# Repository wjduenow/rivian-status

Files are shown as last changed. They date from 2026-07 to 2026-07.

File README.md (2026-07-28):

# rivian-status

A small, headless **desk light that shows your Rivian's charge status at a glance.** An
ESP32-S3 polls your Rivian over WiFi (via the unofficial cloud API, read-only) and renders
charge level, charging activity, low-range warnings, and connection health onto an 8-pixel
WS2812 LED strip. No screen — everything (Rivian login incl. MFA, WiFi, settings) is set up in
a browser. It lives behind a 3D-printed enclosure and runs off USB-C.

> **Unofficial & read-only.** Rivian publishes no public API; this reverse-engineers the app's
> cloud GraphQL endpoint for *read-only telemetry* (no vehicle commands, no crypto). Endpoints
> can change without notice. See [`research/`](research/). Not affiliated with Rivian.

---

## What it does

- Reads your Rivian's **charge %, charge target, range, charging state, and plug state** every
  30 s (`getVehicleState`), with exponential backoff on errors.
- Shows it on the **LED meter** (below) — readable across the room, no screen.
- Serves a tiny **web UI** for status, Rivian login (email + password + MFA/OTP), WiFi, and
  settings (low-range threshold, LED brightness, device name).
- Provisions WiFi via a **SoftAP captive portal** on first boot, and supports **wireless OTA**
  firmware updates after that. Only session tokens are stored (never your password).

## Build one from scratch

Start to finish on a brand-new board. The electronics and setup take about half an hour; the case
print is a few hours on its own, so start that first if you're printing one.

**1. Get the parts.** A [Seeed XIAO ESP32-S3](#parts), an 8-pixel WS2812 stick, a ~330 Ω resistor
and a USB-C supply. Full list with links in [Parts](#parts).

> ⚠️ **Plug the external U.FL antenna in.** The XIAO's WiFi is unusable without it, and the
> failure looks exactly like a wrong WiFi password — this wastes an afternoon if you don't know it.

**2. Print the case** and wire the stick to the board — [enclosure](#the-enclosure-case) and
[wiring](#wiring). You can do this after step 3 if you'd rather see it running on the bench first.

**3. Flash it the first time, over USB.** Plug the board into a computer — it shows up as a USB
serial port (`303A:1001`). Pick **one** of these; after this first flash everything is wireless.

Wireless (OTA) can't do the first flash: a factory-fresh board has no bootloader, and OTA replaces
only the app. So the first flash must write the whole layout over USB — which is exactly what the
merged image below is.

<details open>
<summary><b>Option A — flash the prebuilt image (no toolchain)</b></summary>

Download **`firmware-status-full.bin`** from the
[latest release](https://github.com/wjduenow/rivian-status/releases/latest) — a single
full-flash image (bootloader + partition table + app) built and published by CI.

- **In a browser (easiest):** open the [ESP web flasher](https://espressif.github.io/esptool-js/),
  Connect, set the offset to **`0x0`**, choose the file, and Program. Works in Chrome/Edge over
  WebSerial — no install.
- **From a terminal:**
  ```bash
  pip install esptool
  esptool.py --chip esp32s3 write_flash 0x0 firmware-status-full.bin
  ```

The build published this way carries no baked-in secrets, so it comes up in first-boot setup mode
(next step) — and its wireless-flash listener has no password, so keep it on a network you trust.
</details>

<details>
<summary><b>Option B — build from source</b></summary>

Gives you a build you can set an OTA password on, and is the path for development.

```bash
pip install platformio                                    # if you don't have it
git clone https://github.com/wjduenow/rivian-status && cd rivian-status
pio run -e phase3 -t upload --upload-port /dev/ttyACM0    # or COMx / /dev/cu.usbmodem*
```

PlatformIO usually finds the port on its own, so you can drop `--upload-port`. You do **not** need
to create `include/secrets.h` — omitting it is the supported path, and it's how the release image
above is built. See [Building & flashing](#building--flashing-developer-reference) for details.
</details>

**4. Join it to your WiFi.** On first boot it has no credentials, so it raises its own hotspot:

- Join the open network **`rivian-status-setup`** from a phone or laptop.
- A setup page opens (or browse to `http://192.168.4.1/`). Pick your network, enter the password,
  optionally rename the device, and hit **Join**.
- It reboots onto your WiFi. The hotspot disappears.

**5. Sign in to Rivian.** Browse to **`http://rivian-status.local/`** (or its IP — check your
router if `.local` doesn't resolve, which is common on Windows/WSL). Open **Login**, enter your
Rivian email and password, then the MFA code that arrives **by email**. Only the session token is
stored, never your password.

**6. Done — it starts polling.** The meter comes alive within 30 seconds. On **Config**, set your
[mounting orientation](#mounting-orientation) so the meter fills the right way for how you hung it,
plus the low-range threshold and LED brightness. Turn on
[automatic updates](#firmware-updates) and it keeps itself current from then on.

**Troubleshooting the first boot:** if no hotspot appears, the board is probably already joined to
a network (check your router) — or the antenna isn't connected. If the LEDs stay dark, re-check the
data line on `D10` and that the stick's 5 V comes from the `5V` pin, not `3V3`.

## The LED indicator

The **whole strip is one meter**, filled by **charge % ÷ your charge target** (so "full" = you
hit your set charge limit, e.g. 70 %, not 100 %):

| State | Strip shows |
|---|---|
| **Charging** | meter in place; the **closest empty pixel slow-pulses green** (the cell filling), climbing as it charges |
| **Not charging, range OK** | meter: **green** filled up to charge level, **white** for the rest |
| **Not charging, range below your threshold** | **all pixels flash red** (low-range / "go plug in" alert) |
| **At / above target** | **all green** |
| **Link down** (offline / needs login) | **pixel 0 pulses red**, rest off |
| **OTA update running** | whole strip = a **blue progress bar** |

Brightness is adjustable on the config page. The status web page also shows a live **preview**
of the strip below the data table.

### Mounting orientation

The light is a **meter**, and where you can hang it depends on where the power is — so which end
reads as "the top" isn't fixed. The config page lets you say **where the plug comes out**
(bottom / left / top / right, as four little diagrams), and the firmware rotates the meter to
suit. The rule it keeps is:

> the meter always fills toward the **top** when it ends up vertical, and toward the **right**
> when it ends up sideways.

So you can mount it whichever way the outlet allows and it still reads the same. Two extra
settings pin it down completely:

- **Enclosure** — v1's bar runs *across* the case, v2's runs *up-down*, so the same quarter turn
  lands them on different axes. Set once per unit.
- **"Meter fills the wrong way"** — which end of the LED stick is pixel 0 depends on how yours
  was wired, so if the meter drains backwards, tick this and it's fixed.

Changes apply on the next LED frame — no reboot.

## The web interface

Everything is configured in a browser — no app. The device serves three pages (plus a WiFi
setup portal on first boot):

| Status (`/`) | Login (`/login`) | Config (`/config`) |
|:---:|:---:|:---:|
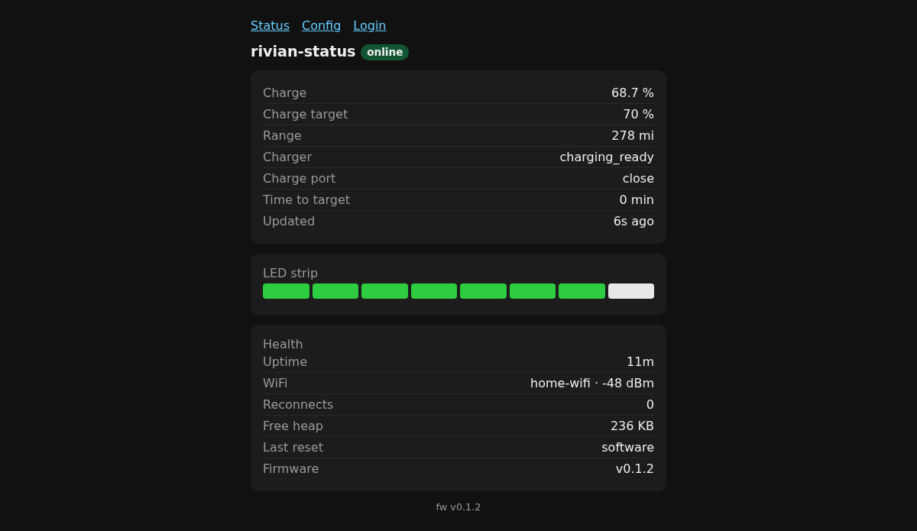
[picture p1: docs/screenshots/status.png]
Status page
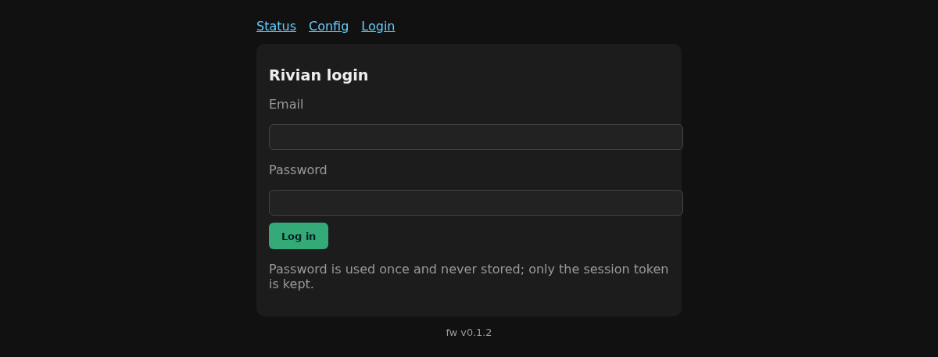
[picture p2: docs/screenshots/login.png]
Login page
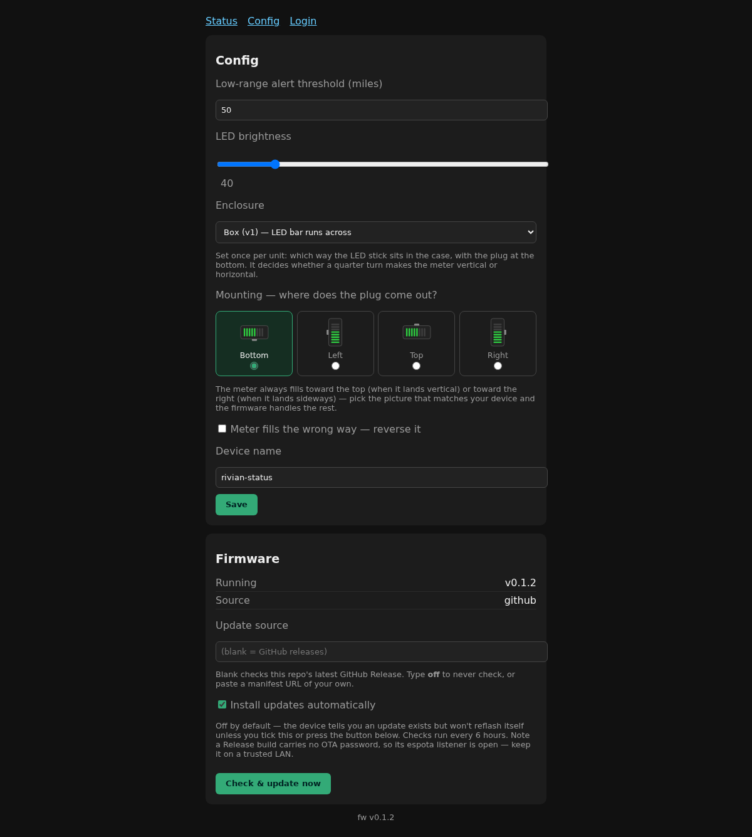
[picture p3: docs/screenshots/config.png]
Config page
|  |  |  |

- **Status** — live charge %, target, range, charger/plug state, a preview of the LED strip, and a
  **health** readout (uptime, signal, WiFi reconnects, free heap, last reset cause, firmware
  version). The health numbers are what tell you whether a unit that's been up for weeks is
  actually healthy or quietly flapping.
- **Login** — one-time Rivian sign-in (email + password, then the emailed MFA code); only the
  session token is stored, never the password.
- **Config** — low-range alert threshold, LED brightness,
  [mounting orientation](#mounting-orientation), device name, and
  [firmware updates](#firmware-updates).

## Firmware updates

The device can update itself. It checks for a newer release at boot and every 6 hours, and either
tells you one is available or installs it — your choice:

- **Update source** — blank checks this repo's latest GitHub Release. Type `off` to never check, or
  paste your own manifest URL.
- **Install updates automatically** — off by default, so out of the box it reports an update but
  waits for you to press **Check & update now**. Tick it and the device keeps itself current
  unattended.

It only ever installs a *strictly newer* version, so it can't flip-flop between builds or downgrade
a hand-flashed development build. A failed or interrupted download leaves the running firmware
untouched — the new image goes into a second flash slot and is only booted once it's complete. The
LED strip shows a blue progress bar while it installs.

> **Note:** release binaries are built without any secrets, which means they carry **no OTA
> password** — the wireless-flash listener on such a unit is unauthenticated. Keep it on a trusted
> network, or build and flash your own binary.

You can still push firmware from a laptop over WiFi at any time (`espota`), which is what
development builds use.

## Parts

| Part | Notes | Link |
|---|---|---|
| **Seeed Studio XIAO ESP32-S3** | the controller. **The included external U.FL antenna must be plugged in** or WiFi fails. | [seeedstudio.com](https://www.seeedstudio.com/XIAO-ESP32S3-p-5627.html) |
| **8-pixel WS2812 / NeoPixel stick** | bare stick, no onboard controller (the XIAO drives it). Measured ~51.5 × 10 mm. | [Adafruit NeoPixel Stick 8](https://www.adafruit.com/product/1426) or any generic 8-bit WS2812 stick |
| **~330 Ω resistor** | series resistor on the LED data line (¼ W, 220–470 Ω all fine) | any |
| **2× M3 × 6 screws** | mount the LED stick to its posts (Ø3.75 holes) | self-tapping / thread-forming M3 |
| **4× M3 × 8 screws** | fasten the lid (countersunk) | self-tapping M3 |
| *(v1)* **USB-C cable + 5 V supply** | permanent power (the strip is powered from USB VBUS) | any |
| *(v2)* **Nekmit Ultra-Thin flat USB-C wall charger** | v2 only — the case press-fits over it and it powers the XIAO over USB-C (via a USB-A→USB-C pigtail). 43.18 × 50.80 × 20.32 mm — the cavity is sized to it. | Nekmit Ultra-Thin flat charger (or any ~43 × 51 × 20 mm flat wall charger) |
| *(v2)* **USB-A → USB-C low-profile pigtail** | v2 only — charger's bottom port → XIAO USB-C, coiled in the skirt | right-angle / 180° ribbon |
| **3D-printed case** | **two versions** — v1 desk box (shell + lid) or v2 wall-charger slip case (case + cover) — see below | print it yourself |
| *(optional)* 470–1000 µF cap | across the strip's 5V↔GND if pixel 0 flickers on power-up | any |

> **Battery note:** as wired, the strip only has power over **USB** (its 5 V comes from the
> XIAO's USB-VBUS pin). Running the strip on battery needs an added boost module — see the
> decision in [`research/battery-power.md`](research/battery-power.md).

## The enclosure (case)

There are **two case versions** — both drive the same board and are parametric (Python +
trimesh, regenerated in the `img23d` conda env). Pick one:

### v1 — desk box (`hardware/status-light/box/`)

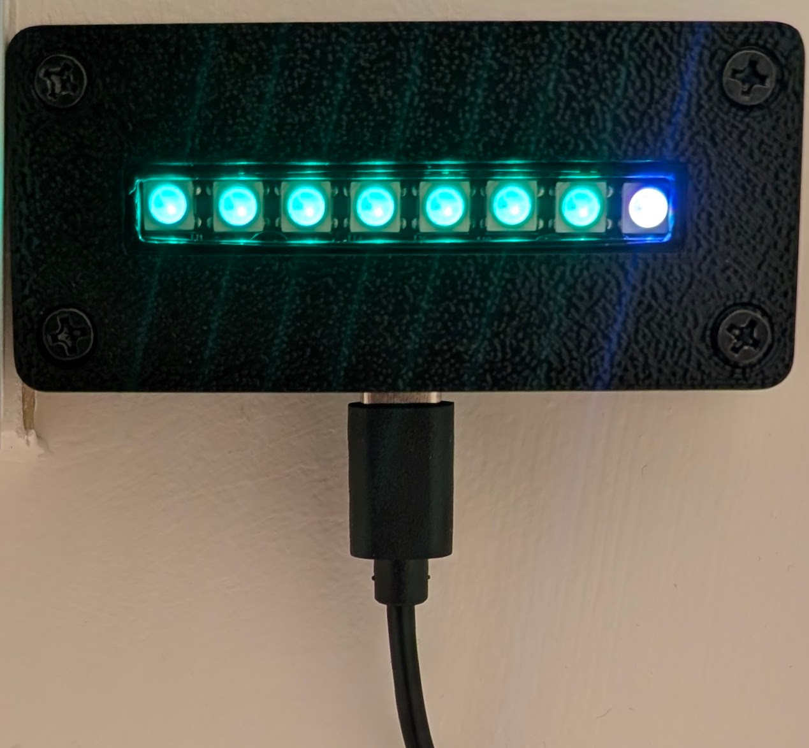
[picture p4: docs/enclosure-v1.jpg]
The v1 enclosure, wall-mounted and running


*A built v1 unit on the wall, live: 7 green + 1 white = one cell short of the charge target.
The plug exits the bottom, so the meter fills left→right.*

A "top-bar" box: the XIAO lies flat on the floor of the shell and the LED stick screws onto two
posts **above** it, LEDs facing up through a window in the lid. USB-C exits the back wall.

Despite the name it wall-mounts nicely too (above) — lay it flat against the wall with the lid
facing out and the back-wall USB-C exit points straight down. That puts the LED bar horizontal;
set **Enclosure = Box (v1)** and **plug = Bottom** on the config page and it reads left→right.

Despite the name it wall-mounts nicely too (above) — lay it flat against the wall with the lid
facing out and the back-wall USB-C exit points straight down. That puts the LED bar horizontal;
set **Enclosure = Box (v1)** and **plug = Bottom** on the config page and it reads left→right.

- **Print these:** [`box/shell.stl`](hardware/status-light/box/shell.stl) +
  [`box/lid.stl`](hardware/status-light/box/lid.stl) — ~75 × 34 × 16 mm.
- Print the lid in **translucent/natural filament** (the LEDs glow through the window), or back
  the window slot with a strip of diffusion film.

### v2 — wall-charger slip case (`hardware/status-light/box-v2/`)

| Front (mounted, live) | Side (profile) |
|:---:|:---:|
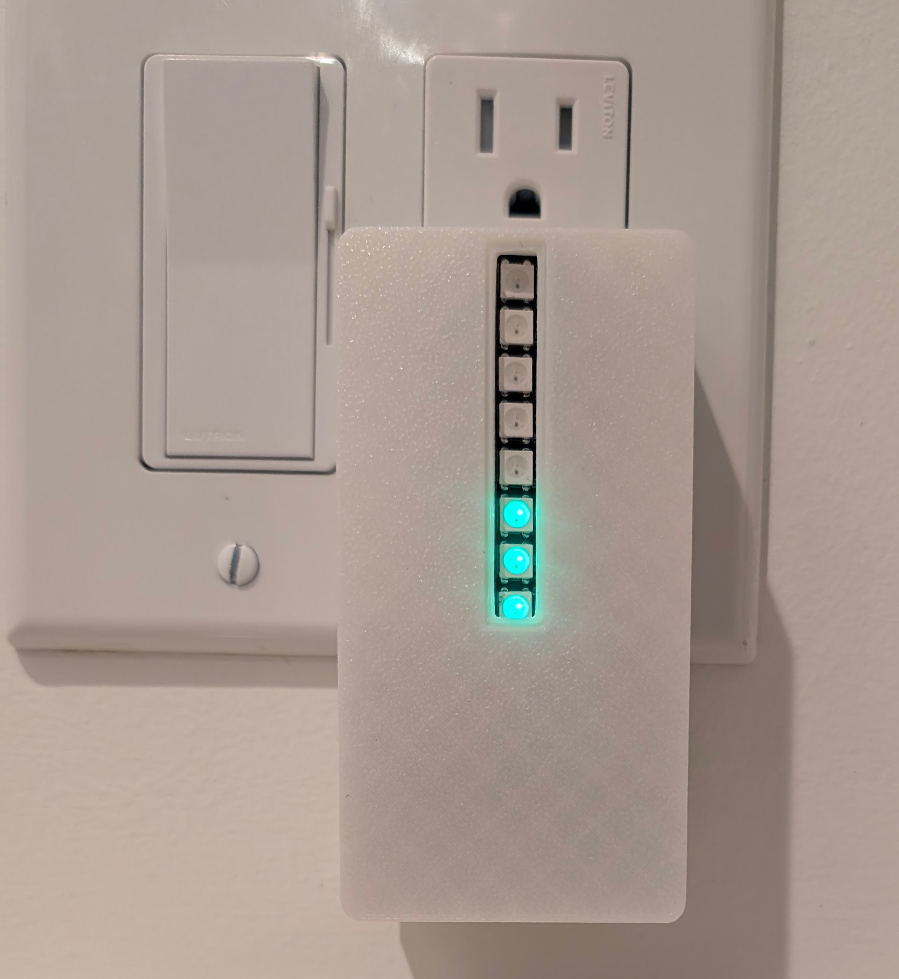
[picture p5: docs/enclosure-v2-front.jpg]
The v2 enclosure, wall-mounted and running
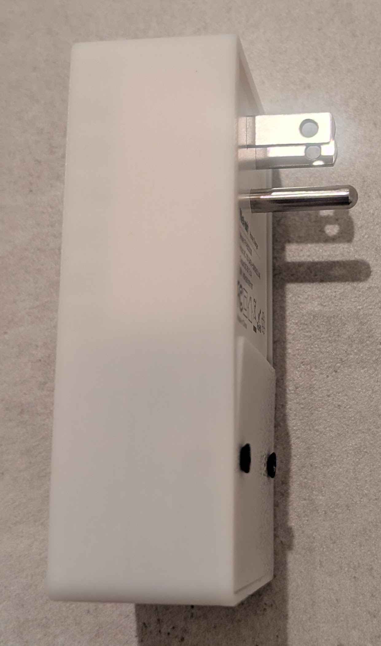
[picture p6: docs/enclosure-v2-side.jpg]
The v2 enclosure in profile
|  |  |

*A built v2 unit press-fit over the wall charger, live — the LED meter shows through the front
window. Right: the side profile, protruding ~29 mm from the wall, with the charger's AC prongs
exiting the open back straight into the outlet.*

A one-piece shell that **press-fits over a Nekmit Ultra-Thin flat USB wall charger** — the
charger is the mechanical *and* power anchor. It plugs into the wall, its AC prongs exit the
**open back**, and the case snaps on over it. The LED stick shows **out the front**; the XIAO
rests in a lower skirt, powered by a **USB-C pigtail** off the charger; a separate screw-on
cover closes the skirt.

- **Print these:** [`box-v2/case.stl`](hardware/status-light/box-v2/case.stl) +
  [`box-v2/cover.stl`](hardware/status-light/box-v2/cover.stl) — protrudes ~29 mm from the wall.
- Full parts list (incl. the charger + pigtail), build steps, and design notes:
  [`hardware/status-light/box-v2/README.md`](hardware/status-light/box-v2/README.md).

Every dimension and how to regenerate the STLs lives in each version's folder; the v1 bill of
dimensions is in [`box/MEASUREMENTS.md`](hardware/status-light/box/MEASUREMENTS.md), the v2
design notes in [`box-v2/NOTES.md`](hardware/status-light/box-v2/NOTES.md), and the shared
board/spec provenance in [`hardware/status-light/board_spec.md`](hardware/status-light/board_spec.md).

## Wiring

Data on **D10 / GPIO9**; power from the XIAO's **`5V`** pin (USB VBUS). Single supply — no
external PSU.

```
   XIAO ESP32-S3                         8-pixel WS2812 stick
   ┌───────[ USB-C ]───────┐
 5V│ ●───────────────────────────────────────►  5V
GND│ ●───────────────────────────────────────►  GND
D10│ ●──[ ~330 Ω ]────────────────────────────►  DIN
   └───────────────────────┘
```

- **DIN** ← `D10` (GPIO9) through the **~330 Ω** series resistor. GPIO9 is a plain output pin
  (not a strapping/USB pin), safe to drive at boot.
- **5V** ← the XIAO **`5V`** pin (USB VBUS passthrough — present only on USB power).
- Keep the LED-stick wires short; they solder to the stick's end pads and run down to the XIAO.
- The external **U.FL antenna** must be connected or WiFi will fail (looks like a bad password).

## Building & flashing (developer reference)

Setting one up for the first time? Use [Build one from scratch](#build-one-from-scratch) above —
this section is the command reference behind it.

Firmware is PlatformIO (Arduino framework). The shipped app is the **`phase3`** env; the others are
diagnostic harnesses.

| env | what it is |
|---|---|
| **`phase3`** | **the appliance** — web UI, poll task, WiFi provisioning, OTA, LEDs |
| `phase3-ota` | same binary, uploaded wirelessly instead of over USB |
| `phase1` / `phase2` | serial-only auth and poll-loop harnesses; these *require* `include/secrets.h` |
| `phase6-ledtest` | standalone WS2812 wiring smoke-test on `D10` |

```bash
pio run -e phase3                                        # build
pio run -e phase3 -t upload --upload-port /dev/ttyACM0   # USB flash (bootloader + table + app)
```
Over the air afterwards — packaged as the **`/ota`** skill:
```bash
OTA_PASSWORD=<pw> pio run -e phase3-ota -t upload --upload-port <device-ip>
```

A full USB flash writes four images; PlatformIO handles the offsets for you
(`0x0` bootloader, `0x8000` partition table, `0xe000` boot_app0, `0x10000` app). OTA replaces only
the last of these.

Each Release publishes two assets, both built by CI (`.github/workflows/firmware.yml`):

| asset | what it is | flash how |
|---|---|---|
| `firmware-status.bin` | the app image (`0x10000`) alone | OTA / `pio run -e phase3-ota`; also what the device pulls for auto-update |
| `firmware-status-full.bin` | all four images merged into one, flashable at `0x0` | a first flash of a blank board over USB (see [Build one from scratch](#build-one-from-scratch)) |

The merged image is only for a cold USB flash — never feed it to OTA, which writes a single app
slot and would flash the bootloader header into it. `manifest.json` deliberately lists only the app
image for exactly that reason.

`include/secrets.h` is **optional** and gitignored (template: `include/secrets.h.example`). `phase3` builds
fine without it — that's how release binaries are built, and it's what keeps the setup portal and
browser login working. It's only needed for the phase1/phase2 serial harnesses, a compile-time WiFi
fallback, or setting an OTA password.

Full flash/serial/OTA details (incl. the WSL usbipd workflow) are in
[`CLAUDE.md`](CLAUDE.md); the design rationale is in
[`plans/01-rivian-status-plan.md`](plans/01-rivian-status-plan.md).

## How the codebase works

An ESP32-S3 firmware in `src/`, split into focused modules. The **poll loop runs in its own
FreeRTOS task**; web handlers run in `loop()`; mutexes guard the shared TLS client and the
telemetry snapshot.

| Module | Responsibility |
|---|---|
| `rivian_api.{h,cpp}` | **The only file that knows Rivian's URLs/headers/GraphQL.** Login (CSRF → login → OTP), `getVehicleState`, session persistence to NVS (reused on boot — no re-login on reflash). |
| `webserver.{h,cpp}` | WebServer:80 (status / login / config pages) **+ the background poll task** + the mutex-guarded status snapshot. Exposes `ledState()` for the LEDs. |
| `leds.{h,cpp}` | The LED **meter** (FastLED on D10/GPIO9). Maps the snapshot → the strip; brightness-capped; blue OTA cue. All Rivian enum reads centralized here. |
| `settings.{h,cpp}` | NVS-backed config: low-range threshold (miles), LED brightness, device name (= hostname), WiFi creds. |
| `net_wifi.{h,cpp}` | WiFi connect + runtime creds + the SoftAP provisioning portal. |
| `net_ota.{h,cpp}` | ArduinoOTA as `<device-name>.local` (wireless updates). |
| `main.cpp` | Orchestration, split by build flag: `PHASE1_SMOKE_TEST` / `PHASE2_POLL_LOOP` / `PHASE3_WEBAPP`. |

**Build envs:** `phase1`/`phase2` are serial-only diagnostic harnesses; **`phase3` is the shipped
app** (incl. LEDs); `phase3-ota` is the wireless upload; `phase6-ledtest` is a standalone WS2812
wiring smoke-test.

## Repo layout

```
src/                firmware modules (above)
plans/01-…md        design source of truth (architecture, LED map, wiring, phasing)
research/           evidence base: the Rivian API protocol + the battery-power decision
hardware/           the 3D-printed enclosure (parametric trimesh CAD + STLs + measurements)
.claude/skills/ota/ the /ota wireless-flash skill
CLAUDE.md           build/flash/OTA commands + the WSL serial workflow + API facts
```

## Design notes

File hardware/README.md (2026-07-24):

# hardware/ — rivian-status physical build

3D-printed enclosure for the headless Rivian status light (XIAO ESP32-S3 + 8-pixel WS2812
stick). Modelled the same way as the sibling **[sonos-nest](../../sonos-nest/hardware)**
project: a Python CSG toolchain (**trimesh + manifold3d**, not OpenSCAD), one shared
`*_params.py` per part, `build_*.py` generators → `.stl`, and a `render_preview.py`. The
toolchain lives in the `img23d` conda env (`conda run -n img23d python build_all.py`).

Per-version dimensions live in each case folder: **[status-light/box/MEASUREMENTS.md](status-light/box/MEASUREMENTS.md)**
(v1, one table) and **[status-light/box-v2/](status-light/box-v2/)** (v2 — numbers in
`case_params.py`, decisions in `NOTES.md`).

| unit | board | enclosures |
|---|---|---|
| **[status-light/](status-light/)** | Seeed XIAO ESP32-S3 + generic 8-bit WS2812 stick | **[box/](status-light/box/)** — v1 top-bar desk enclosure (shell + lid) · **[box-v2/](status-light/box-v2/)** — v2 slip case over a flat wall charger (case + cover) |

## Conventions
- Board outlines/holes come from **verified vendor CAD** (Seeed's STEP); connector
  positions not in the CAD are estimated from photos/datasheets and flagged **⚠️VERIFY**
  in the part's `board_spec.md` — caliper-check before a final print.
- Keep `hardware/` commits **separate from firmware**; this is user-owned work.
- The `img23d` env also has `ezdxf` + `cascadio` (added here) for reading vendor DXF/STEP.

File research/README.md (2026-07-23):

# research/ — Rivian status project evidence base

Primary research gathered 2026-07-17 (Claude Code deep-research + a focused protocol dig).
This is the **raw evidence** behind the design decisions in `plans/01-rivian-status-plan.md`.
When something in the plan needs justification — or when the unofficial API breaks and you
need to re-derive it — start here.

> **Everything about Rivian's API is unofficial and reverse-engineered.** Rivian publishes no
> public developer API. Treat every endpoint/header/field below as "true as of 2026-07-17,
> may change without notice." The maintained community client (`bretterer/rivian-python-client`)
> is the closest thing to a spec — diff against its upstream if things stop working.

## Contents

- **`rivian-cloud-api-protocol.md`** — the concrete protocol: endpoints, the 4-step auth
  handshake (CSRF → login → OTP → re-CSRF), exact GraphQL mutations/queries, the header matrix,
  telemetry fields, TLS/cert facts, and ESP32 feasibility notes. *This is the file you code
  against.* Sourced from `bretterer/rivian-python-client` `main` + RivDocs.
- **`deep-research-report.md`** — the broader survey: verified findings (with confidence +
  vote tallies), refuted claims (things that sound true but failed verification), open
  questions, and the full source list with quality ratings. Answers "what are ALL the options
  and which did we rule out and why."
- **`battery-power.md`** — decision (2026-07-22, deep-research): can the LED strip run on
  battery? No mainstream ESP32-S3 board has a battery-fed 5 V boost, so it's XIAO + an external
  PowerBoost module if pursued; always-on WiFi runtime is short, so the shipped appliance stays
  USB-powered. Board comparison + runtime math + wiring inside.

## The decision, in one paragraph

Use Rivian's **cloud GraphQL App API** directly from the ESP32-S3 (read-only telemetry).
It's **ruled IN**: the endpoint is behind AWS CloudFront (no bot/JS challenge), auth is plain
JSON POSTs, and with no display the ESP32 has ample heap for TLS. **Local/BLE is ruled OUT**
(needs cloud-bootstrapped ECDH phone-key enrollment + HMAC signing, no turnkey ESP32 project,
and probably no live charge telemetry anyway). Read-only means **no crypto at all** — just
login + `getVehicleState`. See the plan for the full build.

## Key facts future sessions keep needing

- **Endpoint:** `POST https://rivian.com/api/gql/gateway/graphql`
- **Auth:** CreateCSRFToken → Login → (LoginWithOTP if MFA) → `userSessionToken`. **No refresh
  mutation** — on expiry, re-run CreateCSRFToken reusing `u-sess`; full re-login only as last resort.
- **Headers:** base (`User-Agent: RivianApp/707...`, `Apollographql-Client-Name:
  com.rivian.ios.consumer-apollo-ios`, self-gen `dc-cid`) + `Csrf-Token`/`A-Sess`/`U-Sess`
  per the matrix. **No `dc-sess` header exists** (older-API conflation).
- **Telemetry fields:** `batteryLevel`, `chargerState`, `chargePortState`, `distanceToEmpty`
  — each returns `{timeStamp, value}`. Request only the subset you need.
- **TLS:** Amazon Root CA 1, **pin the root not the leaf** (leaf rotates ~200 days).
- **Cadence:** poll 30 s, exponential backoff capped at 900 s. API rate-limits (`RATE_LIMIT` code).
- **UNCONFIRMED:** `distanceToEmpty` units (km vs miles) and exact token lifetimes. Verify units
  live before trusting the low-range threshold.

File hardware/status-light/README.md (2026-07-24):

# status-light — the `rivian-status` enclosures

The headless Rivian charge/range light: a **Seeed XIAO ESP32-S3** driving an **8-pixel
WS2812 stick** that shows the pixels out the front. There are **two enclosure versions** —
both drive the same board, and both are generated by the same Python CSG toolchain.

| version | form factor | printed parts | size |
|---|---|---|---|
| **[box/](box/)** (v1) | desk-standing "top-bar" box; pixels face **up** out a lid window | `shell.stl` + `lid.stl` | 75.3 × 34.3 × **16** mm |
| **[box-v2/](box-v2/)** (v2) | **slip case that press-fits over a Nekmit flat USB wall charger**; pixels face **out** the front | `case.stl` + `cover.stl` | protrudes **29.1** mm from the wall |

### v1 — `box/` (desk light)
A two-part screwed box. The XIAO lies flat on the floor; the WS2812 stick is stacked **above**
it on two posts with the LEDs facing **up** through a window in the lid. USB-C exits the back
wall; the U.FL antenna coils inside. See **[box/README.md](box/README.md)**; every v1 dimension
is tabulated in **[box/MEASUREMENTS.md](box/MEASUREMENTS.md)**.

### v2 — `box-v2/` (wall-charger case)
A one-piece slip shell that **press-fits over a Nekmit Ultra-Thin flat wall charger** — the
charger is the mechanical *and* electrical anchor (it plugs into the wall; AC prongs exit the
**open back**; an inward snap lip retains it). The WS2812 stick mounts **vertically** on the
front behind the window, screwed from the open back into hidden bosses. The XIAO rests flat on
the lower **skirt** floor, powered by a USB-A→USB-C pigtail off the charger. The skirt's
wall-facing back is a **separate screw-on cover** (so the body prints open-backed, no supports).
See **[box-v2/README.md](box-v2/README.md)** for the full parts list + build, and
**[box-v2/NOTES.md](box-v2/NOTES.md)** for the design decisions + rationale. Two printed parts.

## Shared references
| | |
|---|---|
| **[board_spec.md](board_spec.md)** | every XIAO dimension **both** boxes use + where it came from (the "no mounting holes" finding lives here) |
| **[ref/](ref/)** | vendor CAD: `XIAO-ESP32S3 v2.step` + the measured proof renders |

## Conventions (shared with `../../../sonos-nest/hardware`)
- Python CSG toolchain (trimesh + manifold3d), the `img23d` conda env — **not** OpenSCAD.
- Every dimension lives in a `*_params.py`; builders `assert` their own clearances.
- Board numbers come from vendor CAD; anything estimated is flagged **⚠️VERIFY** and
  caliper-checked before a final print.
- Keep `hardware/` commits separate from firmware — this is user-owned mechanical work.

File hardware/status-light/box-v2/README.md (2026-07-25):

# box-v2 — wall-charger slip case

A **v2 enclosure** for the rivian-status light that ditches the desk box and instead
**press-fits over a Nekmit Ultra-Thin flat USB wall charger**. The charger is the mechanical
*and* electrical anchor: it plugs into the wall, its AC prongs protrude out the **open back**,
and this shell slides on from behind and snaps in place. **Two printed parts** (`case` +
skirt-back `cover`) + a stick-on diffuser film.

```
conda run -n img23d python build_all.py      # -> case.stl + cover.stl
conda run -n img23d python render_preview.py # -> render_preview.png
```

Same toolchain as `../box` (trimesh CSG, mm, every number provenance-commented in
`case_params.py`, clearances **ASSERTED** in `build_case.check_clearances()` so an illegal
edit fails loudly instead of writing a broken STL).

**Design decisions + rationale** (why it's ~30 mm deep, why hidden M3 forces that, the skirt /
cover choices): [`NOTES.md`](NOTES.md). The shared XIAO board spec is `../board_spec.md`.

## Parts (bill of materials)
| # | part | notes |
|---|---|---|
| 1 | **USB-C wall charger — Nekmit Ultra-Thin flat, 45.1 × 51.6 × 20.32 mm** | the mechanical + power anchor the case slips over; powers the XIAO over USB-C |
| 2 | **Case** — `case.stl` (FDM, front-face-down) | main body; press-fits over the charger |
| 3 | **Cover** — `cover.stl` (FDM, flat) | screw-on skirt back |
| 1 | Seeed **XIAO ESP32-S3** | rests flat on the skirt floor |
| 1 | **8-px WS2812 stick** (v1 board, 51.5 × 10 mm) | vertical, behind the front window |
| 1 | **USB-A → USB-C low-profile pigtail** | charger's bottom port → XIAO USB-C (skirt loop) |
| 2 | **M3 × 5** self-tapping screws | hold the LED stick (hidden, from the open back) |
| 2 | **M3 × 8** self-tapping screws | hold the cover into its side-wall bosses |
| 1 | diffuser film / thin acrylic strip | over the window (outer rebate) |

## Frame
`+X` width (horizontal on the wall) · `+Y` up (vertical) · `+Z` out (wall → room).
Origin: X centred on the charger; `y=0` at the charger's bottom face; `z=0` at the open back rim.

## Layout (locked with the user)
- **8-px WS2812 stick, re-used from v1**, mounted **vertically** on the front interior face.
  It drops into a front **pocket** (domes → `+Z` out the window) and is **screwed** through its
  two Ø3.75 holes to bosses molded off the front wall. The **M3 self-tappers go in from the
  OPEN BACK** — heads hidden from the front, sitting in a relief gap behind the PCB — and their
  pilots thread up into the **solid 3.2 mm front wall** (not thin necked walls), capped by
  **1.6 mm** of wall so the pilots stay hidden from the front. Recommended screw: **M3×5**
  (~3.6 mm thread engagement). The window ledge is a second, backup stop.
- **XIAO ESP32-S3 rests flat on the skirt floor** (no tray) — gravity + the wires to the stick
  hold it; the USB-A→USB-C pigtail from the charger's bottom port loops down to it. The stick
  pocket, charger cavity and skirt share one open interior, so wiring routes freely between them.
- **Skirt back = a separate screw-on `cover`.** The main body prints **fully open-backed** (no
  supports in a blind pocket); the cover is a **plain plate** that drops into a flush rebate and
  is held by **2 M3×8** self-tappers, countersunk on the wall-facing face, into gusseted
  side-wall bosses. It closes the XIAO bay and stops the board falling out the back.
- **Retention:** an inward **snap lip** around the back rim catches behind the charger's rear
  edge (blueprint §3).

## Key numbers (all in `case_params.py`)
| | mm | source |
|---|---|---|
| Charger (W×H×D) | 45.1 × 51.6 × 20.32 | W×H calipered 2026-07-24; D blueprint |
| Slip-fit cavity | 45.70 × 52.20 × 20.72 | +0.6/+0.6/+0.4 |
| **Outer envelope (W×H×D)** | **50.1 × 97.6 × 30.1** | derived |
| Protrusion from wall | **30.1** | derived |
| Wall / front | 2.2 / 3.2 | choice (front thickened to hide the screw-post pilots) |
| Skirt (interior height) | 41.0 | +24 for the USB cable/plug (17 → 29 → 41) |
| Window (X×Y) | 5.95 × 50.95 | over the emitter run |
| Stick screws | 2 × **M3×5** from the back, hidden | Ø5.0 bosses, ~3.6 mm grip |
| Head-relief gap / dome recess | 2.6 / 0.6 | behind the PCB / below the window |
| Skirt-back cover | plain plate, 2 × **M3×8** | flush rebate, gusseted bosses |
| Snap lip (inward × tall) | 1.2 × 2.0 | blueprint 1.0–1.5 |

## Deliberate deviations from the blueprint (documented, not accidents)
1. **Depth grows to ~30.1 mm** (blueprint said ~20.7 + wall). The blueprint assumed the
   charger touches the front wall, but the vertical LED stick sits **in front of** the charger
   (3.0 mm) **and is back-screwed**, needing a **2.6 mm relief gap** behind it for the hidden
   screw heads. So internal depth = charger + head gap + stick, plus a **3.2 mm front wall**
   (thickened from 2.2 to keep the screw-post pilots hidden).
2. **Skirt is 41 mm** (blueprint 15–18; grown 17 → 29 → 41 in two +12 bumps). Sized to clear the
   **USB cable/plug** hanging off the charger's bottom port. The XIAO lies flat on the floor
   (~5.5 mm tall) and doesn't set the height.

## Print orientation
Print **front-face-down** on the bed: the window is a flat bottom layer, the walls rise, and
the **whole back (charger region *and* skirt) ends up open on top** — no bridging over the big
front face, and **no supports in a blind skirt pocket** (that's why the skirt back is a separate
cover). The rear snap lip becomes a small inward overhang at the top; a chamfer or a few support
lines clean it up. The `cover` prints flat, csk-face up.

## Open items / next iteration
- **Stick thread engagement is modest (~3.6 mm).** Fine for a ~3 g static part, but if you
  want more grip, raise `DOME_RECESS` (lets the boss get taller, at a little more depth) or
  step to a longer screw. Print a boss test coupon — FDM self-tap holes want tuning.
- **XIAO is unretained sideways** — it just rests on the floor (per your call). Gravity + the
  stick wires + the back cover hold it; add a dab of foam if it rattles in transit.
- **Cover top edge** is now held only by the **2 side screws** + the flush rebate (the
  tongue-under-tab retention was removed as unhelpful). If the top ever bows outward, add a
  third screw or a small central boss rather than reintroducing the tabs.
- **First flash.** No external USB-C port by default — first flash the XIAO out of the case,
  then it's OTA over WiFi. Set `USB_SERVICE_SLOT = True` to cut a cabled-access slot in the
  skirt bottom.
- **Verify against the real charger + snap lip fit** with a print (FDM slip-fits and snap lips
  want a test coupon before committing the whole part).
- The **snap lip is a simple rectangular step** — tune `LIP_IN`/`LIP_H`/`LIP_CHAMFER` after a
  test fit.

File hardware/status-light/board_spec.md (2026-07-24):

# XIAO ESP32-S3 — mechanical spec (as used by the enclosures)

Every XIAO number the enclosures rely on, and exactly where it came from. Shared by **both**
case versions — `box/` (v1) and `box-v2/` (v2). Same discipline as
`../../../sonos-nest/hardware`: CAD-verified numbers are plain; anything estimated is
flagged **⚠️VERIFY**. Values are baked into each version's `case_params.py` — this file is
the paper trail.

## Sources (Seeed official)

Pulled from the Seeed wiki resource list for the XIAO ESP32-S3
(`wiki.seeedstudio.com/xiao_esp32s3_getting_started`):

| File | What | Kept where |
|---|---|---|
| `seeed-studio-xiao-esp32s3-3d_model.zip` → **`XIAO-ESP32S3 v2.step`** | vendor 3D CAD — the authority for outline, thickness, connector positions | committed to **`ref/`** |
| `XIAO_ESP32S3_v1.1_Dimensioning.dxf`, `TOP.dxf` | 2D fab drawings — cross-check + the bottom-copper view | render in **`ref/xiao_footprint_bottom.png`** |

The STEP was converted to a mesh with `cascadio` (STEP→glTF) and measured in `trimesh`,
in **mm**. In the STEP's own frame: X = board length, Z = board width, Y = thickness.
`ref/xiao_ortho_measured.png` is the orthographic proof render those numbers came off.

## The board (measured off the STEP)

| Dimension | Value | Provenance |
|---|---|---|
| PCB length (USB-C ↔ antenna) | **21.0 mm** | STEP `SOLID` X-span 20.955 |
| PCB width | **17.8 mm** | STEP `SOLID` Z-span 17.780 |
| PCB thickness | **1.25 mm** | STEP `SOLID` Y-span −0.25…1.00 (Seeed spec: 1.2) |
| Bottom side | **flat** — no tall components | STEP: overall Y-min = PCB back face |
| Tallest top component | **4.21 mm** above PCB back (the USB-C shell) | STEP `CHAMFER9` |
| RF shield height | 3.00 mm above PCB back | STEP `Shield` |

### USB-C (on the +X short end)
| | Value | Provenance |
|---|---|---|
| Overhang past the PCB edge | **1.53 mm** | STEP: connector X-max 13.809 vs PCB 12.282 |
| Shell width | **8.94 mm** | STEP Z-span |
| Aperture height | **3.26 mm** | STEP Y-span 4.20 minus the lip |
| Aperture centre above PCB **back** face | **2.36 mm** | STEP Y-centre 2.11, PCB back −0.25 |
| Centred on the board width? | **yes** | STEP USB Z-centre −6.12 ≈ PCB Z-centre −6.11 |

### U.FL external-antenna jack (on **top**, at the −X / antenna end)
CLAUDE.md is explicit: **this antenna must stay plugged in or WiFi dies**, so the box has
to leave room for the mated plug and let the pigtail escape.
| | Value | Provenance |
|---|---|---|
| Along the board length, from centre | **−6.95 mm** (toward −X) | STEP `U.FL-R-SMT` X-centre |
| Height above the PCB **top** face | **1.25 mm** (bare jack; a mated plug adds ~3) | STEP Y-top 2.25 − PCB top 1.00 |
| Offset from the width centreline | **4.73 mm** | STEP Z-centre −10.84 vs −6.11 |

## ⚠️ The XIAO has **no screw mounting holes**

Confirmed two ways: the STEP has no mounting bores (only the connectors + a shield can),
and the bottom-copper DXF (`ref/xiao_footprint_bottom.png`) shows only the two 7-pin
castellated rows plus **two Ø0.6 tooling holes** — no M2/M3 pads. XIAO boards are meant to
be retained by their pins or by the host enclosure.

**Consequence for the box:** the board is **not screwed down**. It drops onto four corner
standoffs inside a rib pocket, is pinned in X by the USB-C sitting in its port, and is
clamped from above by two pads on the lid. Wires are **hand-soldered directly to the pads**
(user-confirmed — no header, so the board back stays flat and lies flush on the standoffs).

## LED stick — measured by the user (generic bare 8-bit stick)

Not in any vendor CAD, so these are **caliper values** the user measured off the real part:

| Dimension | Value |
|---|---|
| Length | **51.5 mm** |
| Width (short edge) | **10 mm** |
| Total thickness incl. LEDs | **3.0 mm** → PCB **1.6** + domes **1.4** |
| Lit span (first→last LED centre) | **45 mm** (emitter extent ≈ 50 mm) |
| Mounting holes | **2**, Ø **3.75 mm**, at **±13.0 mm** along the length (26 mm apart) |
| LED square (emitter) | **4.75 mm** |
| Hole offset from the LED row | **4.5 mm** to one long edge (measured) |

From the board photo the holes are off to one long edge (by the Cx caps / pad column),
~¼ and ¾ along the length, **4.5 mm** off the LED row (`LED_HOLE_DY`). The box **screws
the stick down** onto two posts through those Ø3.75 holes (2× M3). The lid window spans the
full **50 mm emitter extent** (lit span + one emitter), and the LEDs sit **2 mm below the
case top** (`LED_BELOW_TOP`) so they read near the surface of the window slot.

## Note — USB-C exits the back wall

Because the stick is stacked over the board and the lid is screwed on, the board lies
front-to-back under the stick and **USB-C exits the back (+Y) wall, centred and proud**
(see `box/README.md` "Layout note"). An end-exit variant is a one-param change but needs
the board recessed ~5 mm.

The **U.FL antenna stays inside** the box by default (`ANT_EXIT = False`) — the jack keeps
its plug clearance and the pigtail coils in the open floor. Flip `ANT_EXIT = True` for a
front-wall exit slot if the in-box antenna underperforms.

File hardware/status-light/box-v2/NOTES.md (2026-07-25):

# box-v2 — design notes & decisions (for future sessions)

Why the v2 case is shaped the way it is. The *numbers* live in `case_params.py` (provenance-
commented) and the *build* in `README.md`; this file is the **reasoning** — the non-obvious
trade-offs, the decisions locked with the user, and the things a future session would otherwise
have to re-derive. Read alongside the repo `CLAUDE.md` and `../board_spec.md`.

## What it is (one line)
A one-piece slip shell that press-fits over a **Nekmit Ultra-Thin flat wall charger**
(45.1 × 51.6 × 20.32 mm; W×H calipered 2026-07-24, D from blueprint). The charger is the
mechanical **and** electrical anchor: it plugs
into the wall, AC prongs exit the **open back**, an inward snap lip retains it. LED stick shows
out the front; XIAO + pigtail live in a lower skirt; skirt back is a separate screw-on cover.

## Decisions locked with the user (don't silently revisit)
- **8-px WS2812 stick, re-used from v1** — *not* the "16-LED array" the original blueprint text
  mentioned. The firmware pixel map is 8 (plan §7).
- **Stick mounted VERTICALLY** on the front (charger face is portrait 51.6 tall; the 51.5 mm
  stick fits the height, not the 45.1 width).
- **XIAO rests flat on the skirt floor** — no tray/standoffs. Gravity + the wires to the stick
  hold it; the cover stops it falling out the back.
- **Skirt back = a SEPARATE screw-on cover** (not an integral wall) — so the body prints open-
  backed with no supports in a blind pocket.
- **Stick retention = hidden M3 screws from the open back** (user: "hidden back, but use M3").
  The front wall is **3.2 mm** and each pilot is capped by **1.6 mm** of solid wall so the posts
  don't show through the front (user asked to hide them; front thickened to suit).
- **Cover = plain screw-held plate.** An earlier tongue-under-corner-tab top retention was
  **removed** (user: "not helpful"); the 2 side screws + flush rebate hold the cover.

## The depth story (why it protrudes ~30 mm, not the blueprint's ~20.7)
The blueprint assumed the charger touches the front wall. It doesn't, for two stacked reasons —
**this is the #1 thing to understand before touching the Z stack:**
1. The vertical LED stick (3.0 mm: 1.6 PCB + 1.4 domes) sits **in front of** the charger.
2. The stick is **back-screwed**, so there's a **head-relief gap** (`STRIP_HEAD_RELIEF`, 2.6 mm)
   between the charger face and the stick's PCB back for the hidden screw heads.

So internal depth = charger (20.72 slip) + relief (2.6) + stick (3.0) → front wall interior at
~26.9, and with a **3.2 mm front wall** the outer face is ~30.1 mm. (`FRONT_T` was thickened
2.2 → 3.2 to keep the screw-post pilots hidden — see below.) `D_IN`/`OUT_D` in `case_params.py`
derive from exactly this chain.

### Why hidden-M3 forces the depth (the front-sandwich problem)
The stick is sandwiched between the charger (behind) and the window (front), so a screw boss
must go on **one** side and that dictates depth:
- **Hidden-back screw** ⟹ the boss it threads into must be on the **front-wall** side, and the
  screw head lands on the **charger** side → needs the relief gap (adds depth). We root the boss
  by boring its **pilot up into the solid 2.2 mm front wall** (not a thin necked pin through the
  Ø3.75 hole — that would leave ~0.5 mm walls and strip). Engagement ~3.4 mm → **M3×5**.
- A robust Ø5.5 boss *behind* the stick would instead need **front-face screws** (visible) and
  a pocket floor — even more depth. Rejected.
- Net: any positive stick screw here costs depth; hidden-back is the least-visible option and
  what the user chose. Thread grip is modest but fine for a ~3 g static part.

`DOME_RECESS` (0.6 mm) lets the LEDs sit a hair below the window (also a light baffle) and buys
a common screw length; raise it if you want more thread engagement (at a little more depth).

**Hiding the screw posts:** the blind pilots are bored up into the front wall and stop
`PILOT_WALL_MIN` short of the outer face. At the old 0.8 mm cap the posts showed through the
front, so `PILOT_WALL_MIN` is now **1.6 mm** and `FRONT_T` was raised 2.2 → 3.2 to keep ~3.6 mm
of thread engagement (cap = `PILOT_WALL_MIN` regardless of `FRONT_T`, so both had to move). Net
cost is ~1 mm more protrusion.

## XIAO in the skirt
- Lies **flat on the floor** (21 × 17.8 footprint on the X-Z plane, only ~5.5 mm tall in Y).
- **Skirt height (`SKIRT_H`) is 41 mm** — grown in two +12 bumps to make room for the
  **USB cable/plug** hanging off the charger's bottom port (user's call). It is NOT floored by
  the XIAO, which lies flat (~5.5 mm tall); don't shrink it below ~15 or the plug collides.
  (History: 24 mm when the XIAO had a front-wall tray → 17 once it moved to the floor → 29 → 41
  for cable room.)
- The stick pocket, charger cavity, and skirt share **one open interior** — wiring routes freely
  (no dedicated slot needed).
- **Not retained sideways** (user's call) — add foam if it rattles in transit. A molded snap tab
  is the clean follow-up if ever wanted.

## Skirt back cover
- Flush rebate + **2× M3×8** into **gusseted** side-wall bosses (posts alone can't root over the
  open cavity — they must merge with / rib to the perimeter walls).
- **Plain plate, no top retention.** An earlier version stepped the cover's top corners to a
  half-thickness tongue that tucked under two body tabs. The user found the tabs unhelpful, so
  they're **removed** — the 2 side screws + the flush rebate hold the cover. If the top ever
  bows out, add a third screw or a small central boss rather than bringing the tabs back.

## Print orientation
**Front-face-down** on the bed: window = flat bottom layer; walls rise; the **whole back (charger
region + skirt) is open at the top** → no bridge over the big front face, no supports in a blind
pocket (that's the whole reason the skirt back is a separate cover). The snap lip becomes a small
inward overhang at the top; chamfer or a few support lines clean it up. The `cover` prints flat.
(Removing the top tabs also removed the last small top-edge overhangs — nothing bridges now.)

## Charger caveat (verify before a final print)
The physical Nekmit is **dual USB-A output**; the XIAO is fed by a **USB-A→USB-C pigtail**. The
BOM lists it as the "USB-C wall charger" (the power the board sees is USB-C) but the cavity is
sized to the **Nekmit's body** (45.1 × 51.6 × 20.32). **If you swap to a charger with a native
USB-C port or different dimensions, re-measure and update `CHG_W/H/D`** — the whole slip fit,
snap lip, and skirt derive from those three numbers.

## Before committing a full print
1. **Print a test coupon first** — the slip fit (`FIT_W/H/D`), the snap lip (`LIP_*`), and the
   stick boss self-tap all want a cheap coupon before a ~multi-hour full print. FDM holes/fits
   print tight. Confirm the 1.6 mm pilot cap fully hides the posts in your filament while here.
2. Diffuser film over the window (outer rebate) or print in translucent filament.
3. First XIAO flash is done **out of the case** (then OTA over WiFi); set
   `USB_SERVICE_SLOT = True` if you want a cabled-access slot in the skirt bottom.

## Toolchain (same as `../box`)
`img23d` conda env, trimesh CSG. `case_params.py` (single source of truth, clearances ASSERTED
in `build_case.check_clearances()`) → `build_case.py` + `build_cover.py` → `case.stl` +
`cover.stl`. `render_preview.py` (2×2 overview).
`conda run -n img23d python build_all.py`.

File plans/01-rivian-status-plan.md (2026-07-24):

# 01 — rivian-status: a headless ESP32-S3 Rivian charge/range status light

**Board:** **Seeed Studio XIAO ESP32-S3** (ESP32-S3R8, 8 MB PSRAM / 8 MB flash, USB-C, no
display). **LEDs:** an **8-pixel WS2812/NeoPixel stick**, USB-powered from the board's `5V`
pin — no external supply (see §7 for the pixel map, wiring, and power budget).
**Goal:** an always-on desk/wall appliance that polls the owner's Rivian over WiFi and shows,
via lights: is it plugged in, is it charging, roughly how full, **whether current range is
below a configurable threshold**, and whether the link to Rivian is healthy. All setup —
Rivian login (incl. MFA), WiFi, and the range threshold — happens in a browser. No screen.

This is a **fresh standalone repo**. It does not need the Sonos control stack. It borrows a
few *patterns* (not the whole core) from the `sonos-nest` repo's plan 04 "sonos-button"
(the headless, browser-configured, one-appliance model): WiFi provisioning via SoftAP
captive portal, an embedded config web page, NVS-persisted settings, and ArduinoOTA.

> **Everything about Rivian's API here is unofficial and reverse-engineered.** Rivian
> publishes no public API. Endpoints, headers, and field names can change without notice.
> Centralize them (§8) so a break is a one-file fix. Sources are cited in §11.

---

## 1. Decisions (settled)

| Question | Decision |
|---|---|
| Data path | **Rivian cloud GraphQL App API** (the app's own endpoint). Ruled IN by research. |
| Local / BLE | **Ruled OUT.** Needs cloud-bootstrapped ECDH secp256r1 phone-key enrollment + HMAC signing; no turnkey ESP32 project; BLE likely won't even expose live charge telemetry. |
| Access mode | **Read-only telemetry.** No vehicle commands → **no HMAC / phone-key / BLE crypto** needed at all. |
| Auth | Rivian account email + password, MFA/OTP when enabled. Entered once via the web page. |
| Credential storage | **Store only session tokens + VIN in NVS. Never persist the password.** |
| Config surface | Small embedded web page (login, status, WiFi, range threshold). Single `WebServer`, one port. |
| WiFi provisioning | `secrets.h`/NVS first, **SoftAP captive portal fallback** (same as sonos-button plan 04). |
| Telemetry transport | **Polling `getVehicleState` query**, not the WebSocket subscription (WS is heavier on an MCU for no benefit here). |
| Poll cadence | **30 s**, exponential backoff on error capped at **900 s**. |
| Primary alert | **current range `< X`**, where X is configurable in the web page. |
| Board | **Seeed Studio XIAO ESP32-S3** (ESP32-S3R8, 8 MB PSRAM, USB-C). |
| LED hardware | **8-pixel WS2812/NeoPixel stick**, one pixel per indicator (§7). Data on `D10`/GPIO9; powered from the `5V` (USB VBUS) pin; single-supply via a firmware brightness cap. |

### Open decisions (defer, noted where relevant)
- ~~`distanceToEmpty` units~~ — **CONFIRMED 2026-07-21 (Phase 1, live vehicle): the API field is
  in KILOMETERS; the US app displays miles** (391 km API ≈ 244 mi app). Firmware converts km→mi;
  the web-page threshold X is entered in **miles** (§6).
- Whether the low-range light is **charging-aware** (steady = low & not charging, pulse = low
  but charging) or dead simple (low is low). Data for both is free. Lean charging-aware; decide
  in the LED phase (§10 phase 6).

---

## 2. Why the cloud path is feasible on the ESP32 (the research verdict)

- **AWS CloudFront, not Cloudflare.** `rivian.com/api/gql/...` returns `via: CloudFront` /
  `x-amz-cf-*` — no `cf-ray`, no JS challenge, no cookie wall. CloudFront fronting a GraphQL
  API does not interpose a browser challenge on POSTs. None of the open-source clients
  implement any anti-bot workaround → a plain `WiFiClientSecure` POST is accepted. *This was
  the biggest kill-risk; it's gone.*
- **No JS/browser behavior anywhere.** Every step is a JSON POST. A headless Home Assistant
  integration runs this fine — proof point.
- **Heap is comfortable** because there's **no display**. The TLS-heap warnings in the
  research (≈37 KB/TLS connection; mbedTLS leaks ~1.3–2 KB/handshake with a custom cert
  bundle; BLE+HTTPS together starves heap) were all about a chip *sharing* SRAM with LVGL +
  audio. A display-less, BLE-less Rivian board has the whole chip. **Mitigations we adopt
  anyway:** pin the **root** CA (not a big custom bundle — this also sidesteps the
  #3119 leak, which was specific to the custom-bundle path); never init BLE.
- **On "persistent TLS session":** don't over-invest here. At a 30 s cadence, CloudFront's
  idle timeout will very likely close a held-open socket between polls, so you'd reconnect most
  cycles regardless — and with no display, a per-poll handshake (~37 KB, freed after) is
  affordable. **Budget for per-poll reconnects**; if handshake cost ever bites, reach for TLS
  **session resumption / session tickets** rather than literally holding the socket open. Watch
  heap over a multi-day run to confirm no slow leak (see the watchdog note in §8).
- **Read-only ⇒ no crypto.** Vehicle *commands* need an HMAC signed by an enrolled phone
  keypair; we do none. Only login + `getVehicleState` are required.

---

## 3. Endpoints

```
GRAPHQL_GATEWAY   = https://rivian.com/api/gql/gateway/graphql     # auth + getUserInfo + getVehicleState
GRAPHQL_CHARGING  = https://rivian.com/api/gql/chrg/user/graphql   # (live charging session — not needed for v1)
GRAPHQL_WEBSOCKET = wss://api.rivian.com/gql-consumer-subscriptions/graphql   # (subscription path — NOT used)
```
One POST per call: JSON body `{ operationName, query, variables }`.

**Base headers on every gateway call:**
```
User-Agent: RivianApp/707 CFNetwork/1237 Darwin/20.4.0
Accept: application/json
Content-Type: application/json
Apollographql-Client-Name: com.rivian.ios.consumer-apollo-ios
dc-cid: m-ios-<uuid>        # client-generated device-correlation id (NOT a server token); synthesize once, PERSIST to NVS, reuse forever
```
> Header-identity note: bretterer's client sends the iOS identity above; RivDocs documents the
> Android identity `com.rivian.android.consumer`. Both are reported working. Pick one, keep it
> consistent. There is **no `dc-sess` header** in the real client — `dc-cid` is the only device field.
> Generate the `dc-cid` UUID once on first boot with a real entropy source (`esp_random()`),
> write it to NVS, and reuse it across reboots — a churning `dc-cid` looks like a new device
> every restart.

**TLS:** hosts serve an **Amazon-issued** cert (`CN=rivian.com`, issuer *Amazon RSA 2048 M04*)
via CloudFront, chaining to **Amazon Root CA 1**. Embed that root CA PEM in `WiFiClientSecure`
and **pin the root, not the leaf** (leaf rotates ~200 days). Standard RSA-2048; the Python
clients use default verification with no pinning, so normal CA verification suffices.

---

## 4. Auth handshake (4 steps, all POST to `GRAPHQL_GATEWAY`)

### Step 1 — CSRF token
Headers: base only.
```graphql
mutation CreateCSRFToken { createCsrfToken { __typename csrfToken appSessionToken } }
```
→ store `csrfToken` (as `Csrf-Token`) and `appSessionToken` (as `A-Sess`).

### Step 2 — Login
Headers: base + `Csrf-Token` + `A-Sess`.
```graphql
mutation Login($email: String!, $password: String!) {
  login(email: $email, password: $password) {
    __typename
    ... on MobileLoginResponse    { accessToken refreshToken userSessionToken }
    ... on MobileMFALoginResponse { otpToken }
  }
}
```
- If `data.login` has `userSessionToken` → **done**, it becomes `U-Sess`.
- If `data.login` has only `otpToken` → MFA required; Rivian texts a code. Go to Step 3.

### Step 3 — OTP completion (only when MFA)
Headers: base + `Csrf-Token` + `A-Sess`.
```graphql
mutation LoginWithOTP($email: String!, $otpCode: String!, $otpToken: String!) {
  loginWithOTP(email: $email, otpCode: $otpCode, otpToken: $otpToken) {
    __typename
    ... on MobileLoginResponse { accessToken refreshToken userSessionToken }
  }
}
```
→ store `userSessionToken` as `U-Sess`.

### Step 4 — "Refresh": there is no refresh mutation
The maintained client captures `refreshToken` but never sends it. On an **expired-token
error**, it simply **re-runs `CreateCSRFToken` (reusing the still-valid `U-Sess`)** and retries.
Our token model:
1. Persist **`U-Sess`** (+ VIN) in NVS. `Csrf-Token`/`A-Sess` are **re-minted each boot** by
   CreateCSRFToken, so they don't need persisting — only `U-Sess` does.
2. On boot, **reuse the persisted `U-Sess`**: mint a fresh CSRF/A-Sess, then call a read to
   verify. If it works, skip login/OTP entirely.
3. On an auth error → mint a new CSRF token, retry. **Silent, unattended.**
4. Only if that also fails → clear the dead `U-Sess`, surface "re-login needed" (link-health LED
   + web page), owner re-enters password/OTP once.

> **✅ Implemented & verified (Phase 1, 2026-07-21):** `rivian_api` persists `U-Sess` to NVS on
> login/OTP success and reuses it on the next boot. Confirmed live — a board reset reused a
> ~40-min-old `U-Sess` via fresh CSRF and pulled vehicle state with **no login and no OTP**. This
> is what keeps MFA off the critical path for a screenless appliance.

### Header matrix
| Call | Csrf-Token | A-Sess | U-Sess |
|---|---|---|---|
| CreateCSRFToken | – | – | – |
| Login / LoginWithOTP | ✓ | ✓ | – |
| getUserInfo / getVehicleState | – | ✓ | ✓ |

(`accessToken` is captured but the gateway authenticates via `A-Sess`/`U-Sess`, not a bearer.)

---

## 5. Telemetry (polling `getVehicleState`)

**Once at boot:** `getUserInfo` → `data.currentUser.vehicles[].{id, vin, name}` → cache **both the
`id` and the VIN**.
```graphql
query getUserInfo { currentUser { vehicles { id vin name } } }
```
> **Phase 1 correction (2026-07-21, live):** `vehicleState(id:)` takes the vehicle **`id`**
> (e.g. `01-244090061`), **NOT the VIN** — passing the VIN returns `NOT_FOUND`. (`name` can be
> `null`.) The protocol dig guessed "VIN"; reality is the `id`. Firmware keys on `id`.

**Every 30 s:** request only the fields we use (each returns `{ timeStamp value }`):
```graphql
query GetVehicleState($vehicleID: String!) {   # pass the vehicle `id`, NOT the VIN (see above)
  vehicleState(id: $vehicleID) {
    batteryLevel     { timeStamp value } # charge % — FLOAT, e.g. 59.700001 (parse as float!)
    batteryLimit     { timeStamp value } # charge TARGET % (e.g. 70 or 100) — where charging stops
    chargerState     { timeStamp value } # e.g. "charging_active" (Phase 1)
    chargePortState  { timeStamp value } # e.g. "open" (Phase 1)
    distanceToEmpty  { timeStamp value } # RANGE in KILOMETERS (§6); firmware converts to miles
    timeToEndOfCharge{ timeStamp value } # minutes to reach batteryLimit (int)
  }
}
```
`batteryLimit` reflects the owner's charge cap — e.g. `70` when set for battery longevity, `100`
for a full charge (confirmed live 2026-07-21: limit 70 while SoC 61%). "Charge complete" is best
read as `batteryLevel ≈ batteryLimit`, not `chargerState` alone.
Response is a few hundred bytes → parse with ArduinoJson in a small buffer. **Do not** request
the default ~100-field property set.

**Cadence & limits:** poll 30 s. The API rate-limits (`RATE_LIMIT` error code; no published
number). On any error, exponential backoff `min(30 * 2^errCount, 900)` seconds. Reset on success.

---

## 6. Low-range alert (the primary feature)

```
rangeMiles = distanceToEmpty.value / 1.60934        // API value is KM (confirmed §1); convert
lowRange   = rangeMiles < rangeThresholdX           // X in MILES, from NVS, set via web page
```
- **X is configurable** on the web page (a number field, **in miles**), persisted to NVS — same
  idea as sonos-button's configurable volume. No reflash to change it.
- **✅ Units confirmed (Phase 1, 2026-07-21):** the raw `distanceToEmpty` field is **kilometers**;
  the US app shows **miles** (live check: 391 km API ≈ 244 mi app). Firmware divides by 1.60934
  and the web page labels/accepts the threshold in miles. (If an owner ever wants km, that's a
  display-unit toggle later — the raw field stays km.)
- **Range, not SoC %, is the right signal** — it already bakes in temperature/load/conditions,
  so "range < X" answers "can I make my trip." (SoC % is still shown for the fullness LED.)
- **Note:** the API also exposes a vehicle-reported `rangeThreshold` field alongside
  `distanceToEmpty` (protocol dig §3). We use our own NVS-configured X (clearer, and decoupled
  from whatever the vehicle uses it for), but the field is there if it ever proves useful.

---

## 7. LEDs (locked: 8-pixel WS2812 stick on the XIAO ESP32-S3)

**Hardware (settled).** An **8-pixel WS2812/NeoPixel stick** (bare, no onboard controller —
the XIAO *is* the controller). The whole strip is a **single meter** (not one-pixel-per-role):
it fills by **SoC ÷ charge-target** (`batteryLevel / batteryLimit`), so "full" = you've hit
your set charge limit, not 100 %.

### Behavior (implemented in `leds.cpp render()`)
| State | Strip |
|---|---|
| **Link down** (offline / needs re-auth / no telemetry yet) | **pixel 0 pulses red**, rest off |
| **Up + charging** (`chargerState == "charging_active"`) | meter stays in place (green filled + white empty); the **closest empty pixel slow-pulses green** (the cell filling), climbing as SoC rises |
| **Up + not charging + range < threshold** (`distanceToEmpty` mi < `rangeThresholdMiles`) | **all pixels flash red together** (low-range alert) |
| **Up + not charging + range OK** | **meter: green filled + white empty** (fill = SoC/target; all green once at target) |
| **OTA push in progress** | whole strip = a **blue progress bar** (`otaProgress()`) |

Brightness-capped (`-DLED_BRIGHTNESS`, single-supply off USB VBUS). "Charging" is `charging_active`
only; `charging_ready` (plugged-idle) reads as not-charging.

**Mounting orientation.** The device is a meter and the outlet decides how it hangs, so which
physical end reads as "the top" isn't fixed — an outlet can put it at **0/90/180/270°**.

*The invariant:* the meter always fills toward **screen-up** when the stick lands vertical and
toward **screen-right** when it lands horizontal. The firmware compensates; the reading never
changes. That's what makes this one setting instead of a per-pattern concern.

*Asked as "where's the plug?"* — `/config` shows four SVG cards (Bottom / Left / Top / Right),
each drawing the case outline with the lead on that edge plus the cells shaded the way they'll
fill. That's a thing you can see without reasoning about LED wiring. Stored as
`Settings::ledRotation()` (NVS `led_rot`, 0/90/180/270, snapped to the nearest quarter turn; it
defaults off the older `led_flip` bool so an already-flipped unit lands on 180°).

**Plug position alone is not enough** — two more facts are needed, and neither is derivable, so
both are settings rather than assumptions:

| Setting | NVS | Why it can't be derived |
|---|---|---|
| `ledStickVertical0()` — is the stick vertical with the plug at the bottom? | `led_vert0` | **Differs per enclosure.** v2's wall case holds the stick vertically on the charger's portrait face; **v1's box mounts board-flat to the wall, LEDs facing out, so its stick runs horizontal** — plug-at-bottom there reads left→right. Default `false` (v1, the unit in service). |
| `ledInverted()` — is the meter filling the wrong way? | `led_inv` | Which physical end **pixel 0** is depends on how that unit's stick was wired. Exposed as a "meter fills the wrong way — reverse it" checkbox: one glance at the device settles it, no guessing in firmware. |

**Defaults confirmed on the real v1 unit** (photo in the root README): wall-mounted with the
USB-C lead exiting the **bottom**, the meter fills **left→right** — 7 green + 1 white at 7/8 of
target. That is exactly what `led_vert0=false, led_inv=false, led_rot=0` predicts, so the
"pixel 0 is at the left end at the reference mounting" assumption is settled for v1, not assumed.

*The math, all in `Settings`:* everything falls out of **`pixel0Dir()`** — where pixel 0 points
once mounted, as clockwise degrees off screen-up. It starts at *down* (vertical stick) or *left*
(horizontal), `+180` if inverted, `+ rotation` for the mounting. Then `ledVertical()` = pixel 0
points up/down, and `ledFlipped()` = pixel 0 points up/right (the two cases where the meter would
otherwise fill down or left). Verified exhaustively: the fill lands up-when-vertical /
right-when-horizontal for **all 16** enclosure × invert × rotation combinations.

*Implementation:* `render()` always draws in **logical** order (index 0 = the "fill from" end) and
`applyOrientation()` reverses the buffer afterwards when `Settings::ledFlipped()`. One remap covers
every pattern in the table above, including the OTA bar. Applies on the next frame, no reboot.

The status page's 8-segment preview switches **axis** to match (`.meter.col`, a `column-reverse`
so logical 0 sits at the bottom) — it never reverses, because the physical meter doesn't either.

**Observed `chargerState` values (growing):** `"charging_active"` (pushing power),
`"charging_ready"` (plugged, idle), `"charging_complete"` (finished / at target — reads as
not-charging, so at/above target it shows the full green meter). Still needed: the unplugged /
fault values — capture by observing those states. `chargePortState` (`"open"`/`"close"`) is ambiguous and
currently unused. The one enum read lives in `leds.cpp` (`sCharging`) for a one-line fix.

### Wiring (single-supply, USB-powered — no external PSU)
```
        XIAO ESP32-S3                      8-pixel WS2812 stick
   ┌───────[ USB-C ]───────┐
5V │ ●───────────────────────────────────► 5V   (VIN)
GND│ ●───────────────────────────────────► GND
3V3│ ●   (do NOT use — 700 mA reg,               ▲
   │      shared with the ESP32)                 │ common ground
D10│ ●──[ ~330 Ω ]──────────────────────► DIN    │
   │  ...                                         │
   └───────────────────────────────────┘         │
                                                  │
   (optional) 470–1000 µF cap across the stick's 5V↔GND if pixel 0 flickers on power-up
```
- **DIN** ← `D10` (GPIO9) through a **~330 Ω** series resistor. GPIO9 is a plain IO — not a
  strapping/USB pin (avoid GPIO0/3/19/20/45/46), so it's safe to drive at boot. `D10` is the
  board's default SPI MOSI, which is free here (no SPI peripheral used).
- **5V** (VIN) ← the XIAO **`5V`** pin — the USB VBUS passthrough (top pin by the USB-C jack).
  Present only when USB-powered; if the board is ever run from a LiPo, this pin is dead and the
  strip loses power (not our case — this is a mains-USB appliance).
- **3.3 V data into a 5 V strip** is marginally under WS2812 spec but reliable at this short
  length; if pixel 0 ever glitches, add a **74AHCT125** shifter on DIN (fallback, not baseline).

### Power budget (why single-supply is safe)
8 px × ~60 mA at full white ≈ **480 mA** — that *would* exceed the safe USB headroom (a plain
port gives ~500 mA and the ESP32's WiFi TX already spikes ~300–350 mA). The fix is a **firmware
brightness cap** (`FastLED.setBrightness(~48/255)` default) plus status colors that are rarely
white: real draw lands in the low tens of mA, comfortably inside budget. **The brightness cap is
the load-bearing mitigation** — it's a hard default in the `leds` module, not a user setting.

---

## 8. Firmware shape (fresh PlatformIO / Arduino ESP32-S3)

Suggested module split (keeps the unofficial-API surface centralized):
- `rivian_api.{h,cpp}` — **the only file that knows Rivian's URLs, headers, and GraphQL
  strings.** Exposes `login()`, `completeOtp()`, `ensureAuth()`, `fetchVin()`, `pollState()`;
  returns a small `VehicleStatus { batteryLevel, chargerState, plugged, rangeRaw, ts }`.
- `net_wifi` — ✅ built. Hostname (= device name, set before STA transition), NVS-or-`secrets.h`
  creds, runtime `apply()`, and the SoftAP captive portal. Lifted from `sonos-nest/src/core/net/`.
- `net_ota` — ✅ built. ArduinoOTA as `<device name>.local`, optional `OTA_PASSWORD`; `otaHandle()`
  serviced in `loop()`. Verified with a live wireless update.
- `settings` — ✅ built (NVS `cfg`): `rangeThresholdMiles`, `deviceName` (sanitized hostname),
  WiFi creds. Tokens/`dc-cid` live in `rivian_api`'s own NVS. **Enable NVS encryption** so tokens
  + WiFi pass aren't at rest in cleartext (see §11).
- `webserver` — SoftAP captive-portal WiFi join + the config/status/login page (§9).
- `leds` — the state machine mapping `VehicleStatus` + link health → the 8-pixel map (§7).
  Uses **`fastled/FastLED`** on `-DLED_DATA_PIN=9` (D10/GPIO9); enforces the brightness-cap
  default (§7 power budget) as a hard floor, not a user knob.
- `main` — boot: wifi (or SoftAP) → ensureAuth → fetchVin → poll loop (30 s) → drive LEDs;
  host `ArduinoOTA.handle()` in `loop()`.

**Concurrency — run the poll in its own FreeRTOS task (the default, not the fallback).** A
`getVehicleState` POST can take seconds, and a dead socket can block up to its timeout; if the
poll and `WebServer` share one cooperative loop, the config page goes unresponsive during every
poll/backoff. Give the poll its own task, share `VehicleStatus` + link-health behind a small
mutex (mirrors sonos-nest's `stateLock()`), and set **explicit socket/TLS timeouts** so a
stalled poll can't wedge the UI.

**Uptime hygiene (24/7 appliance):**
- **WiFi supervisor — ✅ BUILT.** Ported from sonos-nest `f58573d`, which fixed an
  "unresponsive after 2–3 days" report. Before this, `Net::connect()` ran **once at boot** and
  nothing ever re-checked the link: a router reboot / DHCP renewal / AP roam left the box
  alive-but-wedged with the web UI *and* OTA dead — unfixable without pulling the USB. Now:
  - `Net::connect()` sets `setAutoReconnect(true)` + `setSleep(false)` (mains-powered box; modem
    sleep invites AP-driven drops).
  - `sleepSupervised()` in `webserver.cpp` replaces the poll task's blind `vTaskDelay`s: it
    sleeps in 500 ms slices, re-kicks `Net::reconnect()` every 10 s while the link is down, and
    **returns early on recovery so the backoff is cleared**. That last part is rivian-status
    -specific — sonos-nest polls every 3 s with no backoff, whereas this task's backoff caps at
    **900 s**, so a straight port would have left the light stale and red for up to 15 min after
    the network returned.
  - On recovery it **re-advertises mDNS + ArduinoOTA** (`readvertise()` / `otaRestart()`). Both
    bind to the netif that died; without this a healed device is reachable by IP but invisible
    to `.local`, which is exactly how the `/ota` skill discovers it.
  - A **Health card** on the status page (uptime / SSID+RSSI / reconnect count / free heap) —
    a climbing reconnect count says the link is really flapping; a resetting uptime says
    something is rebooting the box instead.
- **Credential survival — ✅ BUILT** (sonos-nest `37669fd`). `Net::connect()` persists
  compiled-in `WIFI_SSID`/`WIFI_PASS` to NVS on a successful connect when NVS is empty.
  Without it, a device that had only ever connected via `secrets.h` drops into the setup portal
  the moment it's flashed with a **CI Release binary** (which ships no `secrets.h` by design).
- **Task watchdog + heap floor** — still TODO. Monitor free heap and reboot on a floor breach;
  cheap insurance against a slow TLS-stack leak over long uptime. The Health card now surfaces
  the heap number this would act on.

---

## 9. Web page (single `WebServer`, one port)

Unlike sonos-nest's sleep-machine (which needed a second port to dodge `WebServer`'s broken
*upload* body parser), we only do **small form POSTs**, so `arg("...")` works — **one port**.

- **`/` status** — plug/charge state, SoC %, current range (with confirmed unit), the low-range
  threshold X, and link health. Read-only view so a screenless board is still inspectable.
- **`/login`** — two-phase form. Submit email+password → server runs CreateCSRFToken + Login.
  If MFA, reveal an **OTP field** → submit → LoginWithOTP. On success, store tokens+VIN, show
  "connected." **Password is never persisted.** Also the **re-auth surface** when a token dies.
- **`/config`** — set **range threshold X** (+ unit once known), poll cadence (optional),
  device name. Persist to NVS.
- **`/wifi`** — the SoftAP captive-portal join page (creds → NVS), plus a recovery entry point.

Reach it at the device IP or an mDNS hostname (set a `DEVICE_HOSTNAME`, e.g. `rivian-status`).

**Security posture of the config surface (accepted, but explicit — see §11):** the page is
**plain HTTP with no auth**. The Rivian **password crosses the local link in cleartext** on
`/login` (and SoftAP is often open), and anyone on the LAN can view status or hit the re-auth
surface. Acceptable for a hobby appliance on a trusted network; surface a short warning on the
`/login` page and keep the account-token-bearing device off untrusted networks.

---

## 10. Phasing

1. **✅ DONE (2026-07-21) — Auth smoke-test (headless, serial).** Hard-code creds in `secrets.h`;
   run CSRF→Login→(OTP)→getUserInfo→getVehicleState once; print the raw response. *Proved the
   CloudFront/TLS/header path works against the real account.* Phase 1 deliverables (all met):
   - **Confirm `distanceToEmpty` units** (km vs miles) against the app display.
   - **Record the raw enum string values** of `chargerState` and `chargePortState` across
     states (unplugged · plugged-idle · charging · complete · fault) — §7's LED state machine
     can't be built without them, and they only appear on the live account.
   - **MFA path:** if the account has MFA on, the serial test needs an **OTP-over-serial input**
     step (Rivian texts the code at login); build that in, or note Phase 1 assumes MFA-off for
     the first pass.
   - Generate + persist the `dc-cid` (§3) so it's stable from the very first real call.
2. **✅ DONE — Poll loop + range check.** 30 s poll, `min(30·2^n,900)` backoff, `lowRange`
   (km→mi). Added `batteryLimit`/`timeToEndOfCharge`. Serial-only. Session persisted/reused.

   *(LEDs moved to the end — the 8-pixel stick hasn't arrived; the software phases below don't
   need it, so do them first and finish with the light.)*
3. **✅ DONE — Web page.** Single `WebServer:80` + a FreeRTOS poll task (mutex-guarded TLS +
   snapshot, per §8). `/` live status (auto-refresh, link-health pill), `/login` (two-phase
   email/password→OTP, password never stored), `/config` (threshold miles + device name → NVS),
   mDNS `<name>.local`. Verified live from a browser: status renders real telemetry, config
   persists. (Browser login→OTP path uses the same `rivian_api` calls proven in Phase 1; not
   re-exercised live to conserve OTPs.) **Device name = DHCP hostname + mDNS + AP name** (single
   source, `Settings`); `setHostname` set before the STA transition (arduino-esp32 quirk, per
   sonos-nest); a rename **reboots** so all three update together — verified live.
4. **✅ DONE — WiFi provisioning.** `net_wifi` module (borrowed from sonos-nest wifi.cpp +
   portal.cpp): tries NVS creds then `secrets.h`; on failure raises a **SoftAP captive portal**
   (open AP `<name>-setup`, wildcard DNS, scan-list join page) that also sets the device name,
   then reboots into STA. Creds persist to NVS. (Portal path compile-verified + mirrors the proven
   sonos-nest code; not exercised live since valid creds are present — would need a creds wipe.)
5. **✅ DONE — OTA.** `net_ota` (ArduinoOTA) advertises as `<device name>.local`, optional
   `OTA_PASSWORD` from `secrets.h`. `phase3-ota` env does espota uploads
   (`OTA_PASSWORD=<pw> pio run -e phase3-ota -t upload`). **Verified live: a full firmware update
   over WiFi (authenticated) succeeded and the device rebooted into it — no USB.** (Enclosure is
   physical, still to do; link-health behavior lands with the LEDs.)
6. **LEDs (last — needs the 8-pixel stick).** Wire the `leds` FreeRTOS state machine to real
   status on the locked stick (§7): FastLED on D10/GPIO9, the per-pixel map, brightness-cap
   default, and the fullness bar + `batteryLimit` mark. Finish the `chargerState`/`chargePortState`
   enum set (idle/unplugged/complete/fault) in this phase; `charging_active`/`open` captured.

---

## 11. Risks & caveats
- **Unofficial API, no stability contract** — RivDocs states it "could change or break at any
  moment." Centralize URLs/headers/queries in `rivian_api.cpp`.
- **Token lifetime undocumented** (community reports: hours-to-days). Design is reactive — never
  pre-refresh; handle the expiry error (re-CSRF, then re-login as last resort).
- **Rate limits undocumented** — 30 s poll + capped backoff is the proven-safe cadence.
- **`distanceToEmpty` units unconfirmed** — verify in Phase 1/2 before trusting the threshold.
- **App-identity header** (iOS vs Android) — both reported working; not resolvable without live
  testing on the account.
- **MFA at re-login needs the owner** — unavoidable for a screenless board; the web page is the
  entry point, and the reactive token model makes it rare.
- **Token-at-rest** — a stored `u-sess` is a live credential granting full account read (and the
  account can command the vehicle). NVS is unencrypted by default, so a flash dump leaks it.
  **Mitigation adopted:** enable NVS encryption (§8); never persist the password regardless.
- **Cleartext config surface** — the web page is plain HTTP with no auth: the Rivian password
  crosses the local link in the clear on `/login`, and anyone on the LAN can view status or
  trigger re-auth (§9). Accepted for a trusted-network hobby appliance; keep it off untrusted
  networks and warn on the login page.
- **Persistent-TLS assumption corrected** — don't rely on a held-open socket surviving the 30 s
  idle gap; budget for per-poll handshakes (fine with no display) and use session resumption if
  cost bites (§2). Watch heap over a multi-day run; a task watchdog reboots on a heap-floor
  breach (§8).

---

## Sources
Deep-research + protocol dig, 2026-07-17:
- `bretterer/rivian-python-client` — the maintained client the HACS integration uses (endpoints,
  header set, auth mutations, `getVehicleState`): https://github.com/bretterer/rivian-python-client
- `bretterer/home-assistant-rivian` — cadence (30 s), backoff (cap 900 s), re-CSRF-on-expiry:
  https://github.com/bretterer/home-assistant-rivian
- RivDocs (kaedenb) — endpoint map, auth flow, BLE enrollment (why local is ruled out):
  https://rivian-api.kaedenb.org/
- `the-mace/rivian-python-api` — corroborating cloud-only client:
  https://github.com/the-mace/rivian-python-api
- ESP32 TLS-heap references (mitigation rationale): esp32_https_server #11, Mbed-TLS #3119,
  arduino-esp32 #2175.
- Smartcar (managed OAuth alternative, not chosen): https://smartcar.com/brand/rivian

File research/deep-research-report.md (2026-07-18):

# Deep-research report — connecting an ESP32 to a Rivian for charge/range status

Question: *Options to connect an ESP32 board to a Rivian vehicle to display/monitor charging
state (charge %, charging status, range, etc.) — cloud API vs local/BLE, auth, libraries,
feasibility on ESP32.*

Method (2026-07-17): fan-out web search across 6 angles → 22 sources fetched → 72 claims
extracted → 25 verified with 3-vote adversarial verification (need 2/3 to kill) → 18 confirmed,
7 refuted → synthesized. For the concrete protocol, see `rivian-cloud-api-protocol.md`.

## Summary

Two programmatic paths exist. The realistic one is **Rivian's cloud GraphQL App API**:
authenticate with a Rivian account (CSRF → email/password login → OTP/MFA when enabled, yielding
`a-sess`/`csrf-token`/`u-sess` session headers) and POST GraphQL to
`https://rivian.com/api/gql/gateway/graphql`, where `GetVehicleState` / `getLiveSessionData`
return state of charge, charger state, power/voltage/amps, time remaining, range added, and
estimated range. A **local BLE API** also exists (same interface the app + keyfob use, direct to
the vehicle, no internet) — but it is **not plug-and-play**: it requires cloud-bootstrapped
phone-key enrollment (registering an ECDH secp256r1 public key server-side) plus cryptographic
pairing before a device gains command authority. Tesla has a working ESP32-BLE project
(`yoziru/esphome-tesla-ble`); **no equivalent turnkey ESP32 Rivian-BLE project exists.** For a
monitor, the cloud API is the fastest route; a managed layer (**Smartcar**) wraps Rivian behind
OAuth owner-consent as an alternative. All Rivian APIs here are unofficial and can change.

## Confirmed findings (high confidence unless noted)

1. **Cloud GraphQL App API is the feasible ESP32 path** — POST to
   `https://rivian.com/api/gql/gateway/graphql`; how the app, community integrations, and Python
   clients all access data. *(3-0)* Sources: RivDocs, home-assistant-rivian,
   bretterer/rivian-python-client, the-mace/rivian-python-api, PyPI.

2. **Auth is a multi-step cloud token flow** — `CreateCSRFToken` (→ csrfToken + appSessionToken)
   → `Login` (email+password) → if MFA, `LoginWithOTP`/`loginWithOTPV2` (OTP) → `userSessionToken`;
   requests carry `Csrf-Token`, `A-Sess`, `U-Sess`. OTP is texted when MFA is on. *(3-0)*

3. **The cloud API returns exactly the needed telemetry** — SoC (`soc`/`batteryLevel`), charger
   state (`vehicleChargerState`/`chargerState`), power/current/voltage, time remaining, energy
   added, range added, estimated range — via `GetVehicleState` + `getLiveSessionData`. HA exposes
   these as ~118 sensor entities. *(3-0)*

4. **A local BLE API exists** — same controls as the app API but sent directly to the vehicle
   over BLE, no internet. Python BLE support lives in `bretterer/rivian-python-client`
   (`src/rivian/ble.py`). *(3-0)*

5. **BLE is NOT plug-and-play** — phone-key enrollment is bootstrapped through a cloud web API
   (`EnrollPhone` GraphQL mutation registering an ECDH secp256r1 public key), required before BLE
   pairing; subsequent commands are HMAC-signed locally. This is the main hurdle for a local
   ESP32 implementation, and no turnkey Rivian-BLE ESP32 project was found. *(3-0)*

6. **Even "BLE-based" HA integrations use BLE only for one-time pairing**, then do all ongoing
   monitoring via the Rivian cloud ("After pairing, Bluetooth is no longer required"). So for a
   monitor-only ESP32, the cloud API alone suffices — no BLE needed. *(3-0)*

7. **Smartcar is a managed cloud alternative** — third-party API covering Rivian EV charging
   management, location, mileage, via OAuth owner-consent (owner logs in with their Rivian
   account); Smartcar handles credentials so passwords don't hit your servers. Cleaner auth for
   an ESP32 (standard OAuth) at the cost of a third-party, likely-paid dependency. *(3-0)*

8. **Tesla precedent shows direct ESP32↔vehicle BLE is possible in principle** —
   `yoziru/esphome-tesla-ble` controls charging + reads battery status over BLE, no cloud
   (Tesla's VCSEC always advertises over BLE). But it's Tesla-specific; Rivian would need its own
   enrollment/crypto ported. *(3-0)* Note: verifiers **refuted** the specific claim that the
   Tesla BLE project reads live charge-rate/energy telemetry (1-2) — treat as control+basic-status
   precedent, not confirmed live telemetry.

## Refuted claims (sounded true, failed verification — recorded so we don't re-adopt them)

- "Live charging state is delivered via an App API 'Parallax' streaming domain with fields like
  `charging.session.status`/`soc_slider`/`time_estimation`." **0-3** — not supported; the real
  fields are the `vehicleState`/live-session ones above.
- "Rivian data is accessed *exclusively* through the cloud (no local/BLE path)." **0-3** — false;
  a BLE path does exist (finding 4), it's just hard.
- "Auth uses token-based auth where the password is never stored / only encrypted tokens
  returned." **0-3** — overstated marketing framing from a secondary source; the actual flow is
  as in finding 2.
- "The rivian-python-client is cloud-only with no BLE transport." **0-3** — false; it ships
  `ble.py`.
- (A the-mace-sourced restatement of the auth claim scored 1-2, but the same claim from stronger
  sources confirmed 3-0 — see finding 2.)

## Open questions (still unresolved after research)

1. **Token/refresh lifetime** and whether an ESP32 can silently refresh without re-triggering an
   OTP to the owner's phone (critical for an unattended monitor). *Partially answered by the
   protocol dig: there's no refresh mutation; re-run CreateCSRFToken on expiry reusing `u-sess`;
   lifetimes remain undocumented.*
2. Is the full Rivian **BLE pairing + HMAC command-signing** handshake documented well enough to
   port to ESP32 C++, and has anyone built a non-app Rivian BLE client? *(Not for our read-only
   monitor — moot unless control is ever wanted.)*
3. Does the ESP32 TLS/HTTPS stack + heap comfortably handle the endpoint? *Answered: yes,
   especially with no display — see protocol doc §5.*
4. Smartcar pricing/rate-limit tier for a single-vehicle hobby project, and whether its OAuth
   consent redirect fits a headless device.

## Caveats

All Rivian API details come from unofficial, reverse-engineered community sources (RivDocs /
rivian-api.kaedenb.org, edman007.com, the Python/HA libraries) — no official API, so endpoints,
auth, and field names can change without notice. The cloud path is well-corroborated by multiple
primary sources (client library source code) and is the low-risk choice. The BLE path is real but
under-documented for third parties, requires a cloud enrollment step, and has no ESP32 precedent
for Rivian. Verifiers specifically refuted that Tesla's ESP32 BLE project reads live charge-rate
telemetry, so don't assume Rivian BLE would expose full live charging telemetry either. Smartcar
is a commercial dependency. MFA/OTP handling on a headless ESP32 is a practical wrinkle (the OTP
is texted at login) — the token refresh/re-auth strategy matters. Rivian Gen2 vehicles add UWB
and have integration caveats noted in the HA project.

## Sources (with quality rating)

| URL | Quality | Angle |
|---|---|---|
| https://rivian-api.kaedenb.org/ | blog | Rivian data access options |
| https://rivian-api.kaedenb.org/app/charging | blog | Rivian data access options |
| https://rivian-api.kaedenb.org/app/authentication/ | secondary | cloud API / auth |
| https://rivian-api.kaedenb.org/ble/ | blog | BLE |
| https://rivian-api.kaedenb.org/ble/enroll/ | blog | BLE enrollment |
| https://github.com/bretterer/rivian-python-client | primary | cloud client (the maintained one) |
| https://github.com/bretterer/home-assistant-rivian | primary | HA integration |
| https://pypi.org/project/rivian-python-client/ | primary | cloud client |
| https://github.com/the-mace/rivian-python-api | primary | cloud client + CLI |
| https://smartcar.com/brand/rivian | primary | managed OAuth alternative |
| https://github.com/yoziru/esphome-tesla-ble | primary | Tesla ESP32-BLE precedent |
| https://github.com/OpenEVSE/openevse_esp32_firmware/issues/984 | forum | ESP32 Rivian feature request |
| https://github.com/fhessel/esp32_https_server/issues/11 | forum | ESP32 TLS heap (~37 KB/conn) |
| https://github.com/Mbed-TLS/mbedtls/issues/3119 | forum | mbedTLS handshake leak |
| https://github.com/espressif/arduino-esp32/issues/2175 | forum | BLE+HTTPS heap starvation |
| https://rivianroamer.com/help | secondary | (source of two refuted claims) |

## Stats
6 angles · 22 sources fetched · 72 claims extracted · 25 verified · 18 confirmed / 7 refuted ·
8 findings after synthesis · 105 agent calls.

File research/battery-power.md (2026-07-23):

# Battery power for the LED strip — decision

**Question:** can the 8-pixel WS2812 strip run on battery when the board is unplugged from USB?
**Date:** 2026-07-22. **Source:** deep-research (102 agents, 24/25 claims verified vs primary docs).

## TL;DR

- **As built, no.** The strip is fed from the XIAO's `5V` pin, which is **USB-VBUS passthrough** —
  dead on battery. (See `plans/01-…md` §7 wiring note.)
- **No single ESP32-S3 dev board fixes this.** Every mainstream one (Adafruit ESP32-S3 Feather,
  SparkFun Thing Plus ESP32-S3, Unexpected Maker FeatherS3/ProS3/TinyS3/Series[D]) regulates the
  LiPo to **3.3 V only**; their "5V/USB" pin is the same VBUS-passthrough trap. **None has an
  onboard 5 V boost.**
- **Fix = board + external LiPo-charger/5V-boost module.** The **Adafruit PowerBoost 500C/1000C**
  (TI TPS61090) makes a real regulated **~5.2 V** rail from a 3.7 V LiPo at 500–1000 mA+, with
  load-share (charges from USB *and* powers the load simultaneously).
- **Decision: stay USB-powered for the shipped appliance.** Always-on WiFi makes battery runtime
  short (see below), and sleep modes fight the always-on web UI/OTA. Battery is a viable *optional*
  add-on (XIAO + PowerBoost + a chunky LiPo) for portable/backup use, not the default.

## Board comparison (5 V-on-battery is the deciding column)

| Board | 5 V on battery? | Antenna | Charge / gauge | Notes |
|---|---|---|---|---|
| **Seeed XIAO ESP32-S3** (current) | ❌ VBUS-only | external U.FL (fragile in enclosures) | basic LiPo pads | what we have |
| Adafruit ESP32-S3 Feather | ❌ VBUS-only | varies (some U.FL) | MAX17048 gauge | 3.3 V reg only |
| SparkFun Thing Plus ESP32-S3 | ❌ VBUS-only | **onboard PCB** ✔ | MCP73831 (~214 mA) + MAX17048 | same S3 → firmware ports (pin renames); best antenna fix |
| UM FeatherS3 / ProS3 / Series[D] | ❌ VBUS-only | PCB (Series[D] = dual + RF switch) | charger; 3.3 V LDOs | UM docs: bring your own boost |

Primary-source verified: the 5 V rail is boost-backed on **none** of them.

## The runtime reality (why USB stays the default)

Always-on WiFi (no power-save) averages **~90–150 mA** + TX bursts:

| LiPo | No sleep | Modem-sleep (~15–20 mA) | Auto light-sleep (~1–2.5 mA) |
|---|---|---|---|
| 1000 mAh | ~6–10 h | ~2 days | ~2–3 weeks |
| 2000 mAh | ~12–20 h | ~3–4 days | weeks |
| 3500 mAh | ~1–1.5 days | ~1 week+ | weeks |

(LED current adds on top when lit; independent of MCU sleep state.)

**The catch:** modem/light-sleep keeps WiFi *associated* but throttles the radio/CPU, which
conflicts with the appliance's **always-reachable web UI + OTA** — keeping HTTP instantly
responsive forces near-active mode. So it's a genuine tradeoff: a big LiPo for ~half-a-day-to-a-day
of no-sleep runtime, **or** add sleep and accept the web/OTA endpoints only wake on a schedule.

## If we build the battery option

**Parts:** XIAO ESP32-S3 (keep) + **Adafruit PowerBoost 500C** (or 1000C for margin) + a LiPo
(2000–3500 mAh for meaningful runtime).

**Wiring:**
```
LiPo ───────────► PowerBoost (JST)
USB ────────────► PowerBoost micro-USB    (charges LiPo + load-share)
PowerBoost 5V ──► WS2812 strip 5V  AND  XIAO 5V pin   (whole thing runs on battery)
PowerBoost GND ─► common GND (strip + XIAO)
XIAO GPIO9 ─────► strip DIN  (through the ~330 Ω, unchanged)
```
- **Zero firmware change** (still FastLED on D10/GPIO9).
- **Flashing moves to OTA** (already set up — `/ota`), since USB now feeds the PowerBoost, not the
  XIAO's data port. (Or plug USB into the XIAO directly for a one-off USB flash.)
- **Enclosure grows** to house the LiPo + PowerBoost — the current `hardware/` box would need a
  battery bay / a second compartment.
- Optional: swap XIAO → **SparkFun Thing Plus ESP32-S3** to also kill the external-antenna
  fragility (onboard PCB antenna), still with the PowerBoost.

## Open questions (if we pursue it)
- Measured average current of *this* firmware (30 s poll + always-on WiFi + 8 px @ ~40/255) with
  and without modem-sleep — the numbers above are datasheet-derived, not bench-measured.
- Can modem-sleep / DTIM light-sleep coexist with the always-on web UI + OTA, or does always-on
  HTTP force full active mode?
- WS2812 reliability on the PowerBoost's 5.2 V rail with 3.3 V data — level shifter / sacrificial
  pixel needed, or fine at this short length + low brightness? (Plan §7 already flags a 74AHCT125
  as the fallback.)

## Sources
- [Adafruit ESP32-S3 Feather — Power Management](https://learn.adafruit.com/adafruit-esp32-s3-feather/power-management) · [Pinouts](https://learn.adafruit.com/adafruit-esp32-s3-feather/pinouts)
- [Adafruit PowerBoost 1000C](https://learn.adafruit.com/adafruit-powerboost-1000c-load-share-usb-charge-boost/overview) · [PowerBoost 500C (#1944)](https://www.adafruit.com/product/1944)
- [SparkFun Thing Plus ESP32-S3 — hardware overview](https://docs.sparkfun.com/SparkFun_Thing_Plus_ESP32-S3/hardware_overview)
- [Espressif — Low-Power Mode in Wi-Fi (ESP32-S3)](https://docs.espressif.com/projects/esp-idf/en/stable/esp32s3/api-guides/low-power-mode/low-power-mode-wifi.html)
- [Seeed XIAO ESP32-S3 WiFi/antenna docs](https://wiki.seeedstudio.com/xiao_esp32s3_wifi_usage/) · [enclosure WiFi-loss report](https://forum.seeedstudio.com/t/xiao-esp32s3-antenna-wi-fi-not-working/272978)
- [Unexpected Maker Series[D] (dual antenna, no 5V boost)](https://www.cnx-software.com/2025/07/21/unexpected-maker-launches-seriesd-esp32-s3-boards-with-dual-antenna-software-rf-switch/)

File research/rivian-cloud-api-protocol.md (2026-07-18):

# Rivian cloud GraphQL API — protocol details for an ESP32 port

Gathered 2026-07-17. Authoritative implementation mined: **`bretterer/rivian-python-client`**
(`main`) — the exact library the HACS "Rivian (Unofficial)" integration
(`bretterer/home-assistant-rivian`) depends on. `kaedenb/rivian-api` (RivDocs) corroborates and
supplies the endpoint map. Conflicts between the two are flagged inline.

Primary sources:
- Client source: https://github.com/bretterer/rivian-python-client → `src/rivian/rivian.py`, `src/rivian/const.py`
- HA integration: https://github.com/bretterer/home-assistant-rivian → `custom_components/rivian/coordinator.py`, `__init__.py`
- RivDocs: https://rivian-api.kaedenb.org/app/ and `/app/authentication/`

---

## 1. Endpoints

```
GRAPHQL_BASEPATH  = https://rivian.com/api/gql
GRAPHQL_GATEWAY   = https://rivian.com/api/gql/gateway/graphql              # auth + vehicle state + commands
GRAPHQL_CHARGING  = https://rivian.com/api/gql/chrg/user/graphql           # wallboxes + live charging session
GRAPHQL_WEBSOCKET = wss://api.rivian.com/gql-consumer-subscriptions/graphql # live telemetry subscription
```
(RivDocs lists two more service graphs not needed here: `/api/gql/orders/graphql`,
`/api/gql/t2d/graphql`.) Each is one POST endpoint per service; JSON body carries
`operationName` + `query` + `variables`.

**Bot protection / infra (verified live 2026-07-17):** hosts sit behind **AWS CloudFront**,
not Cloudflare. `curl -I` on the gateway returns `via: ...cloudfront.net (CloudFront)` and
`x-amz-cf-*` headers — no `cf-ray`, no JS challenge, no cookie wall. CloudFront fronting a
GraphQL API does not interpose a browser/JS challenge on API POSTs. No open-source client
implements any anti-bot workaround (no cookie jar, no TLS-fingerprint evasion) → strong
evidence a plain TLS client is accepted.

---

## 2. Auth handshake (all POST to `GRAPHQL_GATEWAY`)

Base header set (`rivian.py` 53-58):
```
User-Agent: RivianApp/707 CFNetwork/1237 Darwin/20.4.0
Accept: application/json
Content-Type: application/json
Apollographql-Client-Name: com.rivian.ios.consumer-apollo-ios
```
Plus `dc-cid` auto-added if absent (line 659-660): `dc-cid: m-ios-<uuid4>`. This is a
client-generated device-correlation id, **not** a server token — synthesize any stable
`m-ios-<uuid>` on the ESP32. **There is no `dc-sess` header** in the real client; `dc-cid` is
the only device field. (The `dc-sess` seen in some notes is an older-API conflation.)

**Header-identity conflict:** bretterer sends the iOS identity
(`com.rivian.ios.consumer-apollo-ios`); RivDocs documents the Android identity
(`apollographql-client-name: com.rivian.android.consumer`). Both reported working — server
appears identity-agnostic. Pick one, keep it consistent.

### Step 1 — CSRF token (`create_csrf_token`, lines 138-156)
Headers: base only.
```json
{"operationName":"CreateCSRFToken","variables":null,
 "query":"mutation CreateCSRFToken { createCsrfToken { __typename csrfToken appSessionToken } }"}
```
Returns `data.createCsrfToken.{csrfToken, appSessionToken}`. Store as `csrf-token` and `a-sess`.

### Step 2 — Login (`authenticate`, lines 158-186)
Headers: base + `Csrf-Token: <csrf>` + `A-Sess: <appSessionToken>`.
```graphql
mutation Login($email: String!, $password: String!) {
  login(email: $email, password: $password) {
    __typename
    ... on MobileLoginResponse    { accessToken refreshToken userSessionToken }
    ... on MobileMFALoginResponse { otpToken }
  }
}
```
Variables `{email, password}`. Two possible shapes in `data.login`:
- MFA **not** required → `{accessToken, refreshToken, userSessionToken}` — done; `userSessionToken` → `u-sess`.
- MFA **required** → `{otpToken}` only. Client detects via `"otpToken" in login_data` (line 180) and stashes it. Rivian texts the code.

### Step 3 — OTP completion (`validate_otp`, lines 198-226)
Headers: base + `Csrf-Token` + `A-Sess`.
```graphql
mutation LoginWithOTP($email: String!, $otpCode: String!, $otpToken: String!) {
  loginWithOTP(email: $email, otpCode: $otpCode, otpToken: $otpToken) {
    __typename
    ... on MobileLoginResponse { accessToken refreshToken userSessionToken }
  }
}
```
Variables `{email, otpCode, otpToken}` (otpToken from step 2). Returns
`{accessToken, refreshToken, userSessionToken}`.

### Step 4 — "Refresh": there is none
**No dedicated refresh mutation exists in the maintained client.** `refreshToken` is stored but
never sent (grep of `rivian.py`: `refresh` appears only in `__init__` storage + the two login
query strings). RivDocs documents no refresh mutation either.

How HA handles expiry (`coordinator.py` 97-99):
```python
except RivianExpiredTokenError:
    _LOGGER.info("Rivian token expired, refreshing")
    await self.api.create_csrf_token()
```
i.e. on an expired-token error it **re-runs CreateCSRFToken (reusing the still-valid `u-sess`)**
and retries. Practically for the ESP32: persist `csrf-token`, `a-sess`, `u-sess`; on an auth
error mint a new CSRF token and retry; only fall back to full email/password (+OTP) re-login if
that fails. Simpler than a refresh flow — nothing to implement.

### Header matrix (which tokens on which call)
| Call | Csrf-Token | A-Sess | U-Sess |
|---|---|---|---|
| CreateCSRFToken | – | – | – |
| Login / LoginWithOTP | ✓ | ✓ | – |
| getUserInfo, getVehicleState, images, OTA, commandState | – | ✓ | ✓ |
| sendVehicleCommand, wallboxes, enroll/disenroll | ✓ | ✓ | ✓ |
| getLiveSessionData | – | – | ✓ (u-sess only) |

Reads generally need only `A-Sess`+`U-Sess`; mutations add `Csrf-Token`. (Source: per-method
`headers = BASE_HEADERS | {...}` dicts, `rivian.py` 240-473.) `accessToken` is captured but the
gateway authenticates via `a-sess`/`u-sess`, **not** an `Authorization` bearer — no method sends one.

---

## 3. Telemetry

Both mechanisms keyed by **vehicle ID = the VIN** (`get_vehicle_state(vin, ...)`; the variable is
named `vehicleID` but a VIN is passed).

**Enrollment lookup first** — get the VIN before any telemetry. `get_user_information`
(`getUserInfo`, lines 315-336) → `data.currentUser.vehicles[]` `{id, vin, name, ...}`. Query
once, cache.

### (a) Polling query (`get_vehicle_state`, lines 412-445) — RECOMMENDED for ESP32
Endpoint `GRAPHQL_GATEWAY`, headers `A-Sess`+`U-Sess`:
```graphql
query GetVehicleState($vehicleID: String!) { vehicleState(id: $vehicleID) { ...fields } }
```
Fields come from a property set; each scalar expands to `{ timeStamp value }`
(`_build_vehicle_state_fragment`, lines 734-739). Relevant fields (from `const.py`):
- **Charge %:** `batteryLevel` (also `soc` in the live-session graph)
- **Charging state:** `chargerState`, `chargerStatus`, `chargerDerateStatus`
- **Range:** `distanceToEmpty` (+ `rangeThreshold`)
- **Plug status:** `chargePortState` (port door); charging engagement via `chargerState`
- **Extras:** `batteryCapacity`, `batteryLimit`, `powerState`, `timeToEndOfCharge`,
  `remoteChargingAvailable`, `gnssLocation` (→ `{latitude longitude timeStamp isAuthorized}`)

Response shape: `data.vehicleState.batteryLevel = {"timeStamp":"...","value":73}` — every field
is a timestamped record, not a bare scalar. **Embedded-friendly:** request only the 4-5 fields
you need (the client accepts a `properties` subset) → a few hundred bytes → small ArduinoJson buffer.

### (b) WebSocket subscription (`subscribe_for_vehicle_updates` + `_ws_connect`, 596-649) — NOT used
Endpoint `GRAPHQL_WEBSOCKET`, `graphql-transport-ws` protocol:
```json
// on connect:
{"type":"connection_init","payload":{
  "client-name":"com.rivian.ios.consumer-apollo-ios",
  "client-version":"1.13.0-1494",
  "dc-cid":"m-ios-<uuid4>",
  "u-sess":"<userSessionToken>"}}
// after connection_ack:
{"operationName":"VehicleState",
 "query":"subscription VehicleState($vehicleID: String!) { vehicleState(id: $vehicleID) { ...fields } }",
 "variables":{"vehicleID":"<VIN>"}}
```
Note the WS carries `u-sess` in the init **payload** (not an HTTP header), plus
`client-version: 1.13.0-1494`. Subscription-only fields (not in polling) include tire pressures
and some charging-trip fields (`const.py VEHICLE_STATES_SUBSCRIPTION_ONLY_PROPERTIES`).

**Why we skip it:** the WS needs a persistent `wss` connection, the `graphql-transport-ws`
handshake (`connection_init`/`connection_ack`/`next`/`ping`), and reconnect logic — much heavier
on an MCU than a single POST, for no benefit to a status light.

---

## 4. Token lifetimes & rate limits

- **Lifetimes not published.** RivDocs: "not specified." The client treats tokens as opaque and
  reactive — no pre-emptive refresh; waits for `RivianExpiredTokenError` then re-mints CSRF
  (`coordinator.py` 97-99). Community reports put sessions at hours-to-days; nothing
  authoritative. Treat as "unknown, handle the expiry error."
- **Rate limiting exists.** Client maps a `RATE_LIMIT` GraphQL error code to
  `RivianApiRateLimitError` (`rivian.py` 90, `ERROR_CODE_CLASS_MAP`). No documented number. HA's
  cadence is a safe baseline: main vehicle-state poll every **30 s** (`coordinator.py`
  `_update_interval_seconds = 30`); charging/driver coordinators every 15 min when idle;
  **exponential backoff on errors capped at 900 s** (`min(interval * 2**error_count, 900)`, line 69).

---

## 5. Feasibility notes for embedded (ESP32-S3, Arduino/C++)

**TLS / certificates (verified live 2026-07-17):**
- `rivian.com` and `api.rivian.com` serve an **Amazon-issued** cert:
  `issuer = C=US, O=Amazon, CN=Amazon RSA 2048 M04`, `subject CN=rivian.com`. Fronted by CloudFront.
- Chain roots at **Amazon Root CA 1**. Embed that root CA PEM in `WiFiClientSecure` (or the
  Starfield G2 cross-signed root Amazon still uses). Standard RSA-2048, no exotic curve.
- Certs rotate (~200-day validity; live leaf valid Jul 2026 → Jan 2027) → **pin the root CA,
  never the leaf.**
- Python clients use plain aiohttp with default verification, **no pinning, no client cert** →
  normal CA verification is all that's required.

**No JS / browser behavior.** Every step is a JSON POST (or JSON WS frame). No HTML scraping,
cookies, captcha, or JS anywhere. A headless HA integration runs it fine — proof point.

**Payload sizes:**
- Auth requests/responses: < 1 KB each.
- `getUserInfo`: a few KB (vehicles + feature list) — fetch once at boot for the VIN.
- `getVehicleState` with a subset (`batteryLevel`, `chargerState`, `chargePortState`,
  `distanceToEmpty`): a few hundred bytes. **Do not** request the default ~100-field set.
- Skip the WebSocket to avoid persistent-connection + sub-protocol burden.

**Crypto you can avoid:** `sendVehicleCommand` needs an HMAC signed with an enrolled phone
keypair (NIST P-256 / BLE phone enrollment, `generate_vehicle_command_hmac`). **Read-only
telemetry (battery/charge/range/plug) never touches this** — only login + `getVehicleState`.
Vehicle *control* would additionally require phone enrollment + BLE pairing (a much bigger lift).

**ESP32 TLS-heap context** (why "no display" matters): each mbedTLS `SSL_new()` ≈ 37 KB heap
(esp32_https_server #11); mbedTLS leaks ~1.3–2 KB/handshake with a custom root-cert bundle,
exhausting after ~120 requests (Mbed-TLS #3119); BLE + HTTPS together starved heap (170 KB →
45 KB, HTTPS then failed — arduino-esp32 #2175). All were display/audio-sharing scenarios.
Mitigations adopted anyway: persistent TLS session (poll over it, don't reconnect), pin the
root CA (not a big bundle), never init BLE.

---

## 6. Conflicts / staleness caveats
- **App-identity header** differs between sources (iOS `com.rivian.ios.consumer-apollo-ios` in
  bretterer vs Android `com.rivian.android.consumer` in RivDocs). Both reportedly work; not
  resolvable without live testing on the account.
- **`dc-sess`** does not exist in either current source — the device field is `dc-cid`,
  client-generated. Older-API conflation.
- **Token lifetimes / rate-limit numbers** are genuinely undocumented; values above are HA's
  empirical cadence, not published guarantees.
- **Unofficial API, no stability contract** — RivDocs states it "could change or break at any
  moment." Centralize endpoint URLs, headers, and query strings so a server-side change is a
  one-file fix.

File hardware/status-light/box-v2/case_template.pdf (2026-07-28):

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

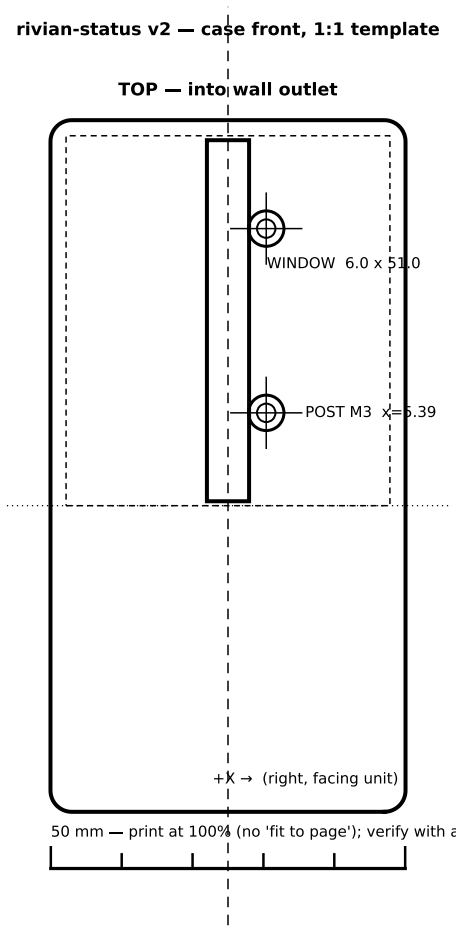
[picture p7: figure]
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

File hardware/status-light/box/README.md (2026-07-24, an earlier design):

# box/ — the `rivian-status` desk light enclosure

A small **top-bar** box: the 8-pixel WS2812 stick is stacked **above** the XIAO ESP32-S3
and its LEDs face **up through a window in the lid**. Everything is screwed — the stick
onto two posts, the lid to four side-wall bosses. USB-C exits the **back wall** (centred,
fully proud); the U.FL antenna coils **inside** for now (a front-wall exit slot is a
one-flag toggle, `ANT_EXIT`).

**Outer size:** ~75.3 × 34.3 × 16.0 mm (recomputes from the params).
**Every dimension, with provenance:** [`MEASUREMENTS.md`](MEASUREMENTS.md).

## Parts
| File | What |
|---|---|
| `shell.stl` | body: floor, walls, XIAO pocket (corner standoffs + ribs), USB-C port (back wall), **2 stick-mount posts**, **4 lid-screw bosses** (optional front-wall antenna notch via `ANT_EXIT`) |
| `lid.stl` | cap: roof + the **LED diffuser window** (with a film rebate), 4 countersunk screw holes, 2 board-clamp pads |

## Build
```bash
conda run -n img23d python build_all.py      # -> shell.stl + lid.stl
conda run -n img23d python render_preview.py # -> render_preview.png
```
Same toolchain as `../../../../sonos-nest/hardware` (trimesh CSG + manifold3d, `img23d`
env). `build_shell.py` runs `check_clearances()` on every build.

## Assembly / fasteners (all M3 self-tapping into printed bosses)
1. Drop the **XIAO** into its floor pocket (corner standoffs + ribs; USB-C pokes out the
   back wall). Wires solder directly to the pads.
2. Plug in the **U.FL antenna**; coil the pigtail + flex antenna in the open floor space
   around the board (or set `ANT_EXIT = True` to route it out a front-wall slot).
3. Set the **LED stick** on the two posts (LEDs up) and drive **2× M3×6** down through its
   Ø3.75 holes into the posts.
4. Wire the stick (DIN/5V/GND) down to the XIAO (D0 / 5V / GND).
5. Lower the **lid** (LEDs show through the window) and fasten **4× M3×8** into the
   side-wall bosses. The lid pads clamp the board onto its standoffs.

## Layout note — why USB-C is on the back wall
The stick sits over the board and the lid is screwed down, so a corner screw boss can't
share a short end with the board. Putting USB-C on the **back long wall** keeps it fully
proud with no recess. An **end-exit** USB-C is possible but needs the board recessed ~5 mm
from that wall (a screw boss then clears the board corner) — say the word and I'll switch.

## ⚠️ Before a final print
1. **Peg/hole & boss fits** print tight in FDM — test a coupon. `SCREW_PILOT` (2.6) is the
   thread-forming pilot for M3; `LED_HOLE_D` (3.75) is the stick's measured hole.
2. **Diffuser** — the window has a top rebate for a stick-on film / thin acrylic, or print
   the lid in translucent/natural filament.
3. **Antenna** — it coils inside by default; if WiFi is weak (CLAUDE.md warns this XIAO
   needs the external antenna), flip `ANT_EXIT = True` to poke it out the front wall.

## Frame
`+X` width (long axis, the LED bar) · `+Y` depth (front→back) · `+Z` up (LEDs face +Z).
Origin centred in X and Y; z = 0 is the floor's underside.

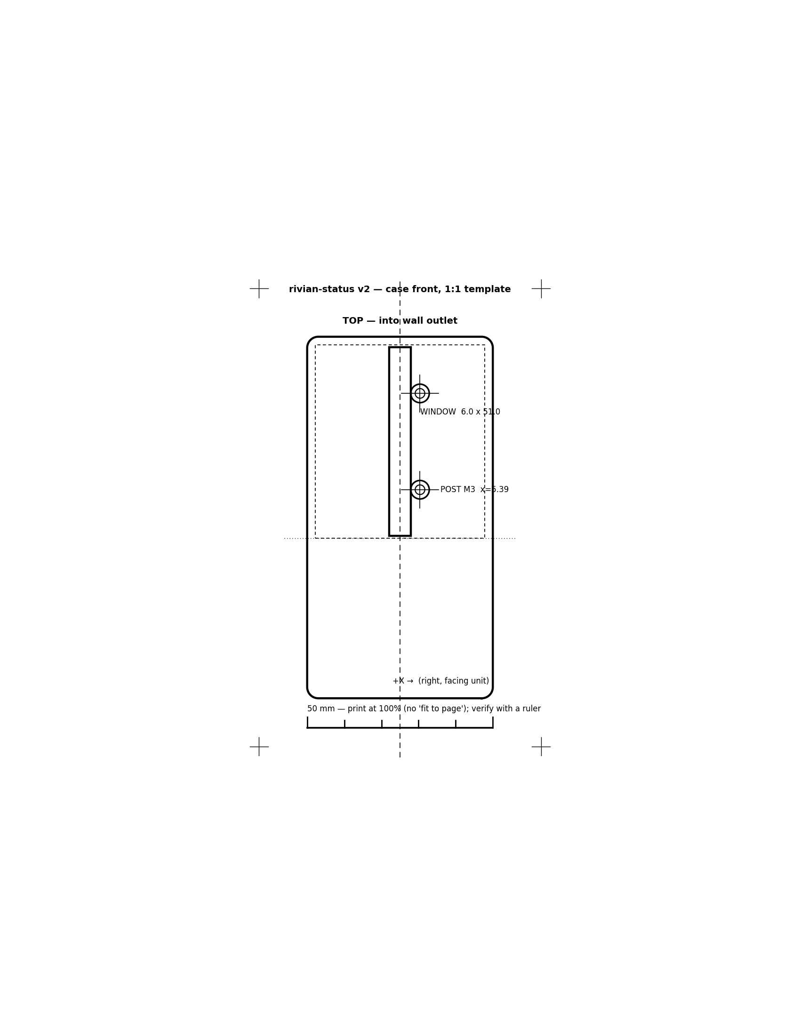
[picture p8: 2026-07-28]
hardware/status-light/box-v2/case_template.png

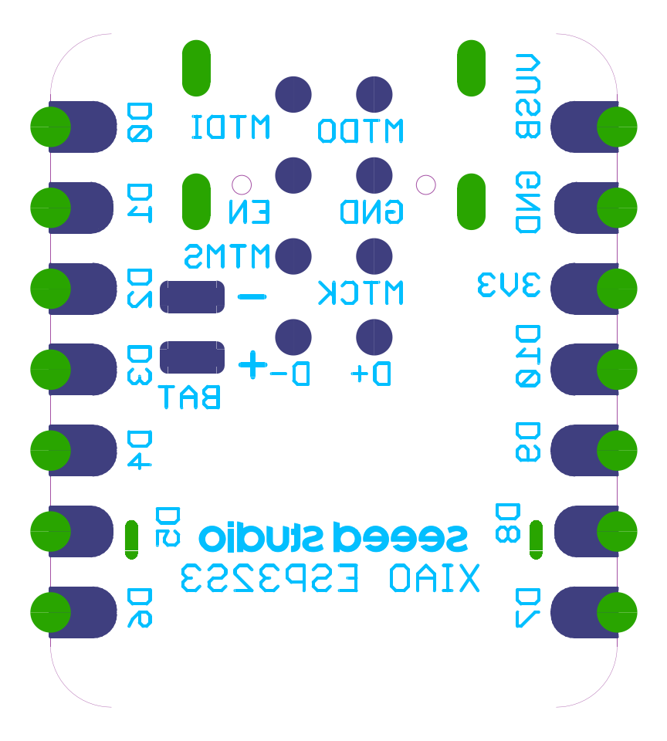
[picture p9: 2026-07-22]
hardware/status-light/ref/xiao_footprint_bottom.png

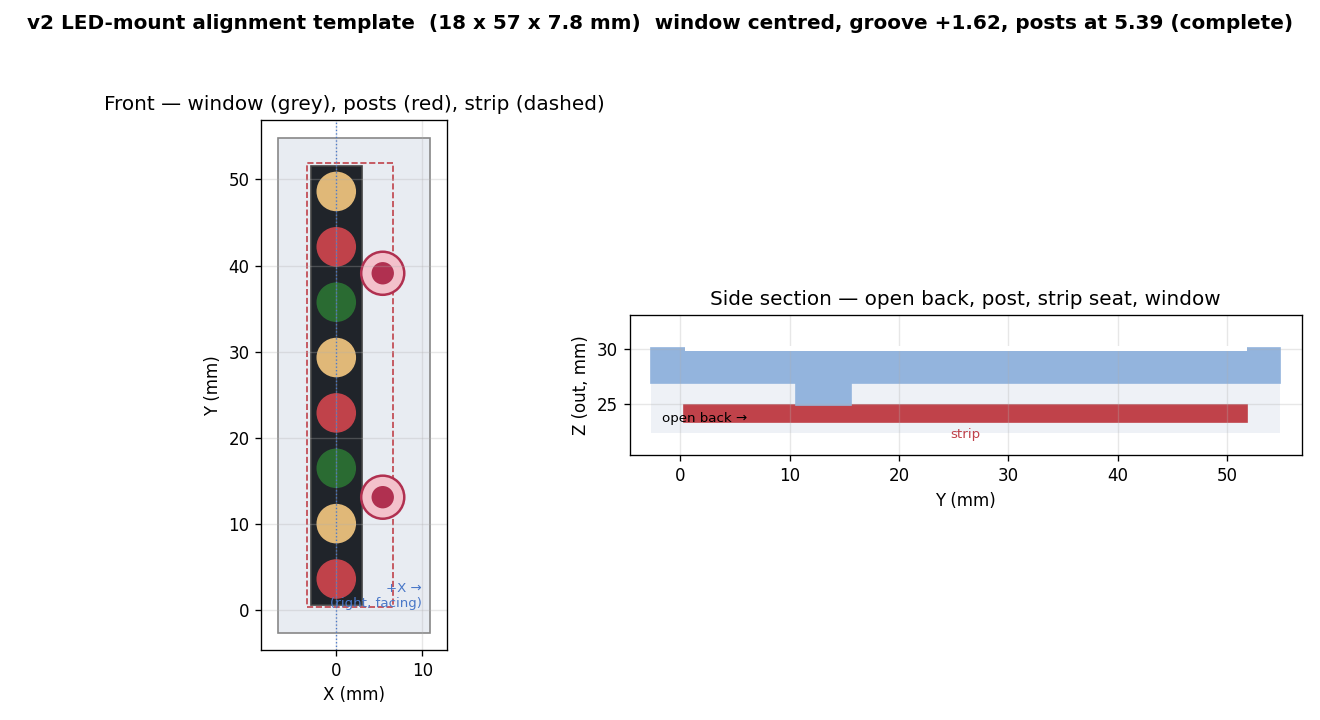
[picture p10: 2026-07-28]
hardware/status-light/box-v2/template_preview.png

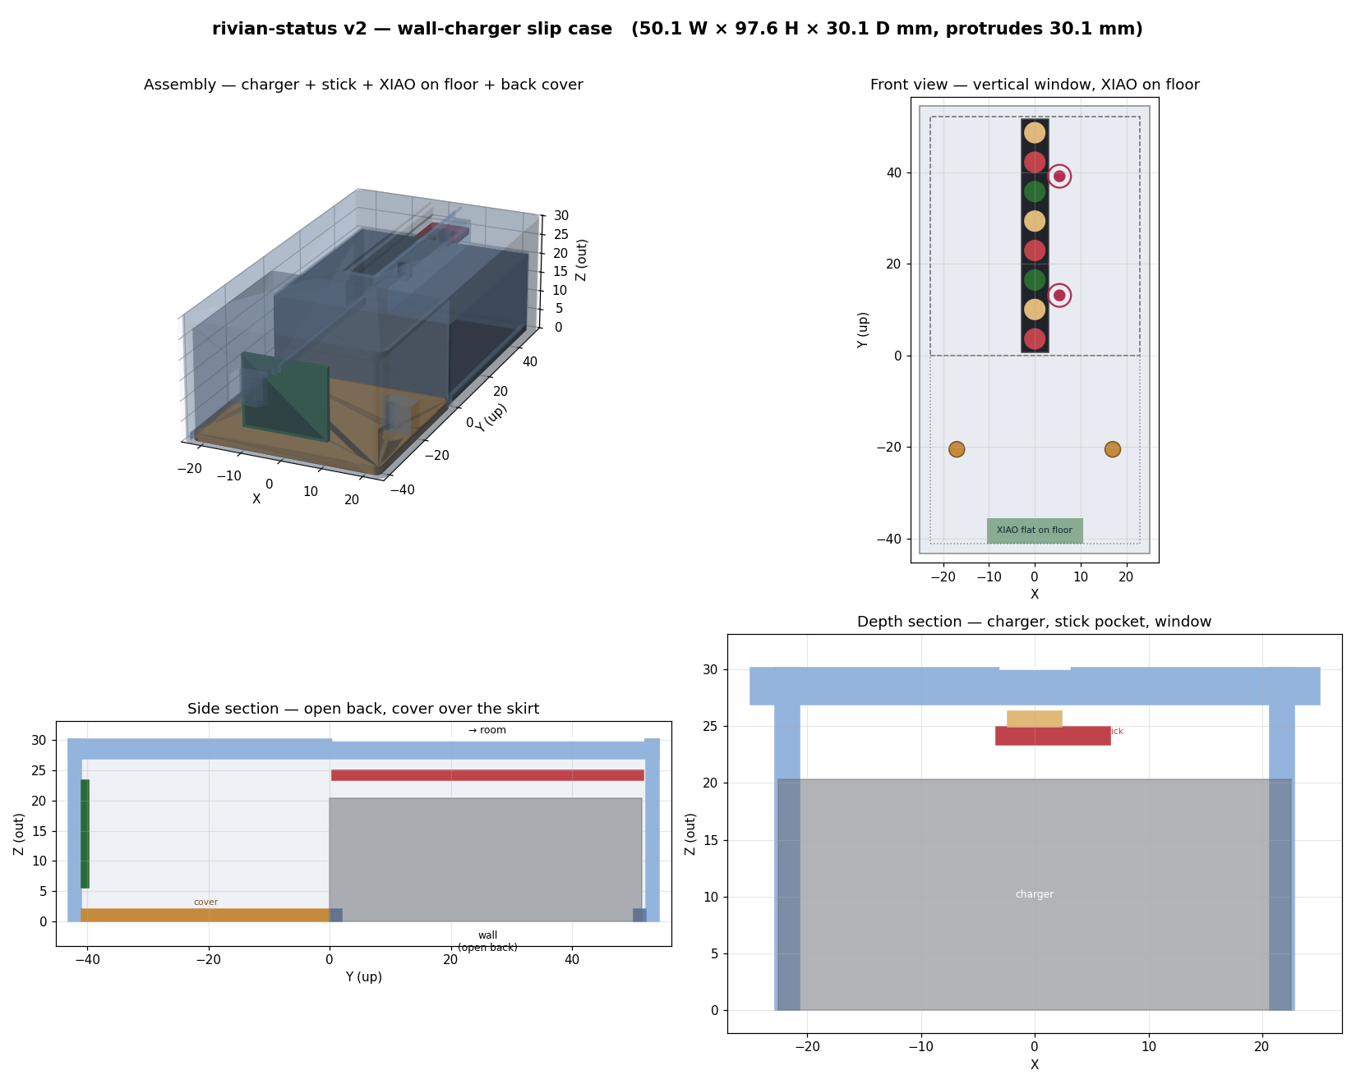
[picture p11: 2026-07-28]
hardware/status-light/box-v2/render_preview.png

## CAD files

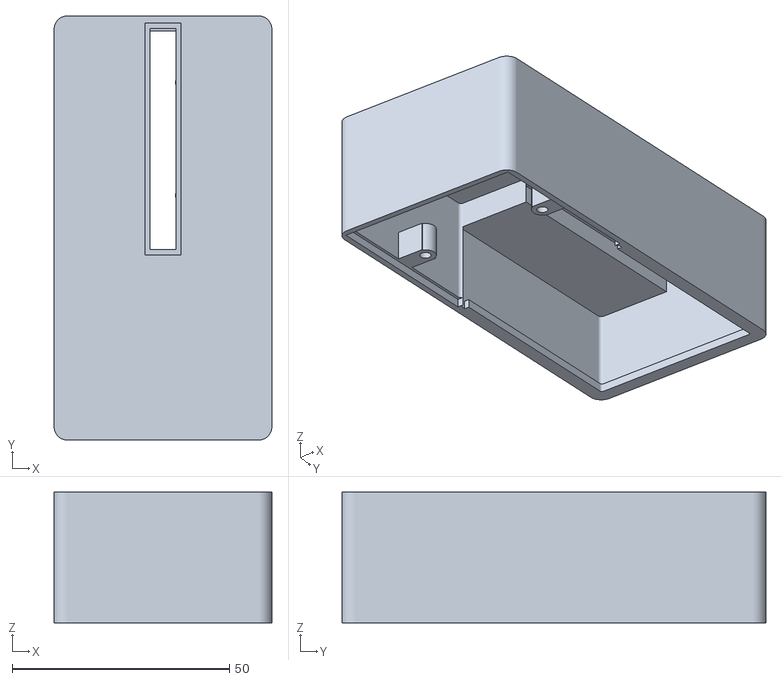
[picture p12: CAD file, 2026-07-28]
hardware/status-light/box-v2/case.stl
50.1 x 97.6 x 30.1

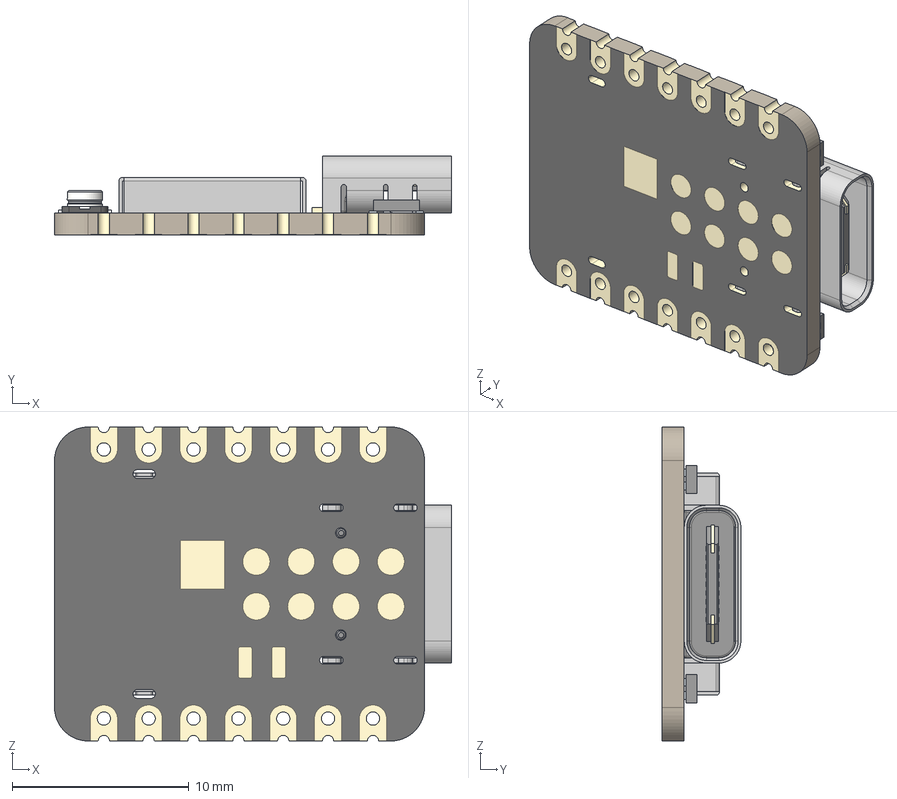
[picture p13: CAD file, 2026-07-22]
hardware/status-light/ref/XIAO-ESP32S3 v2.step
22.5 x 4.46 x 17.8 mm
BOSS-EXTRUDE14_8_
BOSS-EXTRUDE7_4_
BOSS-EXTRUDE7_3_
BOSS-EXTRUDE14_4_
BOSS-EXTRUDE14_2_
BOSS-EXTRUDE14_11_
BOSS-EXTRUDE7_7_
BOSS-EXTRUDE14_9_
BOSS-EXTRUDE14_3_
BOSS-EXTRUDE14_7_
MIRROR2
BOSS-EXTRUDE14_5_
BOSS-EXTRUDE14_12_
BOSS-EXTRUDE7_8_
BOSS-EXTRUDE7_1_
BOSS-EXTRUDE14_10_
BOSS-EXTRUDE7_9_
BOSS-EXTRUDE14_6_
BOSS-EXTRUDE14_1_
BOSS-EXTRUDE7_6_
BOSS-EXTRUDE7_2_
CUT-EXTRUDE5
BOSS-EXTRUDE7_5_
Shield
Pins x 2
U.FL-R-SMT-1_10_ v1

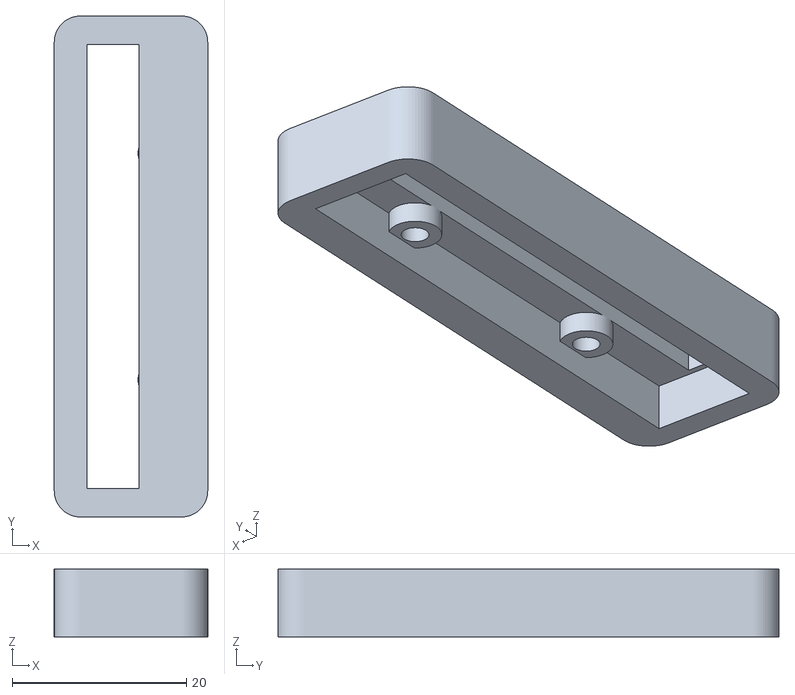
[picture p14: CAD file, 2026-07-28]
hardware/status-light/box-v2/template.stl
17.6 x 57.5 x 7.80

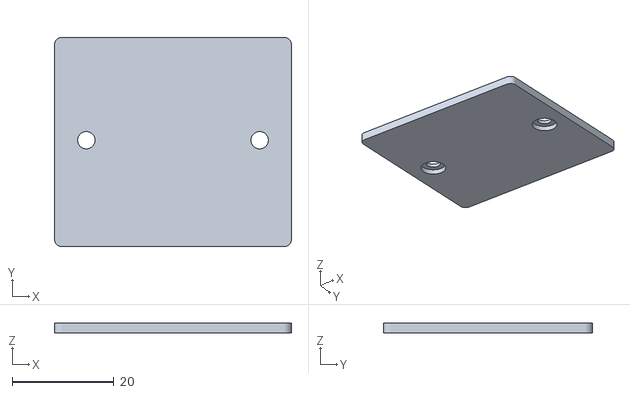
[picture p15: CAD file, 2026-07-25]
hardware/status-light/box-v2/cover.stl
46.5 x 41.1 x 2.00

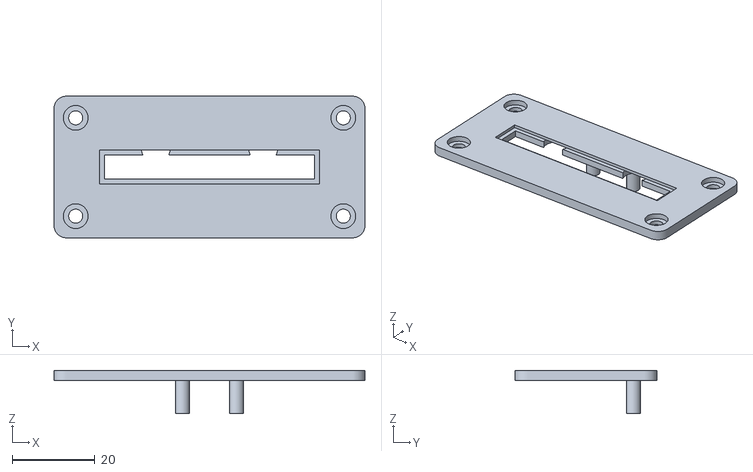
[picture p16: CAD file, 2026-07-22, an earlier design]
hardware/status-light/box/lid.stl
75.3 x 34.3 x 10.4

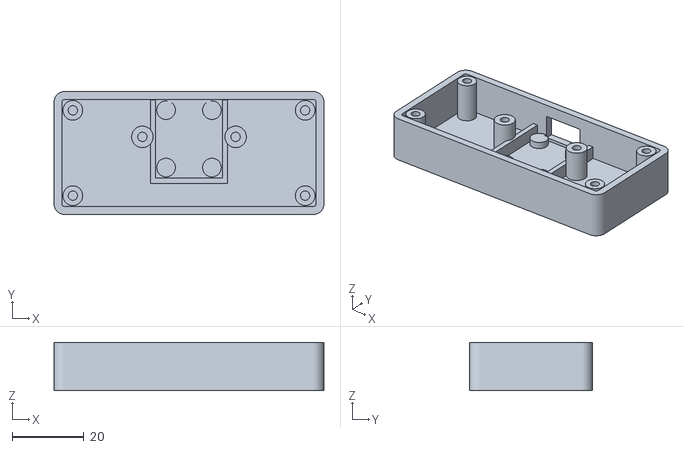
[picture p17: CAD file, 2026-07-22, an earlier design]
hardware/status-light/box/shell.stl
75.3 x 34.3 x 13.5

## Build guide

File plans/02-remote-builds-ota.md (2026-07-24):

# Remote builds → scalable OTA

> **Status (2026-07-24): Phases 1 and 2 BUILT.** Phase 1 is exercised and green — `v0.1.0` is
> released, carrying `firmware-status.bin` + `manifest.json` with a matching sha256, and the binary
> reports a bare `fw v0.1.0` (proof of a clean tag build). Its first run failed on a latent
> `cache: pip` bug in the workflow; see `21b0ec4`. Phase 2 (device-pull OTA) is implemented in
> `src/net_updater.{h,cpp}` and **verified end-to-end on hardware**: the unit pulled `v0.1.2` from
> GitHub by itself and rebooted into it, reporting a bare `fw v0.1.2` (no `-dirty`), which only a
> CI Release binary can produce — proof it is running the artifact it downloaded, not a laptop
> build. Phase 3 (LAN mirror) remains design-only and is probably not worth building here.

Ported from `sonos-nest`'s `plans/06-scalable-ota.md`, which is shipped and fleet-deployed. That
plan's reasoning applies almost verbatim; this file records what's different for rivian-status and
what the actual state here is. **Read the sonos-nest plan for the full rationale** — especially the
two hardware bugs its Phase 2 hardware pass caught (UI/cache contention during flash writes, and
the `HTTPUpdate` task-WDT starvation), because both are traps this project would hit identically.

## Context — the problem being solved

Today firmware reaches the device exactly one way: **espota push** from this laptop (the `/ota`
skill). The laptop holds the `.bin`, mDNS-discovers the IP, and runs `espota.py`. Two independent
problems hide in that:

1. **Binaries come from a laptop.** Nothing reproducible, nothing provenance-stamped. Before this
   plan the firmware didn't even report a version, so "what's running on the device?" was
   unanswerable without reflashing it.
2. **Distribution is push, manual, and only from here.** Fine for one device on this LAN; nothing
   else.

Phase 1 fixes (1) alone and is worth doing on its own — espota still consumes the binary, it just
comes from a Release instead of `.pio/build/`.

## Differences from sonos-nest

| | sonos-nest | rivian-status |
|---|---|---|
| shipping envs | 3 (`nest`/`sleep-machine`/`sleep-button`) | **1** (`phase3`), matrix kept for later |
| unit id | `nest`/`sleep`/`button` | `status` |
| flash / partitions | 16 MB + 8 MB, explicit `*.csv` | 8 MB, framework `default_8MB.csv` (implicit) |
| fleet coordinator | `sonos-portal/` (Pi/HA add-on) mirrors Releases on the LAN | none — GitHub or nothing |
| device reports version | to the portal via `registrationJson()` | status-page footer only |

The partition point matters and was checked: `pio run -e phase3 -t envdump` resolves to the
framework's `default_8MB.csv` — **app0 + app1, 0x330000 (3.19 MB) each**. The app uses ~1.0 MB, so
there is a genuine second OTA slot with ~3× headroom. A pull-OTA path in Phase 2 is viable without
touching the partition layout.

## Phase 1 — CI builds (GitHub Actions → Releases) — BUILT

**Goal:** a `v*` tag produces a GitHub Release with `firmware-status.bin` + `manifest.json`.
Nothing device-side changes; espota now pulls its `.bin` from a Release instead of a laptop dir.

Three pieces:

### `tools/git_version.py` — provenance

PlatformIO pre-script wired into `[env]` via `extra_scripts`, so every env gets
`-DFW_VERSION="<git describe --tags --always --dirty>"`. Surfaced in the phase3 status-page footer
(`webserver.cpp pageFoot()`), which is the only place a running build's identity is visible over
the network.

The suffixes are the whole point:

| build | FW_VERSION |
|---|---|
| CI, clean tree at tag `v0.1.0` | `v0.1.0` |
| laptop, 3 commits past the tag, uncommitted edits | `v0.1.0-3-gabc1234-dirty` |
| no tags in the repo yet | `abc1234` / `abc1234-dirty` |

Only a CI Release build can report a bare tag, so a later version comparison against a manifest
can't be fooled by an ad-hoc build. This needs full history **and tags** in CI — hence
`fetch-depth: 0` + `fetch-tags: true` in the workflow.

### `.github/workflows/firmware.yml`

- **Triggers:** `push` on `v*` tags (builds + publishes a Release) and `workflow_dispatch` (builds
  + uploads artifacts, **no** Release) so CI can be exercised off a branch before tagging.
- **Only `phase3` is built.** `phase1`/`phase2` deliberately `#error` without `include/secrets.h`,
  and `phase6-ledtest` is a wiring smoke-test — none belong in a Release.
- **Platform pinned via `env.PLATFORM` (`espressif32@7.0.1`)** by pre-installing it, so the
  intentionally-unpinned `platform = espressif32` in `platformio.ini` resolves to the version this
  repo is developed against instead of drifting to latest. Bump both together.
- `~/.platformio` is cached, keyed on `platformio.ini` + the workflow file.

### `tools/build_manifest.py`

Reads `bins/firmware-<unit>.bin`, sha256s each, emits:

```json
{
  "version": "v0.1.0",
  "units": {
    "status": {
      "bin":  "firmware-status.bin",
      "url":  "https://github.com/wjduenow/rivian-status/releases/download/v0.1.0/firmware-status.bin",
      "sha256": "…",
      "size": 1016816
    }
  }
}
```

Unit ids are parsed from filenames, so adding an env to the CI matrix adds a manifest entry with no
change to the script. `sha256`/`size` are advisory — they let a Phase 2 firmware add image
verification without a schema change.

### `firmware-status-full.bin` — the cold-flash image

The app binary above lands at `0x10000` and is all OTA needs, but it's useless on a **factory-fresh
board**, which has no bootloader — so a first flash otherwise means building from source. CI now
also publishes a **merged full-flash image**: `esptool merge_bin` (pinned to the toolchain's 4.11.0
— `merge_bin`'s CLI changed in 5.x) stitching the four images a blank board needs into one
flashable at `0x0`:

| offset | image | source |
|---|---|---|
| `0x0` | bootloader | `.pio/build/phase3/bootloader.bin` |
| `0x8000` | partition table | `.pio/build/phase3/partitions.bin` |
| `0xe000` | otadata (boot_app0) | framework `tools/partitions/boot_app0.bin` |
| `0x10000` | app | `.pio/build/phase3/firmware.bin` |

Flash args (`dio` / `80m` / `8MB`) and offsets mirror exactly what `pio run -t upload` issues for
this board — captured from the real esptool invocation, not assumed. Output is ~1.1 MB (sized to
the app's end, not padded to 8 MB), and each region was verified byte-for-byte against the
individual images with `0xFF` fill in the gaps, so a cold flash of it produces a byte-identical
layout to a normal PlatformIO first-flash.

**It must never enter the OTA path.** `HTTPUpdate` writes one app slot, so a device that pulled the
full image would flash the bootloader/partition-table bytes into `app0` and brick. `build_manifest.py`
therefore skips `*-full.bin`, and the manifest lists only `firmware-status.bin`. Users flash the
full image once over USB (esptool at `0x0`, or a WebSerial flasher) and OTA takes over.

### The secrets.h decision (important, and it required a code change)

**CI builds with no `include/secrets.h` at all.** Not a copy of `secrets.h.example` — copying it
would `#define WIFI_SSID "your-ssid"` and thereby *disable* the first-boot SoftAP portal on every
shipped unit.

That didn't work as-inherited. `sonos-nest` was already secrets-optional; rivian-status was not:
`main.cpp`'s `authenticate()` helper (and its `readSerialLine()`/`printRaw()` companions) sat
*outside* any `#ifdef` even though only the phase1/phase2 serial harnesses call it, so a
secrets-less `phase3` build died on `'RIVIAN_EMAIL' was not declared in this scope`. Those three
helpers are now guarded by `#if defined(PHASE1_SMOKE_TEST) || defined(PHASE2_POLL_LOOP)`. Phase 3
logs in from the browser, so it loses nothing.

What that buys, and what it costs:

- A Release binary bakes **no WiFi creds** → still first-boot provisions via the SoftAP portal.
- It bakes **no `SEED_USESS`** → still requires a browser login (and one email OTP) on a device
  whose NVS is empty. On a device that already has a session in NVS, a reflash keeps NVS, so
  nothing is asked. Same as today.
- It bakes **no `OTA_PASSWORD`** → `net_ota.cpp` emits its "OTA is unauthenticated" `#warning` and
  the espota listener comes up passwordless. **Keep a Release-flashed unit on a trusted LAN**
  (plan 01 §11), or flash a locally-built binary for one that isn't. If that becomes unacceptable,
  the fix is to move the OTA password into NVS/`settings` alongside the WiFi creds rather than to
  inject a secret into CI.

## Phase 2 — device-pull OTA — BUILT

`src/net_updater.{h,cpp}` (~210 lines, ported from sonos-nest `src/core/net/updater.cpp`).
`HTTPUpdate` ships with the Arduino core, so **no new dependency**; the build grew ~19 KB
(30.7 % → 31.3 % of the app slot).

**Wiring:** `updaterBegin()` from `setup()` (one check at boot) and `updaterTick()` from the poll
task (self-rate-limited to 6 h). It lives in the poll task deliberately — being there means the
Rivian poll is inherently stopped for the duration of a download, so a flash can't race the shared
TLS client. `/config` gets a Firmware card (source, auto toggle, "Check & update now"); the status
page reports running version, availability, last error, and `esp_reset_reason()`.

**Settings:** `updateUrl` (NVS `upd_url`; empty = AUTO → the compiled-in GitHub
`releases/latest/download/manifest.json`, the literal `off` = never check) and `otaAuto`
(NVS `ota_auto`, **default false**). Checking and applying are separate: availability is always
reported so the page can show it, but nothing self-flashes unless `otaAuto` is on or someone
presses the button.

### ⚠️ Redirects must be set TWICE (cost a release to find)

`HTTPUpdate` builds its **own internal `HTTPClient`**, so
`setFollowRedirects(HTTPC_STRICT_FOLLOW_REDIRECTS)` on the manifest fetch does **not** carry over to
the firmware download — it needs `httpUpdate.setFollowRedirects(...)` of its own. GitHub 302s a
release asset to a signed CDN host, so without it the pull dies before transferring a byte with
`flash failed (-104) Wrong HTTP Code`. That's exactly how the first live pull failed on `v0.1.1`;
everything either side was already right (the device fetched the manifest, compared versions, and
reported "v0.1.1 available"). Fixed in `v0.1.2`.

**Ported verbatim, because they were real resets on sonos-nest hardware:**
1. **Yield during the download.** `HTTPUpdate`'s loop never yields; unfixed it starves IDLE and the
   task WDT resets the device mid-transfer. `delay(1)` per progress chunk. Doubly needed here —
   the poll task shares core 1 with `loop()`, so a non-yielding download also freezes
   `ledsLoop()`/`webAppLoop()`.
2. **Quiesce before flash writes.** `s_active` + a 400 ms beat before erasing, and `loop()` skips
   `otaHandle()` while it's set (two writers to the OTA slots is the one way to brick this).

**Divergence from sonos-nest, deliberate:** sonos-nest auto-applies only at BOOT so it can never
yank firmware out from under a playing sleep-machine. This unit has nothing to interrupt and can
run for months without rebooting, so boot-only would mean auto-update almost never fires — here an
`otaAuto` device also applies on the periodic check.

**Free win:** the LED strip's existing blue OTA progress bar now also renders pull-flash progress
(`updaterActive()`/`updaterProgress()` feed the same branch) — visible only because of the yield above.

### ⚠️ A real bug found in the ported version-compare (fixed here, still present upstream)

Comparison is **strictly newer**, never "different" — sonos-nest shipped a release specifically to
kill a downgrade loop. Its `parseVer()` accepts any string starting with a digit, which is wrong:
`git describe` emits a **bare commit hash** before a repo's first tag, hashes are hex, so ~10 in 16
start with a digit. `2591c5d-dirty` — the build that was on this device — parsed as version
**2591.0.0** and outranked every real release, so the device would have reported "up to date"
forever and never updated. sonos-nest never hit it only because it had tags from the start.

Fixed by requiring each numeric field to end at `.`, `-`, or end-of-string, and requiring at least
`major.minor`. Verified by compiling the real `parseVer`/`isNewer` natively against 15 cases
(same-version, downgrade refusal, post-tag dev builds sorting newer than their tag, `0.10 > 0.9`
numerically, and all four hash shapes). **Worth back-porting to sonos-nest.**

## Phase 3 — LAN mirror (DESIGN ONLY, likely NOT worth it here)

sonos-nest's portal mirrors Releases so devices never touch GitHub, and gives a fleet dashboard
with per-device approve. With one device and no existing always-on service in this project, that's
a lot of infrastructure for nothing. If it's ever wanted, the cheap version is pointing this
device's `updateUrl` at the **existing sonos-portal** rather than building a second one.

## Non-goals

Signed / secure-boot OTA. LAN, plain HTTP, hobby appliance — same call as plan 01 §11.

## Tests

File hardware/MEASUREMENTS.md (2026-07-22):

# MEASUREMENTS — every number the enclosure is built from

One place for all the dimensions in `hardware/`. Everything here is the single source of
truth `status-light/box/case_params.py` reads from; this doc is the human-readable index.
Provenance tags:

- **CAD** — read off Seeed's official STEP (`status-light/ref/XIAO-ESP32S3 v2.step`), measured in mm.
- **MEAS** — calipered off the physical part by the user.
- **SPEC** — datasheet / standard part.
- **DERIVED** — computed from the above in `case_params.py` (not a free choice).
- **CHOICE** — a design value (wall thickness, clearances, etc.).

All values in **millimetres**. Frame: **+X** width (long axis) · **+Y** depth (front→back) ·
**+Z** up. Origin centred in X/Y, z = 0 at the floor's underside.

---

## 1. XIAO ESP32-S3 board  (source: CAD)

| Dimension | Value | Src |
|---|---|---|
| PCB length (USB-C ↔ antenna axis) | **21.0** | CAD |
| PCB width | **17.8** | CAD |
| PCB thickness | **1.25** | CAD |
| Bottom side | **flat** (no tall parts) | CAD |
| Tallest top part (USB-C shell) above PCB back | **4.21** | CAD |
| RF-shield height above PCB back | 3.00 | CAD |
| **Screw mounting holes** | **NONE** (retained by edges/box) | CAD |
| USB-C overhang past PCB edge | **1.53** | CAD |
| USB-C shell width | **8.94** | CAD |
| USB-C aperture height | **3.26** | CAD |
| USB-C aperture centre above PCB back face | **2.36** | CAD |
| U.FL jack — along length from board centre | **−6.95** | CAD |
| U.FL jack — offset across width | **4.73** | CAD |
| U.FL jack — height above PCB top face | **1.25** | CAD |

Wires solder **directly to the pads** (no header) → the board back is flat and lies on the
standoffs.

## 2. WS2812 LED stick — generic bare 8-bit  (source: MEAS)

| Dimension | Value | Src |
|---|---|---|
| Length | **51.5** | MEAS |
| Width (short edge) | **10.0** | MEAS |
| PCB thickness | **1.6** | MEAS (3.0 total − 1.4 domes) |
| Dome height above PCB face | **1.4** | MEAS |
| Total thickness incl. LEDs | **3.0** | MEAS |
| Pixel count | **8** | fixed (firmware, plan §7) |
| Lit span (first→last LED centre) | **45.0** | MEAS |
| LED square (emitter) | **4.75** | MEAS |
| Emitter extent (lit span + emitter) | **49.75** | DERIVED |
| Mounting holes | **2**, Ø **3.75** | MEAS |
| Hole positions along length (±X from centre) | **±13.0** (26 mm apart) | MEAS |
| Hole offset off the LED row (toward one edge) | **4.5** | MEAS |

## 3. Fasteners  (M3 self-tapping into printed bosses — source: CHOICE/SPEC)

| Item | Value |
|---|---|
| Thread-forming pilot Ø (M3) | 2.6 |
| Stick → post screws | 2× **M3 × 6** (through Ø3.75 holes) |
| Lid → side-wall bosses | 4× **M3 × 8**, countersunk (Ø3.4 clearance, Ø6 csk) |

## 4. Enclosure — shell + lid  (source: CHOICE, then DERIVED)

| Dimension | Value | Src |
|---|---|---|
| Wall thickness | 2.2 | CHOICE |
| Floor thickness | 2.0 | CHOICE |
| Lid thickness | 2.5 | CHOICE |
| Board standoff height | 2.0 | CHOICE |
| Stick-mount post Ø | 6.0 | CHOICE |
| Stick PCB underside height (`STRIP_BOTTOM_Z`) | 11.0 | CHOICE (clears board + antenna plug) |
| LED dome tops below the case top (`LED_BELOW_TOP`) | 2.0 | CHOICE |
| Lid window (X × Y) | **51.0 × 6.0** | DERIVED (covers all emitters) |
| Lid board-clamp pads | 2× Ø3.4, **13.1 mm apart**, straddling the 9 mm USB-C shell | DERIVED |
| Lid screw-head relief pockets | 2× Ø7, above the stick screws (heads ~level with LEDs) | CHOICE |
| USB-C port (back wall, X × Z) | 12.0 × 7.0 | CHOICE |
| Antenna pigtail exit slot | **none** (`ANT_EXIT = False`, antenna coils inside) | CHOICE |
| Room beyond each strip end (`STRIP_END_GAP`) | 9.7 (for the soldered end-wires) | CHOICE |
| Front working bay (`BOARD_FRONT_GAP`) | 8.4 (wires + antenna coil) | CHOICE |
| **Outer size (X × Y × Z)** | **75.3 × 34.3 × 16.0** | DERIVED |
| Shell rim height (`SHELL_H`) | 13.5 | DERIVED |
| Interior (X × Y) | 70.9 × 29.9 | DERIVED |

### Layout in one line
XIAO lies flat on the floor (centred), USB-C proud out the **back wall**; the LED stick is
screwed to two posts **above** it (LEDs up), showing through the lid window 2 mm under the
top; U.FL antenna coils inside; four M3 screws hold the lid.

## 5. Still worth a caliper pass before a final print
- **Hole offset** (`LED_HOLE_DY`, 1.5) direction + amount — dialled from the board photo/feel.
- **DIN end** orientation (`LED_DIN_AT_PLUS_X`) — cosmetic (shortest D0 wire run).
- **Peg/boss/hole fits** print tight in FDM — run a test coupon.

> To change any number: edit `status-light/box/case_params.py`, then
> `conda run -n img23d python build_all.py`. `build_shell.py` asserts its own clearances,
> so an illegal edit fails loudly instead of writing a broken STL.

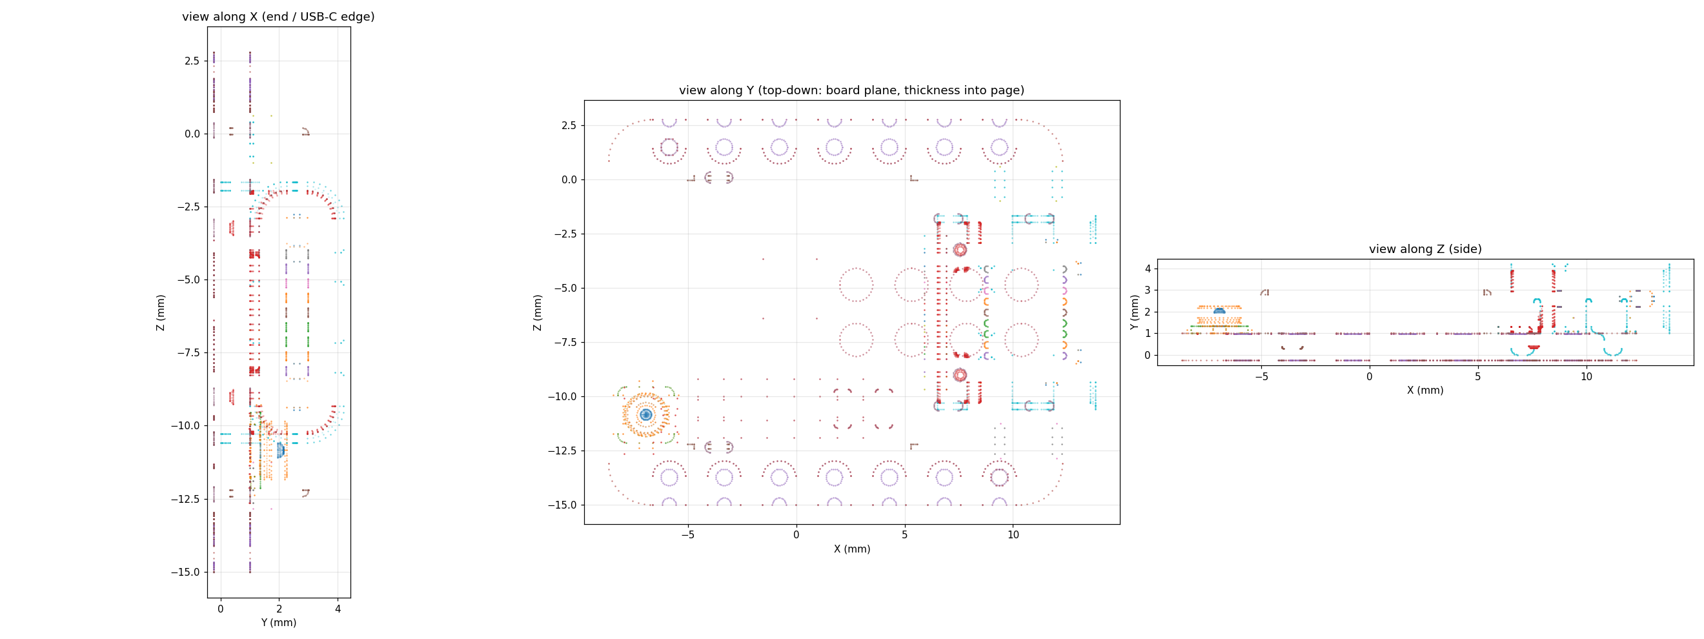
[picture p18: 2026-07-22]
hardware/status-light/ref/xiao_ortho_measured.png

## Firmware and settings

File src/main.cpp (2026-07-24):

// rivian-status — serial-only test harnesses for Phases 1 & 2 (plan §10).
//
//   -DPHASE1_SMOKE_TEST : one-shot auth + telemetry test; records the Phase 1 deliverables
//                         (distanceToEmpty units + chargerState/chargePortState enum values).
//   -DPHASE2_POLL_LOOP  : authenticate once, then poll getVehicleState on a 30 s cadence with
//                         exponential backoff and the lowRange check (plan §5/§6).
//
// Both share the same network + auth bring-up below. Creds are hard-coded in include/secrets.h
// for these phases only; the shipped firmware never persists the password (plan §1).

#include <Arduino.h>
#include <WiFi.h>
#include <time.h>
#include <math.h>

#include "rivian_api.h"
#include "settings.h"
#include "webserver.h"
#include "net_wifi.h"
#include "net_ota.h"
#include "net_updater.h"
#include "leds.h"

#if __has_include("secrets.h")
#include "secrets.h"
#endif

// Phases 1 & 2 hard-code creds in secrets.h. Phase 3 provisions WiFi via the portal and logs in
// via the browser, so it doesn't require the macros.
#if (defined(PHASE1_SMOKE_TEST) || defined(PHASE2_POLL_LOOP)) && (!defined(WIFI_SSID) || !defined(RIVIAN_EMAIL))
#error "Copy include/secrets.h.example to include/secrets.h and fill in your credentials."
#endif

// ===========================================================================
// Shared helpers
// ===========================================================================
static void rule(const char* label) {
  Serial.printf("\n========== %s ==========\n", label);
}

#if defined(PHASE1_SMOKE_TEST) || defined(PHASE2_POLL_LOOP)
static void printRaw() {
  Serial.println("--- raw response ---");
  Serial.println(RivianApi::lastRaw());
  Serial.println("--------------------");
}
#endif

// Halt: park the CPU so a one-shot test doesn't loop.
static void halt(const char* why) {
  Serial.printf("\n[HALT] %s\n", why);
  for (;;) delay(1000);
}

// Connect via the Net module (hostname = device name, NVS creds then secrets.h). Returns false
// on timeout so the caller decides: halt (dev serial tests) or raise the portal (the appliance).
static bool connectWifi() {
  rule("WiFi");
  Serial.printf("Connecting as \"%s\"...\n", Net::hostname().c_str());
  if (!Net::connect(20000)) return false;
  Serial.printf("Connected. IP=%s  RSSI=%d dBm  host=%s\n",
                Net::ip().toString().c_str(), WiFi.RSSI(), WiFi.getHostname());
  return true;
}

// TLS cert-validity checks need a real wall clock. Sync SNTP before any HTTPS.
static bool syncTime() {
  rule("NTP time sync");
  configTime(0, 0, "pool.ntp.org", "time.nist.gov");
  time_t now = 0;
  uint32_t start = millis();
  while ((now = time(nullptr)) < 1700000000 && millis() - start < 15000) {
    delay(250);
    Serial.print(".");
  }
  Serial.println();
  if (now < 1700000000) {
    Serial.println("FAILED — no NTP; TLS cert validation will likely fail.");
    return false;
  }
  Serial.printf("Time set: %s", asctime(gmtime(&now)));  // asctime adds \n
  return true;
}

#if defined(PHASE1_SMOKE_TEST) || defined(PHASE2_POLL_LOOP)
// Blocking read of one line from serial (for the MFA OTP). Echoes as typed.
static String readSerialLine(const char* prompt) {
  Serial.print(prompt);
  String line;
  for (;;) {
    while (!Serial.available()) delay(10);
    char c = (char)Serial.read();
    if (c == '\r') continue;
    if (c == '\n') break;
    line += c;
    Serial.print(c);
  }
  Serial.println();
  line.trim();
  return line;
}
#endif  // PHASE1_SMOKE_TEST || PHASE2_POLL_LOOP

// Settings + WiFi + NTP + API init. `provision`: on WiFi failure, raise the SoftAP captive portal
// (the appliance) instead of halting (dev serial tests). Settings load first — the DHCP hostname
// is the device name and must be known before WiFi associates.
static void bringUpNetwork(bool provision) {
  Settings::begin();
  if (!connectWifi()) {
    if (provision) {
      Serial.println("No WiFi — raising setup portal (join \"<name>-setup\").");
      Net::runPortal();                // blocks until joined; reboots on success
    } else {
      halt("no WiFi (check creds / antenna)");
    }
  }
  syncTime();                          // continue even if it fails, to surface the TLS error
  RivianApi::begin();
  Serial.printf("dc-cid (persistent): %s\n", RivianApi::dcCid().c_str());
#ifdef SEED_USESS
  // One-time bootstrap: inject an out-of-band u-sess (from secrets.h, gitignored) if NVS has none,
  // so the reuse path can be exercised without a fresh login/OTP. Remove once NVS is seeded.
  if (!RivianApi::hasSession()) {
    RivianApi::seedSession(SEED_USESS);
    Serial.println("[seed] injected u-sess from build define");
  }
#endif
  Serial.printf("persisted session present: %s\n", RivianApi::hasSession() ? "yes" : "no");
}

// Full auth handshake: CSRF -> Login -> (OTP over serial if MFA) -> getUserInfo. Shared by the two
// serial harnesses only — Phase 3 logs in from the browser (webserver.cpp), so this is compiled
// out there. That matters for CI: it's the only code that reads RIVIAN_EMAIL/RIVIAN_PASSWORD, and
// a Release build of phase3 is made with NO include/secrets.h at all (see .github/workflows/).
// `verbose` dumps raw responses (Phase 1 wants them). Returns true once the VIN is cached.
#if defined(PHASE1_SMOKE_TEST) || defined(PHASE2_POLL_LOOP)
static bool authenticate(bool verbose) {
  // Fast path (plan §4): if a u-sess was persisted from a prior run, reuse it — mint a fresh CSRF
  // (which yields a new a-sess) and prove the session with getUserInfo. No login, no MFA/OTP.
  // This is what makes resets/reflashes painless once you've authenticated once.
  if (RivianApi::hasSession()) {
    rule("Auth: reuse persisted u-sess (no login/OTP)");
    if (RivianApi::createCsrf() && RivianApi::fetchVin()) {
      Serial.printf("Session reuse OK. Vehicle: name=\"%s\"  vin=%s  id=%s\n",
                    RivianApi::vehicleName().c_str(), RivianApi::vin().c_str(),
                    RivianApi::vehicleId().c_str());
      return true;
    }
    Serial.printf("Persisted u-sess invalid (%s) — clearing, falling back to full login.\n",
                  RivianApi::lastError().c_str());
    RivianApi::clearSession();
  }

  rule("Auth: CreateCSRFToken");
  if (!RivianApi::createCsrf()) { printRaw(); Serial.printf("CSRF failed: %s\n", RivianApi::lastError().c_str()); return false; }
  if (verbose) printRaw();
  Serial.println("OK — csrf-token + a-sess acquired.");

  rule("Auth: Login");
  RivianApi::LoginResult lr = RivianApi::login(RIVIAN_EMAIL, RIVIAN_PASSWORD);
  if (verbose) printRaw();
  if (lr == RivianApi::LOGIN_ERROR) { if (!verbose) printRaw(); Serial.printf("Login failed: %s\n", RivianApi::lastError().c_str()); return false; }

  if (lr == RivianApi::LOGIN_MFA_REQUIRED) {
    rule("Auth: LoginWithOTP (MFA)");
    Serial.println("MFA enabled — Rivian just sent a code to your email.");
    String otp = readSerialLine("Enter OTP code, then press Enter: ");
    if (!RivianApi::completeOtp(RIVIAN_EMAIL, otp)) { printRaw(); Serial.printf("OTP failed: %s\n", RivianApi::lastError().c_str()); return false; }
    if (verbose) printRaw();
    Serial.println("OK — OTP accepted, u-sess acquired.");
  } else {
    Serial.println("No MFA — u-sess acquired directly.");
  }

  rule("Auth: getUserInfo (fetch VIN)");
  if (!RivianApi::fetchVin()) { printRaw(); Serial.printf("getUserInfo failed: %s\n", RivianApi::lastError().c_str()); return false; }
  if (verbose) printRaw();
  Serial.printf("Vehicle: name=\"%s\"  vin=%s  id=%s\n",
                RivianApi::vehicleName().c_str(), RivianApi::vin().c_str(),
                RivianApi::vehicleId().c_str());

  // We just did a full login (this path only runs when session-reuse failed / no stored token).
  // The u-sess is now persisted to NVS, but print it too so you can refresh SEED_USESS in
  // secrets.h — then even an NVS wipe won't force another OTP until this token expires.
  Serial.println("\n>>> Fresh login complete. To keep re-images OTP-free, set in include/secrets.h:");
  Serial.printf(">>>   #define SEED_USESS \"%s\"\n", RivianApi::userSession().c_str());
  return true;
}
#endif  // PHASE1_SMOKE_TEST || PHASE2_POLL_LOOP

// ===========================================================================
// PHASE 1 — one-shot smoke test
// ===========================================================================
#if defined(PHASE1_SMOKE_TEST)

void setup() {
  Serial.begin(115200);
  delay(2000);                         // let USB-CDC enumerate before the first prints
  Serial.println("\n\n### rivian-status — Phase 1 auth smoke-test ###");

  bringUpNetwork(/*provision=*/false);
  if (!authenticate(/*verbose=*/true)) halt("auth failed");

  rule("getVehicleState");
  VehicleStatus st;
  if (!RivianApi::pollState(st)) { printRaw(); halt(RivianApi::lastError().c_str()); }
  printRaw();
  if (!RivianApi::lastError().isEmpty())
    Serial.printf("[note] %s\n", RivianApi::lastError().c_str());

  // -------- Phase 1 deliverables (plan §10) --------
  rule("PHASE 1 DELIVERABLES — record these");
  Serial.printf("batteryLevel     : %.1f %%\n", st.batteryLevel);
  Serial.printf("batteryLimit     : %.0f %%   (charge target — where charging stops)\n", st.batteryLimit);
  Serial.printf("timeToEndOfCharge: %d min\n", st.timeToEndOfCharge);
  Serial.printf("chargerState     : \"%s\"   <-- record this enum value\n", st.chargerState.c_str());
  Serial.printf("chargePortState  : \"%s\"   <-- record this enum value\n", st.chargePortState.c_str());
  Serial.printf("distanceToEmpty  : %.1f  (units UNCONFIRMED)\n", st.distanceToEmpty);
  Serial.printf("  timeStamp      : %s\n", st.timeStamp.c_str());
  Serial.println();
  Serial.println(">>> UNITS CHECK: open the Rivian app and compare its displayed range to the");
  Serial.printf(">>> distanceToEmpty above (%.1f). If the app shows ~%.0f mi, units are MILES;\n",
                st.distanceToEmpty, st.distanceToEmpty);
  Serial.printf(">>> if the app shows a number ~1.6x larger (~%.0f), the API value is in KM.\n",
                st.distanceToEmpty * 1.60934);
  Serial.println(">>> Then set RANGE_THRESHOLD_X (platformio.ini phase2) in the confirmed unit.");
  Serial.println();
  Serial.println(">>> To map §7 LEDs, re-run in different charge states (unplugged, plugged-idle,");
  Serial.println(">>> charging, complete, fault) and record each chargerState/chargePortState value.");

  rule("DONE");
  Serial.println("Auth + telemetry path verified end-to-end against the real account.");
}

void loop() { delay(1000); }           // one-shot; poll loop is Phase 2

// ===========================================================================
// PHASE 2 — continuous poll loop (plan §5/§6)
// ===========================================================================
#elif defined(PHASE2_POLL_LOOP)

static const uint32_t POLL_INTERVAL_S = 30;      // base cadence (plan §5)
static const uint32_t BACKOFF_CAP_S   = 900;     // exponential-backoff ceiling (plan §5)

#ifndef RANGE_THRESHOLD_X
#define RANGE_THRESHOLD_X 50                      // fallback if the build flag is missing
#endif

static uint32_t s_errCount = 0;                  // drives min(30 * 2^n, 900) backoff

// Sleep in 1 s steps so a long backoff still feels responsive on the console.
static void sleepSeconds(uint32_t s) {
  for (uint32_t i = 0; i < s; i++) delay(1000);
}

void setup() {
  Serial.begin(115200);
  delay(2000);
  Serial.println("\n\n### rivian-status — Phase 2 poll loop ###");
  Serial.printf("Poll cadence %us, backoff cap %us, rangeThresholdX=%d miles (API km -> mi)\n",
                POLL_INTERVAL_S, BACKOFF_CAP_S, (int)RANGE_THRESHOLD_X);

  bringUpNetwork(/*provision=*/false);
  if (!authenticate(/*verbose=*/false)) halt("initial auth failed");
  Serial.println("\nAuthenticated. Entering poll loop.");
}

void loop() {
  VehicleStatus st;
  if (RivianApi::pollState(st)) {
    s_errCount = 0;                              // reset backoff on success

    // lowRange = distanceToEmpty < X (plan §6). Charging-aware annotation is free (§7): when
    // low AND charging, the alert would "pulse" rather than sit steady. chargerState enum
    // values are TBD (Phase 1), so we match on a substring heuristic for now.
    // distanceToEmpty is KILOMETERS (Phase 1 confirmed); convert to miles for the US threshold.
    float rangeMiles = isnan(st.distanceToEmpty) ? NAN : st.distanceToEmpty / 1.60934f;
    bool lowRange  = !isnan(rangeMiles) && rangeMiles < RANGE_THRESHOLD_X;
    // chargerState=="charging_active" seen in Phase 1; keep a substring match for other states.
    String cs = st.chargerState; cs.toLowerCase();
    bool charging  = cs.indexOf("charg") >= 0 && cs.indexOf("not") < 0;

    // "charge complete" ≈ current has reached the target (more reliable than chargerState alone).
    bool atTarget = !isnan(st.batteryLevel) && !isnan(st.batteryLimit) &&
                    st.batteryLevel >= st.batteryLimit - 0.5f;
    Serial.printf("[poll] soc=%.1f%% / limit %.0f%%  range=%.0f mi (%.0f km)  charger=\"%s\"  port=\"%s\"  eta=%dmin%s\n",
                  st.batteryLevel, st.batteryLimit, rangeMiles, st.distanceToEmpty,
                  st.chargerState.c_str(), st.chargePortState.c_str(), st.timeToEndOfCharge,
                  atTarget ? "  [at target]" : "");
    if (lowRange) {
      Serial.printf("  >>> LOW RANGE (%.0f mi < %d mi)%s\n", rangeMiles, (int)RANGE_THRESHOLD_X,
                    charging ? " — but charging (would pulse)" : " — not charging (would be steady red)");
    }
    sleepSeconds(POLL_INTERVAL_S);
  } else {
    s_errCount++;
    Serial.printf("[poll] error (#%lu): %s\n", (unsigned long)s_errCount, RivianApi::lastError().c_str());

    // Reactive token model (plan §4): on any failure, mint a fresh CSRF (reuses the still-valid
    // u-sess) before retrying — this silently recovers from an expired a-sess/csrf. Only a full
    // re-login (owner + OTP) would be needed if u-sess itself has died; that surfaces as repeated
    // failures here and, in the shipped firmware, lights the "re-auth needed" LED (§7).
    if (!RivianApi::createCsrf())
      Serial.printf("  re-CSRF also failed: %s (u-sess may be dead → re-login needed)\n",
                    RivianApi::lastError().c_str());
    else
      Serial.println("  re-CSRF ok — will retry poll after backoff");

    uint32_t backoff = POLL_INTERVAL_S << (s_errCount > 5 ? 5 : s_errCount);  // 30 * 2^n, clamp shift
    if (backoff > BACKOFF_CAP_S) backoff = BACKOFF_CAP_S;
    Serial.printf("  backing off %us\n", backoff);
    sleepSeconds(backoff);
  }
}

// ===========================================================================
// PHASE 3 — browser UI (status + login + config) with a background poll task
// ===========================================================================
#elif defined(PHASE3_WEBAPP)

void setup() {
  Serial.begin(115200);
  delay(2000);
  Serial.println("\n\n### rivian-status — Phase 3 web app ###");

  bringUpNetwork(/*provision=*/true);      // Settings + WiFi (portal fallback) + NTP + RivianApi
  webAppBegin();                           // mDNS + HTTP server + poll task (reuses u-sess)
  otaBegin();                              // ArduinoOTA as <device name>.local
  updaterBegin();                          // one pull-OTA check (plan 02 §2); may flash + reboot
  ledsBegin();                             // 8-pixel WS2812 status map on D10/GPIO9 (§7)

  Serial.printf("Web UI: http://%s/  (or http://%s.local/)\n",
                WiFi.localIP().toString().c_str(), Settings::deviceName().c_str());
  Serial.printf("Persisted session: %s — %s\n",
                RivianApi::hasSession() ? "yes" : "no",
                RivianApi::hasSession() ? "polling starts automatically"
                                        : "open /login in a browser to authenticate");
}

void loop() {
  webAppLoop();
  // Don't service espota pushes while a pull-flash is writing — two writers to the OTA slots at
  // once is the one way to brick this. ledsLoop() still runs, so the strip shows the blue bar.
  if (!updaterActive()) otaHandle();
  ledsLoop();                              // re-render the status pixels (~50 Hz, self-limited)
  delay(2);
}

#else
#error "Define PHASE1_SMOKE_TEST, PHASE2_POLL_LOOP, or PHASE3_WEBAPP (select env:phase1/2/3)."
#endif

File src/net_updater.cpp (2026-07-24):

// See net_updater.h. HTTP pull-OTA against the plan-02 manifest schema.
#include "net_updater.h"
#include "settings.h"
#include "net_ota.h"        // otaActive() — never pull-flash while an espota push is running

#include <WiFi.h>
#include <WiFiClientSecure.h>
#include <HTTPClient.h>
#include <HTTPUpdate.h>
#include <ArduinoJson.h>

// Injected per build by tools/git_version.py (git describe --tags --always --dirty). Only a clean
// CI tag build reports a bare "v0.1.0"; laptop builds carry -N-g<hash>[-dirty], which parseVer()
// deliberately sorts NEWER than the tag so the updater never downgrades a dev build.
#ifndef FW_VERSION
#define FW_VERSION "dev"
#endif

// Default source when the setting is empty (AUTO). The `latest/download/<asset>` form is stable
// and follows every new Release, so no version is baked in. Override per fork with -D.
#ifndef UPDATE_MANIFEST_URL
#define UPDATE_MANIFEST_URL "https://github.com/wjduenow/rivian-status/releases/latest/download/manifest.json"
#endif

// This unit's key in the manifest. rivian-status ships exactly one env; the schema stays
// multi-unit so a second board is a CI matrix row rather than a rewrite.
static const char* kUnitId = "status";

static const uint32_t kCheckMs = 6UL * 60 * 60 * 1000;   // 6 h between periodic checks

static String        s_available;            // available version, "" if none/up-to-date/disabled
static String        s_lastError;
static bool          s_armed     = false;    // explicit approve -> apply on the next check
static bool          s_force     = false;    // bypass the rate limit once
static uint32_t      s_lastCheck = 0;
static bool          s_everChecked = false;
static volatile bool s_active   = false;
static volatile int  s_progress = -1;

bool   updaterActive()           { return s_active; }
int    updaterProgress()         { return s_progress; }
bool   updaterAvailable()        { return s_available.length() > 0; }
String updaterAvailableVersion() { return s_available; }
String updaterLastError()        { return s_lastError; }
void   updaterApprove()          { s_armed = true; s_force = true; }
void   updaterForceCheck()       { s_force = true; }

// Resolve the effective source. kindOut, if given, gets a static label for the UI.
static String resolveUrl(const char** kindOut) {
  String stored = Settings::updateUrl();
  if (stored == "off") { if (kindOut) *kindOut = "off";    return String(); }
  if (stored.length()) { if (kindOut) *kindOut = "custom"; return stored;   }
  if (kindOut) *kindOut = "github";
  return String(UPDATE_MANIFEST_URL);
}

String      updaterEffectiveUrl() { return resolveUrl(nullptr); }
const char* updaterSourceKind()   { const char* k = "off"; resolveUrl(&k); return k; }

// GET a small body over HTTP or HTTPS.
//
// HTTPS uses an INSECURE client — deliberately, and worth understanding: rivian_api.cpp pins
// Amazon Root CA 1 for the Rivian endpoint, so this is the one unvalidated TLS path in the
// firmware. Pinning GitHub's chain is brittle across their cert rotations, and the manifest only
// selects a version — the binary itself is still validated by the ESP32 bootloader's image check
// before anything boots from it. Same LAN/hobby threat model as plan 01 §11.
//
// Redirects MUST be followed: GitHub 302s release assets off to a signed CDN host (currently
// release-assets.githubusercontent.com — it has changed before, so never hard-code it).
//
// Templated because HTTPClient::begin() wants a concrete WiFiClient& and WiFiClientSecure derives
// from it; a template keeps one body for both.
template <typename C>
static bool doGet(HTTPClient& http, C& client, const String& url, String& body) {
  if (!http.begin(client, url)) return false;
  http.setFollowRedirects(HTTPC_STRICT_FOLLOW_REDIRECTS);
  http.setConnectTimeout(5000);
  http.setTimeout(8000);
  int code = http.GET();
  bool ok = (code == HTTP_CODE_OK);
  if (!ok) s_lastError = "manifest HTTP " + String(code);
  if (ok) body = http.getString();
  http.end();
  return ok;
}

static bool httpGetString(const String& url, String& body) {
  HTTPClient http;
  if (url.startsWith("https:")) {
    WiFiClientSecure sec;
    sec.setInsecure();
    return doGet(http, sec, url, body);
  }
  WiFiClient cl;
  return doGet(http, cl, url, body);
}

// Fetch the manifest and pull out this unit's entry.
static bool checkManifest(const String& base, String& version, String& url) {
  if (base.isEmpty()) return false;

  String body;
  if (!httpGetString(base, body)) return false;

  JsonDocument doc;
  if (deserializeJson(doc, body)) { s_lastError = "manifest parse failed"; return false; }

  JsonObject u = doc["units"][kUnitId];
  if (u.isNull()) { s_lastError = String("no \"") + kUnitId + "\" unit in manifest"; return false; }
  const char* urlp = u["url"];
  if (!urlp) { s_lastError = "unit has no url"; return false; }

  version = doc["version"] | "";
  url     = urlp;
  if (version.isEmpty()) { s_lastError = "manifest has no version"; return false; }
  s_lastError = "";
  return true;
}

// Parse "vX.Y.Z[-N[-gHASH[-dirty]]]" (git describe form) into [major,minor,patch,commits]. The
// commit count is the 4th field so a post-tag laptop build sorts NEWER than its tag — that is what
// stops the updater from trying to "update" a dev build back to the release it was built past.
// Returns false when the string isn't a numeric version (a bare commit hash), so the caller can
// fall back to inequality.
static bool parseVer(const String& s, long v[4]) {
  v[0] = v[1] = v[2] = v[3] = 0;
  int i = 0, n = s.length();
  if (i < n && (s[i] == 'v' || s[i] == 'V')) i++;

  int fields = 0;
  while (fields < 3 && i < n && isdigit((int)s[i])) {
    long num = 0;
    while (i < n && isdigit((int)s[i])) { num = num * 10 + (s[i] - '0'); i++; }
    v[fields++] = num;
    if (i >= n) break;
    if (s[i] == '.') { i++; continue; }
    if (s[i] == '-') break;
    // A numeric field ended on something that isn't '.' / '-' / end — so this is not a version.
    // ⚠️ This check is why the whole function exists in this shape: `git describe` emits a BARE
    // COMMIT HASH before the repo's first tag, and hashes are hex, so ~10 in 16 start with a
    // digit. Without this, "2591c5d-dirty" parsed as version 2591.0.0 and outranked every real
    // release — a device on a pre-tag build would report "up to date" forever and never update.
    // (Inherited from sonos-nest, where having tags from the start masked it.)
    return false;
  }
  // Need at least major.minor. A lone run of digits with no dot ("1234567") is a hash, not a tag.
  if (fields < 2) return false;

  if (i < n && s[i] == '-') {                 // "-N" commits past the tag
    i++;
    long num = 0; bool got = false;
    while (i < n && isdigit((int)s[i])) { num = num * 10 + (s[i] - '0'); i++; got = true; }
    if (got) v[3] = num;
  }
  return true;
}
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

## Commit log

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2026-07-21 Phase 1 live findings: km range, id-not-VIN key, float batteryLevel
    Verified the full auth + telemetry path against the real vehicle (CSRF ->
    Login -> MFA-OTP -> getUserInfo -> getVehicleState). Corrections from the
    live run (2026-07-21):
    - distanceToEmpty is in KILOMETERS; the US app shows miles (391 km ~= 244 mi
    live). Firmware now converts km->mi; the range threshold is in miles.
    - vehicleState(id:) takes the vehicle *id* (e.g. 01-244090061), NOT the VIN
    (VIN returns NOT_FOUND). pollState() now keys on id first.
    - batteryLevel is a FLOAT (59.700001), not an int; the int-default parse was
    returning -1. VehicleStatus.batteryLevel is now float and parsed as such.
    - Captured enum value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
    [main.cpp]
2026-07-21 Persist u-sess to NVS and reuse it on boot (no OTP on reset/reflash)
    Implements the plan §4 reactive token model: after a successful login/OTP,
    rivian_api saves u-sess to NVS; begin() loads it; authenticate() reuses it by
    minting a fresh CSRF (new a-sess) and verifying with getUserInfo, skipping the
    login/MFA dance. On a stale token, reads fail, the session is cleared, and it
    falls back to full login.
    Verified live 2026-07-21: a reset reused a ~40-min-old u-sess and pulled
    vehicle state with no login and no OTP (also confirming the batteryLevel-float
    and id-key fixes: batteryLevel read 60.7%, single id-keyed poll, no VIN error).
    Adds seedSession() to restore a u-sess out-of-band (backup r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
    [main.cpp]
2026-07-21 Print fresh u-sess after login so re-images stay OTP-free
    A normal reflash preserves NVS, so the persisted u-sess already survives
    re-imaging without an OTP. This closes the two remaining gaps:
    - On a real login (session-reuse failed / NVS wiped), print the new u-sess and
    the exact `#define SEED_USESS "..."` line to paste into secrets.h.
    - Combined with SEED_USESS in the gitignored secrets.h, the firmware auto-seeds
    NVS whenever it's empty (fresh board / erase_flash), so OTP is needed only
    when the token actually expires — never just from re-flashing.
    Adds RivianApi::userSession() accessor.
    Claude-Session: https:/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
    [main.cpp]
2026-07-21 Fix serial strings: threshold is miles, OTP is email
    Phase 2 header said "raw units" (units are confirmed miles); MFA prompt said
    "texted to your phone" (the OTP channel is email). Cosmetic, serial-only.
    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
    [main.cpp]
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2026-07-21 Reorder phasing: LEDs last (after web/wifi/OTA)
    The 8-pixel stick hasn't arrived and the software phases don't need it, so do
    them first and finish with the light. New order: 1 auth (done) -> 2 poll (done)
    -> 3 web page -> 4 wifi provisioning -> 5 OTA+polish -> 6 LEDs. Marked phases 1
    & 2 done; fixed stale Phase-3 references.
    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
2026-07-21 Phase 4: WiFi provisioning + DHCP hostname from device name
    net_wifi module (borrowed from sonos-nest wifi.cpp + portal.cpp):
    - Device name is the single source for DHCP hostname + mDNS + AP name.
    WiFi.setHostname() is now set BEFORE the STA mode transition (arduino-esp32
    quirk documented in sonos-nest) — fixes the router showing esp32s3-XXXX.
    Verified live: host=rivian-status.
    - connect() tries NVS creds then secrets.h; on failure runPortal() raises a
    SoftAP captive portal (open AP "<name>-setup", wildcard DNS, scan-list join
    page that also sets the device name), then reboots into STA. Creds -> NVS.
    - Runtime apply(): try/persist/revert so a wrong password never strands it.
    Set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
    [main.cpp, net_wifi.cpp, webserver.cpp]
2026-07-21 Phase 5: OTA wireless updates (ArduinoOTA)
    net_ota advertises the device as <device name>.local (same source as the DHCP
    hostname), optional OTA_PASSWORD from secrets.h, progress/active exposed for the
    LED phase. Wired into the phase3 app: otaBegin() after WiFi, otaHandle() in loop.
    phase3-ota env does espota uploads:
    OTA_PASSWORD=<pw> pio run -e phase3-ota -t upload
    The password comes from the env (${sysenv.OTA_PASSWORD}), never the repo.
    Verified live: a full firmware update over WiFi (authenticated) succeeded and
    the device rebooted into it and came back online — no USB. secrets.h.example
    documents OTA_PASSWORD.
    C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
    [main.cpp, net_ota.cpp]
2026-07-22 Add Phase 6 enclosure: top-bar 3D-printed case (XIAO ESP32-S3 + 8px WS2812)
    Parametric trimesh CAD toolchain mirroring ../sonos-nest/hardware. The 8-pixel
    WS2812 stick screws to two posts stacked above the XIAO; LEDs face up through a
    window in the lid. USB-C exits the back wall (proud); U.FL antenna coils inside;
    four M3 screws hold the lid. Board numbers read off Seeed's official STEP (in
    ref/) — the XIAO has no screw mounting holes, so it's edge-retained. LED-stick
    numbers calipered off the real part.
    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
    [XIAO-ESP32S3 v2.step, lid.stl, shell.stl]
2026-07-22 Enclosure: widen lid clamp pads to straddle the USB-C shell
    The two board hold-down pads were at ±6.0 (Ø4.4), overlapping the ~9 mm USB-C
    receptacle and resting on top of it. Move them to ±6.57 and slim to Ø3.4 so they
    land on bare PCB either side of the shell (0.4 mm clear each side, 0.63 mm to the
    board edge), 13.1 mm apart. Pad Ø + X now derive from USB_SHELL_W.
    Claude-Session: https://claude.ai/code/session_01AyP9gmoeDzbHnMUUyQRugh
    [lid.stl]
2026-07-22 Enclosure: roomier box — +30% width and depth, 26 mm strip posts
    Give the strip and its soldered end-wires real working room. Widen the box ~30%
    in X (STRIP_END_GAP) so the wires clear the strip ends and the lid bosses sit well
    outside them; deepen ~30% in Y (BOARD_FRONT_GAP) with the board pushed to the back
    wall (USB-C stays proud) and the extra depth as a front bay for wires + the antenna
    coil. Strip-mount posts moved to 26 mm centre-to-centre (holes ±13.0).
    Outer size now 75.3 x 34.3 x 16.0 mm.
    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
    [lid.stl, shell.stl]
2026-07-22 Enclosure: measured LED offset — holes 4.5 mm off the row, 4.75 mm emitter
    Caliper values supersede the earlier eyeballed 1.5 mm: the strip mounting holes
    sit 4.5 mm off the LED row (LED_HOLE_DY) and each emitter is 4.75 mm square. The
    stick posts move to +4.5, putting the screws clear beside the window; STRIP_CY now
    derives so the holes land near the strip's far edge as on the real board.
    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
    [lid.stl, shell.stl]
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2026-07-22 LEDs: redesign as a single target-based meter
    Replace the per-pixel role map with one whole-strip meter filled by SoC/target:
    - link down -> pixel 0 pulses red, rest off
    - charging -> leading meter pixel pulses red (climbs), rest off
    - not charging + below target -> all pixels flash red together (plug-in alert)
    - not charging + at/above target -> all solid green
    - OTA push -> blue progress bar (unchanged)
    Meter is SoC / batteryLimit (target), not /100. Simplifies the enum reads to just
    sCharging (charging_active). Verified live. Plan §7 updated to match.
    Claude-Session: https://claude.ai/code/session_01AyP9gmoeDzbHnMUUyQR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
2026-07-22 LEDs: low-range alert keys off the threshold, not the charge target
    Correction: "all flash red" is the low-range alert (distanceToEmpty mi <
    rangeThresholdMiles), not below the charge target. Restores the resting meter for
    not-charging + range-OK: green filled to SoC/target + red empty remainder (all
    green once at target). Charging still shows the climbing leading pixel; charging
    takes precedence over the low-range flash. Plan §7 updated.
    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
2026-07-22 Web config: LED brightness control + status-page strip preview
    - Settings: ledBrightness() NVS setting (0-255, default 40), clamped [1,255].
    - /config: brightness range slider with live value readout; applied at runtime by
    leds.cpp (FastLED.setBrightness each frame) so changes take effect without reboot.
    - Status page: an 8-segment "LED strip" preview below the table mirroring
    leds.cpp render() (green fill + red empty / pulse / flash), with CSS animations.
    Verified live: slider present (value 40), status meter shows 7 green + 1 red at
    57.6%/70% target.
    Claude-Session: https://claude.ai/code/session_01AyP9gmoeDzbHnMUUy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
    [webserver.cpp]
2026-07-22 Enclosure: relief pockets in the lid over the stick screw heads
    The stick's M3 screw heads sit ~level with the LED domes (top 14.8 vs lid underside
    13.5) and were fouling the lid. Add two Ø7 blind pockets in the lid underside above
    the screws (at ±13.0, POST_CY), clearing the head top with a 0.8 mm roof left.
    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
    [lid.stl]
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2026-07-22 Add /ota skill for wireless firmware updates to the rivian-status unit
    Package the OTA workflow used this session as a project skill:
    - .claude/skills/ota/SKILL.md — build phase3, find the device IP (WSL can't resolve
    mDNS), espota-upload with OTA_PASSWORD from secrets.h, verify it came back. Notes
    the LED blue-progress-bar cue, the device-name = OTA-target rule, and the WSL
    Hyper-V inbound-firewall gotcha.
    - .claude/skills/ota/find_device.py — zeroconf mDNS discovery (default rivian-status).
    - CLAUDE.md: point the flash section at /ota.
    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
2026-07-23 Add battery-power decision doc (research/battery-power.md)
    Deep-research verdict on running the LED strip from battery: no mainstream
    ESP32-S3 board provides a battery-fed 5V rail (all are 3.3V-reg + USB-VBUS
    passthrough, same trap as the XIAO's dead-on-battery 5V pin). Fix is XIAO +
    external boost (Adafruit PowerBoost 500C/1000C). Always-on WiFi runtime is short
    (~12-20h on 2000mAh no-sleep) and sleep modes conflict with the always-on web
    UI/OTA, so the shipped appliance stays USB-powered; battery is an optional add-on.
    Includes board comparison, runtime table, wiring, open questions, sources.
    Claude-Session: https://clau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
2026-07-23 plan: record observed chargerState "charging_complete"
    Captured live at 70%/70% target while grabbing README screenshots. Reads as
    not-charging, so at/above target it correctly shows the full green meter. Removes
    "complete" from the still-needed enum list (fault/unplugged remain).
    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
2026-07-24 Add v2 wall-charger slip-case enclosure (box-v2)
    A second enclosure form factor: a one-piece slip shell that press-fits over
    a Nekmit Ultra-Thin flat wall charger (the mechanical + electrical anchor).
    AC prongs exit the open back; an inward snap lip retains the charger. The
    v1 8-px WS2812 stick mounts vertically on the front, screwed from the open
    back into hidden bosses that thread into the solid front wall. The XIAO
    rests flat on the lower skirt floor; the skirt's wall-facing back is a
    separate screw-on cover (tongue-under-tab top retention) so the main body
    prints fully open-backed with no supports in a blind pocket.
    Same trimesh-CSG toolchain as box/ (img23d env): case_params.py ->
    buil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
    [case.stl, cover.stl]
2026-07-24 docs: cover both case versions; add charger to box-v2 parts
    Update the top-level README and the hardware READMEs to describe both
    enclosure versions side by side (v1 desk box + v2 wall-charger slip case)
    instead of v1 only. Add a bill of materials to box-v2/README.md, including
    the Nekmit USB-C wall charger and the USB-A->USB-C pigtail that powers the
    XIAO, plus the two printed parts, screws, and diffuser film.
    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
2026-07-24 docs: relocate v1 MEASUREMENTS into box/, add box-v2 design NOTES
    Move hardware/MEASUREMENTS.md (entirely v1-specific) into the v1 case
    folder as box/MEASUREMENTS.md, and fix its internal + cross-file links.
    board_spec.md stays at the status-light level since both versions share
    the XIAO numbers (reworded to say so).
    Add box-v2/NOTES.md capturing this session's design reasoning for future
    sessions: the depth stack (why ~29 mm, head-relief gap, dome recess), why
    hidden-M3 stick screws force that depth (the front-sandwich analysis), the
    XIAO-on-floor + separate-cover + print-support rationale, skirt floored by
    the USB-A pigtail (not the XIAO), the tongue-under-corner-tab lip (vs a
    44 mm bridg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
2026-07-24 docs: add the v2 wall charger + pigtail to the root README parts list
    Add the Nekmit flat USB-C wall charger (the anchor the v2 case slips over,
    43.18 x 50.80 x 20.32 mm) and the USB-A->USB-C pigtail to the root Parts
    table, tagged (v2); tag the existing generic USB-C power row (v1) so the
    two power sources don't read as duplicates.
    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
2026-07-24 docs: add an Enclosures section to CLAUDE.md covering both case versions
    CLAUDE.md had no coverage of the 3D-printed enclosure work at all, so a new
    session auto-loading it had no pointer to hardware/. Add an "Enclosures"
    section: the trimesh/img23d toolchain and build command, a table of both
    versions (v1 desk box, v2 wall-charger slip case) with their printed parts,
    and a pointer to box-v2/NOTES.md for the v2 design rationale, box/
    MEASUREMENTS.md for v1 dimensions, and board_spec.md as the shared XIAO spec.
    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
2026-07-24 feat(leds): configurable mounting orientation (0/90/180/270)
    The unit is a meter and the outlet decides how it hangs, so which physical
    end reads as "the top" isn't fixed. Add an NVS-backed mounting rotation and
    have the LED map compensate for it.
    The invariant: the meter always fills toward screen-up when the stick lands
    vertical and toward screen-right when it lands horizontal. render() keeps
    drawing in logical order (index 0 = the "fill from" end) and a new
    applyOrientation() reverses the buffer afterwards, so one remap covers every
    pattern — SoC meter, charging pulse, low-range flash, link-down pixel and the
    OTA progress bar — without any effect knowing how the device is mounted.
    /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
    [webserver.cpp]
2026-07-24 fix(leds): derive the meter axis from the enclosure, not the plug alone
    v1 is mounted board-flat to the wall with the LEDs facing out, so its stick
    runs HORIZONTAL — plug-at-bottom there reads left-to-right. v2's wall case
    holds the stick vertically on the charger's portrait face. The previous commit
    assumed v2's geometry for every unit, so v1 got the axis a quarter turn out.
    Plug position alone can't settle it. Two facts are genuinely underivable, so
    make them settings instead of assumptions:
    led_vert0 is the stick vertical with the plug at the bottom? (per enclosure)
    led_inv is the meter filling the wrong way? (per unit's stick wiring)
    The second replaces the ⚠️VERIFY assu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
    [webserver.cpp]
2026-07-24 fix(net): self-heal WiFi drops so the box can't wedge until a power cycle
    Ported from sonos-nest f58573d + 37669fd, which fixed an "unresponsive after
    2-3 days" report on the same class of always-on mains-powered board.
    Net::connect() ran ONCE at boot and nothing ever re-checked the link again --
    not loop(), not pollTask(). A router reboot, DHCP renewal or AP roam (all
    near-certain over a multi-day uptime) left the unit alive-but-wedged: LEDs
    stuck on the link-down pulse, web UI unreachable, and OTA dead too, so you
    couldn't even push a fix without pulling the USB. The antenna sensitivity this
    board is known for makes it likelier still -- AUTH_EXPIRE is exactly the
    disconnect reason the fra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
    [net_ota.cpp, net_wifi.cpp, webserver.cpp]
2026-07-24 docs(readme): cover the mounting-orientation setting
    The light is a meter and the outlet decides how it hangs, so document the
    config-page control: pick where the plug comes out (four diagrams) and the
    firmware rotates the meter to suit, keeping one rule -- fills toward the top
    when it lands vertical, toward the right when it lands sideways.
    Also covers the two settings that pin it down: Enclosure (v1's bar runs across,
    v2's up-down, so the same quarter turn lands them on different axes) and the
    "meter fills the wrong way" escape hatch for per-unit stick wiring. Notes that
    v1 wall-mounts with the USB-C exit pointing down, which is how it's actually
    being used.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
2026-07-24 docs(readme): add a real-life photo of the v1 enclosure
    A built v1 unit on the wall, live at 7 of 8 cells — one short of the charge
    target, plug at the bottom, meter reading left→right. Slots into the v1
    enclosure section, which now also notes that the "desk box" wall-mounts with
    the back-wall USB-C exit pointing down (how it's actually being used) and which
    config settings that implies.
    The photo doubles as evidence for the orientation defaults: plug-at-bottom
    filling left→right is exactly what led_vert0=false / led_inv=false / led_rot=0
    predicts, which settles the "which end is pixel 0" assumption for v1 by
    observation rather than by guess (recorded in plan §7).
    EXIF stripped befo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
2026-07-24 ci: drop `cache: pip` — it hard-failed the workflow before any build
    The first tag push (v0.1.0) died in 9s at actions/setup-python: `cache: pip`
    makes the step hash a dependency file for its cache key, and this repo has no
    requirements.txt or pyproject.toml, so it errors out with "No file matched to
    [**/requirements.txt or **/pyproject.toml]" before a single line is compiled.
    Latent since the workflow was written — that tag push was its first ever run,
    so nothing had exercised the path. The one `pip install platformio` doesn't
    justify a lockfile, and the expensive caching (pinned platform, framework,
    libs) is the actions/cache step immediately below and is unaffected.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
2026-07-24 fix(ota): follow redirects during the pull-flash download
    The first live pull failed instantly: "flash failed (-104) Wrong HTTP Code".
    HTTPUpdate builds its OWN internal HTTPClient, so the
    setFollowRedirects(HTTPC_STRICT_FOLLOW_REDIRECTS) applied to the manifest fetch
    does not carry over to the firmware download. GitHub 302s a release asset to a
    signed CDN host, so HTTPUpdate saw the 302 and rejected it as a wrong HTTP code
    before transferring a byte.
    Everything either side of it was already correct -- the device fetched the
    manifest over HTTPS, compared versions, and reported "v0.1.1 available"; only
    the download leg was missing the setting.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
    [net_updater.cpp]
2026-07-24 docs: refresh screenshots and document firmware updates
    The three README screenshots predated the Health card, the mounting-orientation
    picker and the Firmware card, so they no longer showed what the device serves.
    Recaptured all three at the same 1200px width via headless Chromium.
    The WiFi SSID now rendered in the Health card is replaced with a placeholder in
    the capture: an SSID is geolocatable through wardriving databases and this repo
    is public. Nothing else in the pages was altered.
    Adds a "Firmware updates" section covering the self-update path — source
    selection, the automatic-install toggle and why it defaults off, the
    strictly-newer guarantee, dual-slot safety on an interrupted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
2026-07-24 ci: publish a merged full-flash image alongside the app binary
    Each Release now also carries firmware-status-full.bin, so a factory-fresh
    board can be brought up without the PlatformIO toolchain -- the previous gap
    where the first flash HAD to be built from source, because the app binary lands
    at 0x10000 and a blank board has no bootloader.
    The build job runs `esptool merge_bin` (pinned to 4.11.0 -- the merge_bin CLI
    changed in 5.x) to stitch the four images a cold flash needs into one flashable
    at 0x0: bootloader (0x0), partition table (0x8000), boot_app0/otadata (0xe000),
    app (0x10000). Offsets and flash args (dio / 80m / 8MB) mirror exactly what
    `pio run -t upload` issues for this board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
2026-07-25 hardware(box-v2): fit real charger dims, taller skirt, hide LED posts, drop cover tabs
    - Charger W/H re-measured (calipered): 43.18x50.80 -> 45.1x51.6 mm; the old
    blueprint numbers undersized the cavity so the shell wouldn't slip on.
    - Skirt extended 17 -> 41 mm (two +12 bumps) for the USB cable/plug off the
    charger's bottom port.
    - Front wall thickened 2.2 -> 3.2 mm and the screw-post pilot cap 0.8 -> 1.6 mm
    so the LED stick's hidden posts no longer show through the front (~3.6 mm
    thread engagement preserved; protrusion 29.1 -> 30.1 mm).
    - Removed the cover's tongue-under-corner-tab top retention (body tabs + cover
    tongue + COVER_LIP_* params/asserts); cover is now a plain 2-screw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
    [case.stl, cover.stl]
2026-07-26 hardware(box-v2): +12 skirt, align LED stick (holes 3.77mm), D-flat bosses, drop lip strip
    - Skirt extended again 29 -> 41 mm for more USB cable/plug room.
    - LED-stick horizontal alignment: measured the strip on a print jig -- the screw
    holes sit 3.77 mm off the LED-row centreline (was a rough 4.5). Stick + window
    stay centred on the case face; posts move to 3.77. 26 mm hole spacing re-confirmed.
    - D-flatten the LED screw bosses flush with the window edge so a Ø5 boss at 3.77
    clears the slot and the two nearest LEDs (screw still bites the outboard ~2/3).
    - Remove the rear snap-lip's bottom run -- a thin full-width strip across the back
    above the cover that did no retaining; top + tw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
    [case.stl, template.stl]
2026-07-26 hardware(box-v2): shift LED groove so emitters centre in the window, complete bosses
    The strip's emitter row sits toward the board's -X long edge, so centring the
    board in the groove left the LEDs off-centre under the window (partly behind the
    wall). Keep the window put; shift the groove (pocket) + posts +2.375 mm so the
    groove's -X edge meets the window's -X edge -- the emitters then land centred and
    the posts move outboard.
    - STICK_CX = (WIN_CX - WIN_W/2) + POCKET_W/2 (groove -X edge on the window edge);
    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
    [case.stl, template.stl]
2026-07-27 hardware(box-v2): centre emitters in the window (groove -1.5mm), D-flat bosses
    Measured on the mounted unit: with the groove edge-aligned the emitters landed
    1.5 mm right of the window centre, so the emitter row is 0.875 mm off the board's
    width centre (toward -X), not the 2.375 the edge-align assumed.
    - LED_EMIT_DX = -0.875 (measured emitter-row offset from the board centre);
    STICK_CX = LED_CX - LED_EMIT_DX = 0.875 -> groove/posts move 1.5 mm left so the
    emitters land on the window centre. Posts follow to x=4.645.
    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
    [case.stl, template.stl]
2026-07-27 Revert "hardware(box-v2): centre emitters in the window (groove -1.5mm), D-flat bosses"
    This reverts commit 1e1c7a7. Back to the groove edge-aligned position
    (STICK_CX = 2.375, posts at 6.145) with COMPLETE round bosses; drops the
    LED_EMIT_DX -1.5 mm emitter-centring shift and the D-flatten.
    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
    [case.stl, template.stl]
2026-07-28 hardware(box-v2): nudge groove 0.75mm left + add level-support ledge for the strip
    - Groove/posts trimmed 0.75 mm left (STICK_TRIM_X = -0.75): STICK_CX 2.375 ->
    1.625, posts to x=5.395. Halves the emitter-vs-window offset while keeping the
    bosses effectively complete -- the Ø5 boss now grazes the window edge by only
    0.08 mm (below FDM resolution), so the assert tolerates a <0.15 mm graze instead
    of forcing a D-flatten.
    - Level-support ledge on the side opposite the screw posts: the strip is clamped
    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
    [case.stl, template.stl]
2026-07-28 docs(readme): add v2 enclosure photos (front + side)
    Front (mounted, LEDs live through the window) and side (profile, charger prongs
    out the open back) shots of the v2 wall-charger slip case, in the v2 section.
    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
